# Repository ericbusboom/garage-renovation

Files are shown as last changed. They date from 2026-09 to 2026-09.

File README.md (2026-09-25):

# Garage Renovation

Working files for the garage renovation, including the controlled report, COMPAS structural data, analysis source, studies, drawings, visualizations, and renders.

| Directory | Purpose |
|---|---|
| `report/` | Controlled project report and document manifest |
| `studies/` | Dated one-off and versioned explorations |
| `data/` | COMPAS and project model data |
| `viz/` | Dated visualization releases; `viz/latest` selects the current one |
| `render/` | Dated Blender and other render packages |
| `plans/` | Approved drawings when available |
| `src/` | Active source code |
| `public/` | Static site for `garage.busboom.org` |
| `archive/` | Retained history and local tooling |

See [archive/reorganization-manifest.csv](archive/reorganization-manifest.csv) for the 2026-09-21 move record. Structural analyses in this repository are preliminary unless signed and sealed by the responsible engineer.

The current interactive frame is always available at
[`viz/latest/lean-to-frame-3d.html`](viz/latest/lean-to-frame-3d.html). Visualization
release directories use `YYYYMMDD.NN-<slug>`; see [`viz/README.md`](viz/README.md)
for revision and rollback rules.

The current large-format concept drawing set is
[`studies/20260924.02-concept-drawing-set/garage-concept-drawing-set.pdf`](studies/20260924.02-concept-drawing-set/garage-concept-drawing-set.pdf).
It combines the current frame and equipment layout with diagrammatic electrical,
Ethernet, dust-collection, and compressed-air routing. Approved drawing packages
will move to `plans/` only after review.

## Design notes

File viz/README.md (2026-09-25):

# Visualizations

Interactive and generated visualizations are published here as dated releases.
Release directories use the same naming scheme as studies:
`YYYYMMDD.NN-<slug>`.

The authoritative working release is always [`latest`](latest), a relative
symlink that can point to any retained release. Do not infer current status from
the largest version number or newest modification time. The current 3-D frame is:

- [Latest structural frame](latest/lean-to-frame-3d.html)
- [Release notes](latest/README.md)
- [Analysis results](latest/analysis.json)
- [Geometry](latest/geometry.json)

## Revision workflow

Small corrections to the active design regenerate files in the directory to
which `latest` points. A major geometry, analysis, or presentation direction
gets a new `YYYYMMDD.NN-<slug>` directory. Copy only the useful starting assets,
update that release's README and manifest, review it, and then repoint `latest`.

If a new direction is abandoned, leave its numbered directory for history and
repoint `latest` to the selected earlier release. This makes rollback explicit
and avoids treating the numerically newest release as automatically approved.

Keep `viz/` reviewable: one README and manifest per release, the visualization,
and the data needed to understand it. Solver experiments, intermediate options,
logs, screenshots, and development branches belong in `studies/` or `archive/`.
The superseded pre-versioning visualization tree is retained at
`archive/20260924.01-viz-cleanup/legacy-structural-analysis/`.

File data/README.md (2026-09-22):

# Data

- `frame-models/` contains COMPAS structural frame JSON files using the existing naming scheme.
- `model/` contains the project model, parameters, exchange files, and related model data.

Keep stable data filenames when source code or report provenance records refer to them. Put generated HTML and presentation outputs in `viz/` instead.

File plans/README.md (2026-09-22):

# Approved Plans

This directory is reserved for approved drawings, primarily orthographic, isometric, and two-dimensional plan material.

It is intentionally empty of drawings. The current controlled manifest contains no `reviewed`, `verified`, or `issued` drawing suitable for promotion here. Draft and exploratory drawings remain in `report/` or `studies/` with their existing status.

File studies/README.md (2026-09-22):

# Studies

One-off and versioned explorations live here. Directory names use `YYYYMMDD.NN-<slug>`, where the date identifies the study generation and `NN` distinguishes studies started on the same day.

Studies are working material. They do not become approved drawings or controlled design documents until promoted through `report/document-manifest.csv`.

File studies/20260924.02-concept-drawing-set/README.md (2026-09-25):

# Concept drawing set

This study assembles the current structural frame and equipment layout into one
large-format, multipage PDF for coordination and discussion. It is explicitly a
concept set, not a permit, fabrication, or construction package.

The sheets include:

- isometric, north, east, and south structural views;
- loft and ground-floor equipment plans;
- conceptual electrical distribution;
- conceptual Ethernet home runs; and
- conceptual dust collection and compressed-air distribution.

Regenerate from the repository root with:

```sh
archive/.venv/bin/python src/structural-analysis-v6/drawing_set.py \
  studies/20260924.02-concept-drawing-set/garage-concept-drawing-set.pdf
```

The MEP routes record proposed endpoints and zones. Final circuiting, conductor,
cable, pipe and duct sizing, clearances, supports, and code compliance remain to
be designed and verified.

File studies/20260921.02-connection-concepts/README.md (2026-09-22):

# Connection concept and model audit

**Status:** preliminary discussion basis; no connection is designed or approved for fabrication.

## What the current analysis actually assumes

The current lean-to/continuous-east-post model contains 127 physical members, 334 geometric nodes, 11 supports, and 38 short analytical links used to transfer load across offsets.

- 54 wood joists, 22 steel rafters, and 6 steel braces are pin-ended: 82 members and 164 released member ends.
- Two steel door-post heads and four support locations along `BE.upper` are explicitly released in addition to the group rules.
- All 11 modeled foundations are pinned bases: translation is restrained and rotation is free.
- Every other connected analytical member end transfers moment. This is a modeling assumption, not evidence that a weld, end plate, or moment connection has been designed.
- No bolt quantity, screw quantity, weld size, plate thickness, hole type, edge distance, block shear, local HSS wall, flange, anchor, or base-plate check exists.

The cost model counts 109 fitted steel ends and prices them as roughly 55 field-bolted connection locations. It also allows shop fitting and welding at steel ends and shop-welded end plates on 13 W-shape pieces. These are estimating allowances, not a connection schedule.

## A practical connection split

### Shop-welded lateral modules

The current explicit designation starts with two ground-to-floor longitudinal moment frames:

- west `BW` line: `BW`, `SW0`, `W1`, `W2`, `W3`, and `W4`;
- east `BE` line: `BE`, `E-S2`, `E-S3`, and `E-N2`.

These are the red members in the viewer. They are a design intent that still requires connection and foundation engineering; the red color does not mean their joints have already been checked. Use shop welding to make transportable frame modules where those lines need continuity, with deliberate field splices selected to suit erection and shipping.

The upper roof and clerestory members are not automatically included in those moment frames. Most are amber in the viewer because the solver presently transfers moment through them even though their lateral role has not been selected. Each amber end must be released, assigned to a braced bay, or deliberately designed as part of a moment-resisting frame.

Do not assume every intersection in these panels must be a full-strength moment weld. Diagonals can still terminate on shop-welded gusset plates with pinned analytical behavior. Chord-to-column or chord-splice locations that provide frame stiffness need explicit moment-connection design.

### Field-bolted simple connections

- Wood joists: proprietary hangers or designed ledgers/hangers; simple ends.
- Steel rafters: seated or shear-tab connections with positive uplift restraint and rotational freedom.
- Braces: bolted gusset plates, detailed so brace work lines meet at the joint.
- `BE.upper`: bolted simple shear/seat connections at its four supports, matching the existing releases.
- Door-post heads: bolted clip or knife plates that restrain translation while allowing the modeled rotation.
- Column bases: base plates and anchor rods designed as nominally pinned bases unless the lateral design deliberately changes them.

### Field splices between welded modules

Use bolted flange/web plates or end plates at deliberate shipping and erection breaks. These can be simple or moment-resisting, but the analysis must match the selected behavior. A connection should not be called “slip” if the structure relies on it to hold geometry: use a simple rotational connection, a bearing-type bolted joint, or a slip-critical joint as the actual load path requires. Slotted holes are useful for erection tolerance only where their allowed movement cannot create a mechanism or unload a brace.

## The main structural consequence

The current reduced-bracing model assumes moment continuity at all joints that are not explicitly released. Converting those remaining joints wholesale to simple bolted connections would remove stiffness that the H/414 drift result depends on. Before detailing, choose and model the lateral system explicitly:

1. identify the welded/moment-resisting frame planes;
2. keep gravity infill, rafters, joists, and brace gussets simple where possible;
3. place field splices to make the welded modules transportable and erectable;
4. rerun strength, drift, second-order, and pre-demolition stability with those releases;
5. design plates, bolts, welds, anchors, and HSS local reinforcement from the resulting connection forces.

The present force results support treating `BW` as an active lateral member: it is wind-governed under the `WX-.ni` combination, with about 137 kip-in of major-axis moment and a 0.515 checked ratio. The east `BE` beam is gravity-governed at 0.608, while its three designated posts are governed by earthquake or gravity combinations. That means the east red frame is an intentional stability/redundancy choice, not a classification inferred from `BE`'s governing load case.

There are 29 amber members. Until a released-joint rerun passes, the reported H/414 drift belongs to the current partly implicit rigid-joint model; it is not proof that the two red frames alone provide that stiffness.

## Pre-demolition correction

`B-S` and `E.top` clear the existing roof and remain in the early erection stage. `E.top` is shown with its real support chain: the continuous `E.clerestory` and `E.W3` east wall-line posts. Those posts require local work at the existing east eave, but they do not require removal of the roof field. The phase filter continues to prune an asserted member if its supporting members are absent, so `E.top` cannot appear as a floating beam.

The preferred fabrication direction is therefore **a small number of shop-welded lateral modules with many field-bolted simple attachments**, rather than welding the whole building together in the field or treating every joint as free to rotate.

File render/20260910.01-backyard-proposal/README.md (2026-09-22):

# Backyard with proposed hip-cap garage

This proposal starts from the exact `backyard-existing.blend` embedded in the supplied `backyard-blender/Backyard-Blender-Package.zip`, rather than the older approximate garden scene.

The source backyard remains intact except for removal of its existing garage roof. Proposed columns, beams, upper walls, loft floor, balcony and current roof are inserted from `garage-model.json`. Both models use metres, X east, Y north, Z up, with the same southwest garage origin, so no translation or rescaling is applied. The lower garage walls and original work shelter are retained without duplicate geometry.

The rear hip cap rises 18 inches above its eaves with an 8-inch overhang and white soffit/fascia. Proposed structural sizes and connections remain conceptual. The combined model exposes spatial relationships; it does not establish foundations, load capacity or clearance compliance.

## Contents

- `backyard-proposed-hip-cap.blend`: editable Blender scene, with packed baseline photographic textures and named PROPOSED collections.
- Three PNG renders: whole-yard overview, patio toward garage, elevated west.
- `build_proposal.py`: inserts the proposal into the baseline and reproduces all three renders with Blender 5.
- `backyard-existing.blend`: unchanged source scene extracted from the supplied ZIP.
- `garage-model.json`: current proposed garage mesh geometry, materials and dimensions.
- `validation.json`: source hash, removed roof object names, added object count and coordinate basis.

Run `blender -b -t 12 --python build_proposal.py` from this directory. Rendering uses Cycles CPU, 80 samples with denoising, 1800 × 1350 pixels. The original backyard package is preserved separately. The backyard itself remains a reviewed visual reconstruction, with the dimensions and limitations documented in the original package; it is not a survey.

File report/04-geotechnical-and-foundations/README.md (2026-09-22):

# 04 — Geotechnical and Foundations

This section establishes the ground conditions and parameters needed to design new columns, piers, footings, slabs, and any retained foundation reliance. It must address fill, expansive soil, groundwater, settlement, lateral resistance, uplift, corrosion, mapped hazards, excavation, and drainage as applicable.

Early assumptions such as 18-inch-diameter by 36-inch-deep piers are not design values.

## Required outputs

- geotechnical report or documented City-acceptable basis for not requiring one
- foundation design criteria
- excavation, observation, testing, and special-inspection requirements
- foundation schedule coordinated with structural reactions

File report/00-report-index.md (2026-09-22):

# Garage Rebuild — Master Report Index

**Project:** Garage rebuild and loft/solar superstructure  
**Site:** 1370 Wilbur Avenue, San Diego, CA 92109  
**Document status:** Draft report framework  
**Purpose:** Design development, professional coordination, permitting, bidding, construction, and closeout  
**Last updated:** 2026-09-21

## How the document set works

The report has three layers:

1. **Project record:** decisions, assumptions, existing conditions, analyses, and design narrative.
2. **Permit and construction set:** coordinated drawings, specifications, calculations, and agency responses prepared for a stated issue.
3. **Record documents:** approved permits, inspections, submittals, testing, warranties, and as-built information.

The Markdown index is the navigable table of contents. PDFs and images provide fixed review copies. Native CAD and exchange models provide editable geometry. The manifest records status and provenance for every controlled artifact.

The project workspace was reorganized on 2026-09-21 into `report/`, `studies/`, `data/`, `viz/`, `render/`, `plans/`, `src/`, and `archive/`. This changed file locations and provenance links only; it did not change the status or technical conclusions of any controlled document.

## Table of contents

| Section | Content | Principal outputs | Current state |
|---|---|---|---|
| [00 Project controls](00-project-controls/) | Document requirements, decisions, assumptions, open issues, revision and issue history | Registers, responsibility matrix, issue checklist | Draft framework |
| [01 Project definition](01-project-definition/) | Owner goals, scope, selected scheme, performance criteria, budget, exclusions, success measures | Project brief, basis of design, room/use schedule | Planned |
| [02 Existing conditions](02-existing-conditions/) | Boundary/topographic survey, measured garage, photos, utilities, power lines, drainage, vegetation, condition assessment, permit history | Survey, existing plans/sections, photo log, utility plan, hazardous-material screening | Source candidates identified; unverified |
| [03 Land use and permitting](03-land-use-and-permitting/) | Parcel data, title/easements, base zone, community plan, coastal and other overlays, setbacks, height, lot coverage/FAR, parking/use, permit path | Zoning and code summary, parcel/overlay exhibit, permit matrix, agency meeting record | LAND-005 draft findings completed; survey and agency interpretations pending |
| [04 Geotechnical and foundations](04-geotechnical-and-foundations/) | Geologic hazards, soil/fill conditions, investigation need, bearing/lateral criteria, excavations, new piers/footings, existing slab limitations | Geotechnical report or waiver basis, foundation criteria, footing/pier schedule | Planned |
| [05 Architectural design](05-architectural-design/) | Selected massing, floor plans, roof plan, elevations, sections, doors/windows, balcony/loading opening, access, finishes | Design narrative, dimensioned drawing set, door/window/finish schedules, renderings | ARCH-006 rev 4: floor-plan and east-wall study; draft |
| [06 Structural engineering](06-structural-engineering/) | Design criteria and loads, load paths, global analysis, truss/beam/column design, trolley/hoist effects, connections, foundations, temporary stability | Structural basis, calculations, framing plans, member and connection schedules | STR-007 rev 0: frame FEA, gravity, wind and seismic screening; STR-006 geometry retained |
| [07 Building envelope](07-building-envelope/) | Integrated solar roof, low hip cap, metal wall panels, waterproofing, flashing, drainage, insulation, condensation, ventilation, fire exposure | Envelope sections/details, product requirements, drainage plan | ENV-003 rev 0: wall panel options research; draft |
| [08 Solar, electrical, and energy](08-solar-electrical-and-energy/) | Solar resource, array geometry, PV/ESS sizing, production, tariff/economics, one-line, equipment and interconnection | Energy report, array layout, electrical one-line, equipment schedule, utility/permit documents | SOL-001 rev 1: consolidated solar/battery report and 30°/35°/40° analysis; draft |
| [09 MEP and life safety](09-mep-and-life-safety/) | Electrical distribution, lighting/receptacles, ventilation, any mechanical/plumbing, alarms, egress, guards, fire separation, exterior access | MEP/life-safety plans, schedules, code analysis | Planned |
| [10 Construction planning](10-construction-planning/) | Existing-roof retention sequence, demolition, temporary bracing/shoring, access, crane/hoist operations, neighbor/site protection, inspections | Phasing drawings, temporary works criteria, logistics plan, inspection/test plan | Preliminary feasibility studies exist |
| [11 Cost, schedule, and procurement](11-cost-schedule-and-procurement/) | Quantity takeoff, alternatives, fabrication/erection strategy, allowances, contingency, schedule, long-lead items | Estimate, bid scope, schedule, procurement register | Planned |
| [12 Permit and construction set](12-permit-and-construction-set/) | Coordinated issued drawings, specifications, calculations, forms, deferred submittals, plan-check responses | Permit issue and construction issue packages | Not started |
| [13 Record documents](13-record-documents/) | RFIs, submittals, substitutions, inspections, tests, change record, as-builts, commissioning, warranties | Closeout and owner record package | Future |
| [Appendices](appendices/) | Source register, calculations/data supporting the narrative, meeting notes, selected option comparisons | Reference material with provenance | Planned |
| [Deliverables](deliverables/) | Frozen, coordinated packages assembled for a named issue | ZIP/PDF/model packages and checksums | Empty by design |

## Chapter 3 research record

[LAND-005 — Setbacks, retained garage, and proposed storage roof](03-land-use-and-permitting/setbacks-and-roof-findings.md), revision 0, 2026-09-15, status `draft`. The 15-foot side-strip roof is a conditional option requiring City interpretation, not an approved limit for this project.

[LAND-006 — Extending the garage along the existing 1-ft side setback](03-land-use-and-permitting/setback-extension-research.md), revision 0, 2026-09-20, status `draft`. Two code routes allow the 1-ft line to continue, but nothing above one story may sit inside the setback under either.

## Required professional contributions

The exact contracting arrangement remains open, but a complete package is expected to need these roles:

| Role | Expected responsibility |
|---|---|
| Owner | Program, storage and equipment loads, budget, operational constraints, decisions |
| Architect or residential designer | Code/zoning coordination, architectural plans and details, consultant coordination |
| California-licensed land surveyor or civil engineer | Property boundary, topography, improvements, easements and survey control |
| California-licensed structural engineer | Structural design, existing-condition reliance, foundations, connections, temporary stability |
| Geotechnical engineer/geologist, if required | Soil/geologic investigation and design parameters |
| Electrical/solar designer and contractor | PV, ESS, service/load study, one-line, equipment, interconnection |
| Civil/drainage professional, if triggered | Grading, drainage, stormwater, utility work |
| Arborist, if tree work or protected/public trees are affected | Tree condition, root/canopy impacts and protection plan |
| General contractor and fabricator/erector | Constructability, sequencing, cost, shop drawings and field verification |

## Immediate collection priorities

1. Obtain a boundary/topographic survey showing the garage, house, outbuilding, property lines, easements, grades, trees, overhead/underground utilities, and adjacent improvements.
2. Obtain the City parcel/zoning/overlay report and permit history for the address; verify the owner-stated 5-foot setback before fixing the building envelope.
3. Obtain the building/fire classification for the owner-confirmed upstairs storage use; document loads and access requirements.
4. Complete a measured existing-condition set and structural condition assessment, including the slab, walls, foundations, roof framing, and prior lofts.
5. Confirm whether a geotechnical investigation is required and establish design parameters for every new column footing or pier.
6. Freeze one architectural scheme and one coordinated structural grid before promoting CAD files to the report.
7. Establish roof, loft, equipment, hoist, wind, seismic, and construction loads in a signed structural design basis.
8. Coordinate drainage, waterproofing, fire separation, ventilation, egress, balcony/loading opening, PV, ESS, and utility clearances.

## Current design direction — owner-provided, not yet issued

The working direction is a lightweight steel superstructure constructed around the existing garage, with an upper storage level, integrated south-facing solar roof, low hipped rear cap, exposed exterior steel frame, and metal wall panels placed inside the frame. The design includes concentrated equipment storage and a nominal 1,000-pound trolley/hoist requirement. The owner confirms all existing garage walls remain exterior and new posts stand over open ground-level walkways. Geometry, legal occupancy classification, loads, member sizes, foundations, and construction sequence remain subject to coordination and professional design.

## Regulatory note

Current City guidance indicates that structural work supporting PV and construction of a new or modified accessory structure requires building review in addition to electrical requirements. City guidance also makes the need for a geotechnical investigation dependent on code triggers, mapped hazards, fill/expansive soil, and field conditions. Exact zoning, coastal status, setbacks, height, and other parcel controls must be verified for this address before design criteria are treated as fixed.

## Chapter 8 research record

[SOL-001 — Solar, battery and roof design](08-solar-electrical-and-energy/solar-energy-report.pdf), revision 1, 2026-09-15, status `draft`. Includes all recovered solar figures, historical reports, monthly data, new pitch and loft-envelope comparisons, battery dispatch and financial sensitivity. The current 325 ft² face supersedes the older 401 ft² area assumption for this study. Recommendation for review: about 5.6–6.0 kW plus one 13.5 kWh battery; develop 35° while retaining 30° as the height-constrained alternative. [Chapter navigation and source archive](08-solar-electrical-and-energy/README.md).

## Chapter 5 floor-plan study

[ARCH-006 — Combined floor plan study](05-architectural-design/floor-plan-study/floor-plan-study.pdf), revision 4, 2026-09-15, status `draft`. One plan shows the structure, columns, possible ground-floor extension, north door bay and optional east-wall framing. [Editable drawing and source notes](05-architectural-design/floor-plan-study/README.md). Duplicate sheets and old report copies removed at owner request; current generator: `../studies/20260915.04-floor-plan-setbacks/draw_floor_plan_study.py`.

## Chapter 6 frame geometry study

[STR-006 — Coordinated frame geometry study](06-structural-engineering/frame-geometry-study/README.md), revision 0, 2026-09-15, status `draft`. [3D viewer](06-structural-engineering/frame-geometry-study/model-3d.html) · [Drawing and truss study PDF](06-structural-engineering/frame-geometry-study/frame-geometry-study.pdf). Includes the far-west truss correction, all 13 columns, east transverse links and E-OB; model data and schedules are saved for subsequent engineering. Section sizes, loads, foundations and joint design remain unresolved.

## Chapter 6 frame finite element analysis

[STR-007 — Frame finite element analysis and member optimisation study](06-structural-engineering/fea-study/structural-analysis.md),
revision 0, 2026-09-18, status `draft`.
[Interactive 3-D model](06-structural-engineering/fea-study/fea-model-3d.html) ·
[Design load basis](06-structural-engineering/fea-study/design-load-basis.md) ·
[Member schedule](06-structural-engineering/fea-study/member-schedule.csv).

First analysis of the frame against design loads: 27
ASCE 7-16 combinations covering gravity, 96 mph wind
from four directions, and a seismic screening check. Vertical equilibrium closes
exactly and member capacities reconcile with the AISC Manual.

Three blocking findings. The flat upper roof has no framing across it and the
clerestory head has no beam, so the frame as drawn cannot carry its roof. One
column is connected only by a bearing joint carried on no member. Six X-brace
crossings are not declared joints, and connecting them alone drops the worst
utilisation from 4.46 to 1.56 at no
material cost. The loft joists fail at the code storage live load of 125 psf
though they pass at the project's assumed 40 psf, which makes the occupancy
classification a structural question.

No connection, base plate, anchor or foundation is designed or checked.
Preliminary engineering only; not for construction.

## Chapter 6 cost reduction

[STR-008 — Frame cost reduction study](06-structural-engineering/cost-reduction/cost-reduction-study.md),
revision 1, 2026-09-18, status `draft`.
[Interactive 3-D model, true section sizes](06-structural-engineering/cost-reduction/cost-reduction-3d-solid.html).

Scores changes to the frame in dollars rather than pounds, on the project's own
procurement rates. Steel is $0.77–0.94/lb, so weight is the cheapest thing in the
frame; fitted joints are $16–39 each and each distinct section carries $150–400 of
procurement. The verified package removes 14 steel members and collapses eleven
distinct sections to five: 59 pieces instead of 73, 106 joints instead of 135,
**$5,630**, with the frame at 0.951 of capacity and wind drift improved to H/514.

**No floor joist can be deleted** — at 15.4 in. centres any deletion exceeds the
24 in. span of the OSB deck. Fewer joists is available only by re-spacing to
2×10 at 24 in., worth about $1,000 and requiring its own verification. Revision 0
proposed deleting 33 joists in error; see §11 of the study.

## Chapter 7 wall panel research

[ENV-003 — Infill wall panel options](07-building-envelope/wall-panel-options/wall-panel-options.md), revision 1, 2026-09-17, status `draft`. Owner-directed survey of metal, translucent, glazed and non-metal infill materials, with installed-cost ranges, the continuous-face versus bay-infill attachment decision, and whether the panels should be recruited for lateral stiffness. [Study notes and findings](07-building-envelope/wall-panel-options/README.md).

Four findings bear on decisions already recorded. Insulated metal panels cannot act as shear walls, so retaining the current 2-inch IMP basis closes the rigidity question in favour of the frame. No bay clear width is a whole multiple of any standard panel width, so tongue-and-groove products suit continuous inside-face installation rather than bay-by-bay infill. Published Galvalume warranties exclude sites within 1,500 feet of salt water, which may disqualify the default substrate at this address and makes painted aluminum the warrantable choice. The 5/8-inch Type X drywall in the working estimate may also be serving as the Chapter 26 thermal barrier and should not be deleted as redundant insulation. Raises ENV-OI-01 through ENV-OI-08. No product is selected and no price is a quotation.

Revision 1 carries the coastal-corrosion finding through to the roof (study section 8A). The standing seam in [COST-ESTIMATE.md](../COST-ESTIMATE.md) item G names no substrate, and Galvalume is what its $6.00-9.00/sq ft price point implies. The roof is the harder case: it is the outermost surface, roughly 84% of the south face sits under PV modules where rain never rinses the salt away, and panels under a fixed array cannot be replaced without removing the array. Position for review is painted aluminum with a coastal-rated paint warranty, 316 stainless clips and fasteners, aluminum or stainless gutters, non-penetrating seam clamps, and isolation pads at dissimilar-metal contacts, at a roof-subtotal delta of roughly $1,065-2,397. Adds ENV-OI-09 through ENV-OI-12.

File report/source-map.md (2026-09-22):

# Working Source Map

This map points to useful material in the workspace. It does **not** declare these files current, verified, or approved. Promote only after coordination under the report README.

| Subject | Working location | Candidate material | Caution |
|---|---|---|---|
| Existing garage CAD | `../data/model/` | `garage.FCStd`, `garage-existing.step`, parameters and validation | Field dimensions and current completeness require review. |
| Existing backyard/site | `../render/20260908.01-existing-site/` | `existing-backyard.FCStd`, `site-plan.png`, `site-review.pdf`, tree/site images | Model is photo-derived/working geometry, not a boundary survey. |
| Current exposed-frame concept | `../studies/20260911.01-structural-optimization/exposed-frame/` | `Garage-Exposed-Steel.FCStd`, STEP, Blender model, two renders | Preliminary member selections and geometry; coordinate with current roof concept. |
| Roof options | `../studies/20260915.01-roof-options/` | `south-post-solar-clerestory.*`, west elevation options | Alternatives and recent concept work; no permit status. |
| Structural optimization | `../studies/20260911.01-structural-optimization/` | candidate reports, network analysis, truss submodels | Multiple iterations exist. Do not promote by filename or date alone. |
| Truss analyses | `../studies/20260908.03-structural-analysis-v3/`, `../studies/20260909.02-structural-analysis-v5/` | design images, load plans, calculations, CSV/JSON results | Preliminary; geometry and connections have changed; professional validation required. |
| Construction sequence | `../studies/20260909.03-construction-sequence/`, `../studies/20260909.04-roof-first-feasibility/` | roof-clearance and staged T1 studies | Feasibility studies only; temporary works require engineered design. |
| Solar/energy | `../studies/20260915.03-solar/optimization/results/` | optimization PDF, charts, CSVs, summary JSON | Update tariff, costs, final roof geometry, shading, equipment, and consumption data before issue. |
| Site-context renders | `../render/20260908.02-backyard-existing/`, `../render/20260910.01-backyard-proposal/`, `../render/20260908.03-garage-site/`, `../render/20260907.01-site-concepts/` | Blender packages and renderings | Illustrative; several generations of building design exist. |
| Wall panel and glazing research | (desk research, no working directory) | `../report/07-building-envelope/wall-panel-options/` | Published manufacturer and trade sources accessed 2026-09-17. Prices are market ranges, not quotations. No samples, mockups or quotes obtained. |
| Published wiki | `../archive/wiki-publish/` | HTML content and copied deliverables | Publication mirror/archive; not the design source of truth. |

## Candidate files for first coordinated package

The following are useful starting points, but none are automatically accepted as the current deliverable:

- Existing reference model: `../data/model/garage.FCStd` and `../data/model/garage-existing.step`
- Proposed-frame editable model: `../studies/20260911.01-structural-optimization/exposed-frame/Garage-Exposed-Steel.FCStd`
- Proposed-frame exchange model: `../studies/20260911.01-structural-optimization/exposed-frame/Garage-Exposed-Steel.step`
- Recent roof concept drawing: `../studies/20260915.01-roof-options/south-post-solar-clerestory.pdf`
- Preliminary solar report: `../studies/20260915.03-solar/optimization/results/Garage-Solar-Optimization.pdf`
- Preliminary truss calculation package: `../studies/20260908.03-structural-analysis-v3/truss-design-and-calculations.pdf`

Before promotion, reconcile the proposed-frame CAD with the selected roof, current truss geometry, loft dimensions, openings, balcony/loading concept, and latest structural load model.

## Chapter 3 research provenance

LAND-005 is the draft synthesis at `03-land-use-and-permitting/setbacks-and-roof-findings.md`. Its source table records official references and access dates; its local-source list identifies the inspected studies. These links do not promote the working drawings or certify their dimensions.

## Consolidated solar record

SOL-001 revision 1 is now assembled in [Chapter 8](08-solar-electrical-and-energy/README.md). Its source archive preserves the solar studies and related roof-option sources, with a checksummed inventory. Reproduction code is in `../studies/20260915.03-solar/chapter8/`. Historical capacity estimates based on about 401 ft² do not establish fit on the newer 325 ft² solar face.

## Floor-plan study provenance

[ARCH-006 — Combined floor plan study](05-architectural-design/floor-plan-study/floor-plan-study.pdf), revision 4, 2026-09-15, status `draft`. One plan shows the structure, columns, possible ground-floor extension, north door bay and optional east-wall framing. [Editable drawing and source notes](05-architectural-design/floor-plan-study/README.md). Duplicate sheets and old report copies removed at owner request; current generator: `../studies/20260915.04-floor-plan-setbacks/draw_floor_plan_study.py`.

## Coordinated frame geometry provenance

STR-006 revision 0 is saved in [Chapter 6](06-structural-engineering/frame-geometry-study/README.md). Working generators and pinned dependencies remain in `../studies/20260917.01-compas-frame/`; the report source inventory records their hashes and those of the floor-plan basis, framing register, original model and dimension sources. Owner-directed corrections in STR-006 develop ARCH-006 but do not revise that earlier architectural sheet.

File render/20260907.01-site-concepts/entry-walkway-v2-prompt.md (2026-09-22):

# Entry and covered walkway revision

Built-in image_gen edit. Output: flat-cap-balcony-entry-v2.png. White covered walkway geometry is approximate because vegetation conceals it in reference photos. Ground-floor entry replaces the extra south window in v1. CAD remains unchanged.

Use case: precise-object-edit. Revise input1 architectural garden rendering with ONLY the missing ground-floor pedestrian door and existing white covered walkway. Input2 and3 are original site photographs for supporting context, NOT roof-design references. Preserve input1 exactly in all other respects: flat rear roof cap, solar slope, balcony and upper French doors, single offset natural wood west beam row, sloping lattice, blue-gray paint, garden, lighting, neighboring buildings, wires, perspective and composition.
On the SOUTH wall, the right-facing visible ground-floor facade directly below the solar roof, there are erroneously TWO windows in input1. Retain the LEFT window of these two near the corner; replace the RIGHT window with a normal single ground-floor pedestrian entry door, white-painted with simple white trim, about32inwide80inhigh, its lower portion naturally concealed by foreground plants. This is separate from the upper balcony French doors which stay unchanged.
Restore a modest WHITE COVERED WALKWAY by this ground-floor door extending to the RIGHT behind the dense bushes, consistent with partly visible existing pale support structure among the bushes in the site photos. Simple narrow white-painted canopy with white posts and beams and a lightly pitched solid pale cover at ground-floor eave level, lower than the main solar roof. Its near end shelters the entry and its continuation disappears behind existing greenery to image right. It is NOT the natural timber lattice on the left west side; keep those distinct. Do not clear shrubs for visibility, do not invent a large veranda or wide porch, no new paving, no new wing or room. Show just enough white canopy fascia and supporting post glimpses to convey a sheltered path behind bushes. Treat concealed dimensions as conceptual approximation. No added text, labels, dimensions or watermark. One photorealistic landscape image matching input1.

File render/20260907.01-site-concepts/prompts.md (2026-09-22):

# Garage site appearance studies

Built-in image_gen tool; compositing mode. Selected direction: flat rear cap; continuous-slope option dropped. Current image: flat-cap-balcony-v1.png.

Current concept uses one west post/beam row 32 inches from the existing wall, replacing both prior rows. Interpretation for this preview: lattice projection reduces to 32 inches as well. Balcony is a tentative shallow ornamental plant balcony, about 18 inches deep and 5 feet wide, with French doors at the northern end of the west loft wall. These balcony dimensions are visualization assumptions, not user-approved dimensions.

Photographic concepts are approximate. The generated image retains an extra south window and stylizes roof fascia; neither is an approved change to the measured model. Existing CAD and prior dimensioned roof studies have not been revised for this new concept.

## Current rendering prompt

Use case: compositing. Produce one revised photorealistic garden-view concept rendering of a garage remodel.
Input 1 is an earlier on-site rendering, EDIT TARGET. Preserve its camera, garden, bench, paths, trees, camper, neighboring buildings, sky, power lines, and garage footprint. Input 2 is the authoritative roof GEOMETRY reference, not a site background. Input 3 is the original site photo, authoritative for existing lower window positions. Input 4 is house style reference, blue-gray exterior and white French doors/trim.
The client SELECTS ONLY the flat rear cap roof concept. Correct the earlier rendered silhouette: the broad south-facing solar roof rises at30degrees from the low front/south eave, then visibly breaks into a nearly flat roof across the BACK northernmost6ft6in. NOT a continuous shed wedge, NOT a gable, NOT a tiny ridge cap. Reference2 shows this exactly. The left silhouette must have two distinct segments: shallow rear cap over about one third the north-south depth, then30degree south slope. Roof maxheight about19ft4in; existing walls8ft2.5in. Keep low south roof starting on beam23.25in beyond south wall and north upper wall/roof6in beyond existing northwall.
Requested changes to WEST side (left visible wall):
Replace BOTH old parallel north-south post/beam rows with ONE longitudinal timber post/beam row, centered32in outward from existing WEST garage wall. Delete the old row directly against west wall and old row5ft out. Show only ONE offset row, reducing the projection to32in in this concept. Beam at existing wall-top region; open2x2 sloping trellis members6–8in apart rise inward from this single beam to roof. NO solid canopy roof.
Break up the tall blank loft cheek wall with a shallow ornamental plant balcony and a pair of white painted French doors opening from loft. Place doors in the taller NORTHERN / BACK portion of the west wall beneath the flat cap, where door height fits, NOT low southern roof. A modest about5ftwide and18in deep Juliet-style plant balcony with slender dark metal vertical railing and planters of trailing greenery. Balcony floor at loft floor level about9ft above grade. Keep balcony and doors visually accessible, interrupt local trellis in front of balcony so slats do not block doors, while retaining trellis on the remaining west elevation. No people, no huge terrace, no ground-floor French doors. Blue-gray horizontal siding on the upper cheek wall, blue-gray stucco below, white door/window trim and fascia; warm wood frame and lattice. Lower windows follow original site photo: two on LEFT westwall, ONE on right southwall, do not duplicate windows. Preserve existing garden plants and other site details.
Photorealistic architectural appearance study with realistic shadows, matching original natural light. One landscape image, no labels/text/dimensions.

## Earlier option A prompt

Use case: compositing. Create a photorealistic on-site architectural concept rendering.
Input 1 IMG_4201.jpg is the EDIT TARGET: preserve its exact garden camera position, framing, paving, bench, foreground leaves, plants, camper at left, wood outbuilding at left, tan neighboring house and overhead utility wires. Replace only the white garage with gray hip roof at center-right with the proposed remodeled garage, retaining its existing ground floor footprint and window positions.
Input 2 IMG_4198.jpg and input 3 IMG_4200.jpg are HOUSE STYLE references ONLY: blue-gray painted stucco, blue-gray horizontal lap siding, crisp simple white fascia/window trim, charcoal roofing. Do not insert these houses into the scene.
Input 4 is GEOMETRY reference of the proposed garage seen from southwest, same approximate direction as site camera but elevated. Translate this precise roof and sloping open lattice form into the site photo's lower camera perspective.
Orientation: the garage's left visible face with TWO small windows is WEST; right visible face with ONE small window is SOUTH (entry door may be obscured by vegetation). North is back away from camera. Solid solar roof is low at south/front and rises toward north/back. No conventional gable or pyramid.
Existing walls are 8ft 2.5in tall and approximately 20ft9in square. New frame wraps outside them. South roof starts on outer beam 23.25in beyond existing south wall; north roof and upper loft wall extend 6in beyond existing north wall. West OPEN sloping lattice covers a 5ft walkway outside existing west wall, anchored on posts and a low outer beam around 8ft10in above ground and rising inward to west edge of solid roof. Thin 2x2 wood lattice members 6-8 inches apart; daylight clearly visible through lattice, never a solid roof. Closed blue-gray upper loft wall behind lattice at existing west wall plane. Preserve original small ground floor windows. Main broad central roof faces SOUTH with flush dark solar panels, narrow steep eastern roof plane taking max 3ft at north side, largely hidden from this camera. Keep roof proportions from geometry reference. Finish lower garage stucco blue-gray matching house, upper loft cheek wall blue-gray horizontal siding, clean white fascia and white window trim; exposed frame and lattice warm natural wood. Roofing charcoal gray, no new dormers, balconies, large glazing, or extra floors. Preserve lush site plants and natural afternoon illumination, realistic material detail, shadows and perspective. No text, labels, dimensions, collage, or watermark. Output one landscape image.
VARIANT A: exactly the roof in input 4: south-facing 30 degree roof over front portion, transitioning to a nearly flat cap over the northernmost 6ft6in. Maximum roof height about19ft4in above ground. The rear cap is a broad shallow roof segment, not a second pitched face or ridge. Preserve the geometry reference's distinctive broken west roof edge and lattice, which follows the main slope then rear shallow cap.

## Dropped option B prompt

Use case: compositing. Create a photorealistic on-site architectural concept rendering.
Input 1 IMG_4201.jpg is the EDIT TARGET: preserve its exact garden camera position, framing, paving, bench, foreground leaves, plants, camper at left, wood outbuilding at left, tan neighboring house and overhead utility wires. Replace only the white garage with gray hip roof at center-right with the proposed remodeled garage, retaining its existing ground floor footprint and window positions.
Input 2 IMG_4198.jpg and input 3 IMG_4200.jpg are HOUSE STYLE references ONLY: blue-gray painted stucco, blue-gray horizontal lap siding, crisp simple white fascia/window trim, charcoal roofing. Do not insert these houses into the scene.
Input 4 is GEOMETRY reference of the proposed garage seen from southwest, same approximate direction as site camera but elevated. Translate this precise roof and sloping open lattice form into the site photo's lower camera perspective.
Orientation: the garage's left visible face with TWO small windows is WEST; right visible face with ONE small window is SOUTH (entry door may be obscured by vegetation). North is back away from camera. Solid solar roof is low at south/front and rises toward north/back. No conventional gable or pyramid.
Existing walls are 8ft 2.5in tall and approximately 20ft9in square. New frame wraps outside them. South roof starts on outer beam 23.25in beyond existing south wall; north roof and upper loft wall extend 6in beyond existing north wall. West OPEN sloping lattice covers a 5ft walkway outside existing west wall, anchored on posts and a low outer beam around 8ft10in above ground and rising inward to west edge of solid roof. Thin 2x2 wood lattice members 6-8 inches apart; daylight clearly visible through lattice, never a solid roof. Closed blue-gray upper loft wall behind lattice at existing west wall plane. Preserve original small ground floor windows. Main broad central roof faces SOUTH with flush dark solar panels, narrow steep eastern roof plane taking max 3ft at north side, largely hidden from this camera. Keep roof proportions from geometry reference. Finish lower garage stucco blue-gray matching house, upper loft cheek wall blue-gray horizontal siding, clean white fascia and white window trim; exposed frame and lattice warm natural wood. Roofing charcoal gray, no new dormers, balconies, large glazing, or extra floors. Preserve lush site plants and natural afternoon illumination, realistic material detail, shadows and perspective. No text, labels, dimensions, collage, or watermark. Output one landscape image.
VARIANT B: exactly the roof in input 4: one continuous 30 degree south-facing roof from low south edge all the way up to the north/back edge, NO flat cap and NO ridge turning down. Maximum north roof height about22ft11in above ground, roughly 2.8 times existing ground floor wall height. Preserve the geometry reference's straight rising west roof edge and tall sloping open lattice, panels flush on the solid central south-facing roof. The high end is behind the building from this garden viewpoint, so silhouette must rise away from camera.

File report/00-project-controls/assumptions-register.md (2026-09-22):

# Assumptions Register

These inputs allow work to proceed but are not verified project facts.

| ID | Assumption | Used for | Risk if wrong | Closure method | Status |
|---|---|---|---|---|---|
| ASM-001 | The garage-door side is north and the opposite wall is south. | All current plans and narratives | Mirrored or misoriented design and solar geometry | Boundary/topographic survey and field compass/GIS check | Open |
| ASM-002 | Existing wall height is 8 ft 2.5 in. | Existing/proposed vertical geometry | Conflicting elevations and construction clearance | Field survey from common datum | Open |
| ASM-003 | Existing wall assembly is approximately 6 in. thick plus about 1/2 in. exterior stucco. | Existing model and interfaces | Misfit at supports, flashing, doors/windows | Selective field measurement | Open |
| ASM-004 | Standard alley calculation suggests 5 ft on-site; owner estimates existing alley clearance at 6 ft 10 in. Applicability is conditional (LAND-005). | North expansion/loading-door studies | Zoning or coastal noncompliance | Licensed survey plus City parcel/zoning/overlay determination | Open |
| ASM-005 | New exterior columns may use roughly 18-in-diameter, 36-in-deep concrete piers. | Early structural models | Inadequate bearing, uplift, lateral or seismic resistance | Geotechnical criteria and engineered footing design | Open; do not size from this assumption |
| ASM-006 | Loft design includes 40 psf general live load, localized equipment loads, and a 1,000-lb hoist/trolley demand. | Preliminary structural studies | Member/connection/foundation undersizing or excess cost | Final equipment/usage plan and engineer's load criteria | Superseded in part by DEC-014: the uniform live load is now 100 psf. The 1,000-lb hoist demand stands; concentrated equipment loads move to ASM-011 |
| ASM-007 | Roof and walls will use lightweight steel framing/cladding with integrated-looking PV. | Mass and cost studies | Changed gravity/seismic loads and envelope details | Product selection and coordinated assembly schedule | Open |
| ASM-008 | Roof is unshaded for solar purposes. | Energy model | Production overestimate | Surveyed shade/obstruction study and solar model | Open |

| ASM-009 | Existing interior-side wall clearance is approximately 12 inches; preliminary upper-wall setback is 48 inches. | LAND-005 three-foot roof-strip example | Roof and wall geometry may intrude into required yard | Survey and written zoning determination | draft |
| ASM-010 | A 15-foot roof height within the setback is used only as a conditional study option. | LAND-005 pitch table | Exception may not apply to combined garage/storage configuration | Written City response with dimensioned section and gross-floor-area schedule | draft |

| ASM-SOL-01 | SOL-001 uses 325 ft² gross solar face, 281.5-in width, 249-in wall length, 63-in south offset, 9-ft low edge, 9-ft-8-in floor and 17-ft-8-in cap eave. | Angle/loft comparison | CAD generations or surveyed envelope may differ | Coordinate survey and selected roof/CAD; reconcile OI-016 | draft |
| ASM-SOL-02 | One 13.5 kWh battery, 10% reserve, 90% round-trip efficiency, 5 kW charge/discharge limit, perfect-foresight solar-only dispatch; retained tariff and cost allowances. | SOL-001 comparative economics | Actual equipment controls rates and cost differ | Vendor design plus interval-data and actual-tariff rerun | draft |

| ASM-FP-01 | ARCH-006 uses the earlier 249.5 × 249 in existing footprint, 4-in post symbols, provisional 8-in beam width, owner-stated 12/82 in clearances and requested 48/60 in east/north limits plus 27 in north overhang. | Floor-plan and wall-support discussion | Survey, member sizing or regulatory review may change the geometry | Resolve OI-016 and coordinate surveyed faces, member widths and permits | draft |

| ASM-STR-01 | STR-006 uses common column-top/truss-bottom Z98.5, 4-in column symbols, 3-in beam/chord display envelopes, loft Z107.25 and the older 30-degree roof profile. | Coordinated geometry and 3D visualization | Actual member depths, elevations, roof choice and load paths may differ | Field verification and engineer-selected sections/datum; reconcile architectural and solar studies before analysis | draft |
| ASM-011 | Concentrated equipment loads on the loft are enveloped by the 100 psf uniform live load. | STR-007 loft framing check | A dense item on a small footprint exceeds any uniform value locally -- an 800-lb machine on 3 sq ft is about 270 psf on that patch -- and can overload a joist the room average suggests is fine | Owner schedule of heavy items with weights and footprints, then a concentrated-load check per ASCE 7-16 Sec. 4.4 | Open; do not finalise loft framing from the uniform load alone |

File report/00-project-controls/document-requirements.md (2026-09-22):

# Document Requirements and Acceptance Criteria

This is the content specification for the project report. It distinguishes a useful design-development archive from a package that can support professional review, permitting, bidding, construction, and closeout.

## 1. Project definition and design basis

Required content:

- owner program and intended legal use of every level and outdoor area;
- project scope, demolition scope, retained construction, and work by others;
- adopted dimensions, elevations, orientation, property datum, and coordinate system;
- occupancy, construction type, fire-sprinkler status, accessibility applicability, and code editions, as determined by the design professional;
- performance criteria for storage, equipment, hoist/trolley, solar generation, weather protection, ventilation, durability, appearance, cost, and construction sequence;
- explicit exclusions and future work;
- decision log, assumptions register, open-items register, and design responsibility matrix.

Acceptance: the selected scheme and every controlling criterion are identifiable without reading chat history.

## 2. Site survey and existing conditions

Required content:

- signed boundary/topographic survey with benchmarks and property corners;
- lot dimensions, easements, rights-of-way, setbacks or building restriction lines, and encroachments;
- footprints, roof outlines, heights, finished floors, grades, drainage, retaining walls, fences, paved areas, and adjacent structures;
- overhead and underground utilities, service equipment, meters, poles, wires, clearances, sewer/water routes, and utility easements;
- trees and large vegetation with trunk, canopy, approximate root-protection area, health concerns, and public/private status;
- measured plans, elevations, sections, and roof framing of the existing garage and related outbuilding/walkway;
- photo log keyed to a site plan;
- condition assessment of slab, walls, foundations, framing, corrosion, moisture, cracking, and previous alterations;
- existing permit and inspection record; hazardous-material screening before demolition where applicable.

Acceptance: proposed work can be located and demolition/connections can be designed without relying on an unverified sketch.

## 3. Land use, zoning, and permit report

Required content:

- assessor parcel number, ownership/title reference, legal description, and recorded easements;
- base zone, community plan designation, and all overlays;
- Coastal Overlay Zone and coastal-development-permit determination;
- height limit, setbacks, structure separation, lot coverage, floor-area ratio, parking, access, and use limitations;
- status of the existing garage and prior additions;
- fire-separation-distance/opening limitations near lot lines;
- environmental, flood, steep-slope, geologic-hazard, historic, airport, parking, transit, and brush/fire screenings as applicable;
- required permits, discretionary actions, utility approvals, deferred submittals, and responsible agencies;
- code summary and documented interpretations or pre-application meetings.

Acceptance: each conclusion cites the controlling map, code section, agency record, or written interpretation and states its verification date.

## 4. Geotechnical and foundation basis

Required content:

- mapped geologic hazards and site reconnaissance;
- subsurface investigation or documented basis for using permitted presumptive values;
- fill, expansive soil, groundwater, corrosion, liquefaction, settlement, and slope considerations;
- allowable bearing, lateral pressure, friction, uplift, settlement, excavation, drainage, and slab recommendations;
- foundation reuse criteria and new footing/pier design parameters;
- construction observation and special inspection requirements.

Acceptance: the structural engineer can design each support and the contractor can price excavation without inventing soil parameters.

## 5. Architectural design package

Required content:

- site plan, demolition plan, dimensioned floor plans, roof plan, reflected ceiling/framing coordination where useful;
- exterior elevations and building sections with grades and controlling heights;
- enlarged plans and details for balcony/loading opening, sliding door, jib/hoist interface, stairs or ladder, guards, and roof transitions;
- door, window, room/use, finish, and equipment schedules;
- exterior materials/colors and relationship to the house/outbuilding;
- renderings clearly labeled as illustrative;
- accessibility, egress, natural light/ventilation, guards, and life-safety coordination appropriate to the legal use.

Acceptance: geometry agrees across plans, elevations, sections, schedules, CAD models, and structural grids.

## 6. Structural engineering package

Required content:

- existing-structure assessment and limits on reliance upon existing walls/slab/foundations;
- design codes, risk category, material specifications, deflection/vibration criteria, durability and corrosion protection;
- dead, live, storage, concentrated equipment, hoist/trolley, roof, rain, construction, wind, seismic, and any applicable snow loads;
- load combinations, tributary areas, load take-down, reactions, and foundation demands;
- global stability model and independent truss/beam/column checks with compatible connection forces;
- member schedule, truss geometry, bracing, diaphragms, collectors, chords, connections, base plates, anchors, welds/bolts, and foundations;
- temporary stability, erection sequence, shoring, and existing-roof-removal requirements;
- special inspections, testing, delegated design, and deferred-submittal criteria;
- signed and sealed calculations and drawings for permit/construction issue.

Acceptance: loads trace continuously from roof, walls, floor, equipment, and hoist to verified supports and soil; calculations and drawings use the same geometry and member names.

## 7. Envelope and building science package

Required content:

- roof assembly beneath/around building-integrated or rackless-looking PV components;
- low hip-cap framing interface, underlayment, metal roofing, flashings, edges, hips, penetrations, and maintenance access;
- drainage slopes, gutters/scuppers/downspouts, discharge locations, and overflow provisions;
- metal-panel wall assembly, attachment, water/air control layers, insulation, thermal bridging, vapor/condensation analysis, and interior finish;
- soffit/fascia, balcony/walkway waterproofing, doors/windows, transitions to existing work, and sealant schedule;
- ventilation strategy for roof cavities and loft; fire-resistance and ignition-resistant requirements where applicable;
- manufacturer data, warranties, compatibility, and mockup/testing requirements.

Acceptance: every exterior transition has a drainable, flashable, buildable detail with compatible products.

## 8. Solar, electrical, and energy package

Required content:

- surveyed roof azimuth, tilt, usable area, obstructions, and shade study;
- module layout with active and visually matching inactive infill panels identified;
- annual/hourly production model, assumptions, degradation, losses, and sensitivity;
- consumption/tariff data, PV/ESS sizing, export assumptions, economics, and current utility rules;
- electrical service/load study, one-line, conductor/conduit schedule, grounding/bonding, rapid shutdown, disconnects, labels, fire pathways, equipment locations, and vehicle-impact protection;
- structural attachment or integrated-roof interface and waterproofing coordination;
- utility interconnection, City permit documents, commissioning, monitoring, and operations plan.

Acceptance: array geometry matches the roof model; electrical, structural, fire-access, and waterproofing requirements are coordinated.

## 9. MEP and life safety

Required content:

- lighting, receptacles, dedicated equipment circuits, service changes, controls, and exterior-rated equipment;
- ventilation and any heating/cooling requirements based on legal use and enclosure;
- plumbing or roof-drainage connections, if any;
- egress route, doors, stairs/ladder, guards/handrails, fall protection, smoke/CO detection, and fire separation;
- fire extinguisher and emergency shutoff/labeling provisions where applicable.

Acceptance: systems are coordinated with structure and enclosure and can be permitted, installed, accessed, and maintained.

## 10. Construction planning, cost, and procurement

Required content:

- demolition and build-around-existing sequence;
- erection plan, temporary bracing/shoring, lifting access, working clearances, and weather protection;
- protection of occupants, neighbors, landscaping, utilities, retained garage contents, and public way;
- inspection/test plan and hold points;
- quantity takeoff, estimate by trade, design allowances, contingency, bid alternates, exclusions, and escalation date;
- baseline schedule, permitting duration, long-lead equipment, fabrication/shop-drawing sequence, and procurement register;
- contractor/fabricator constructability review and value-engineering record.

Acceptance: bidders price the same scope and the proposed sequence does not depend on unsupported existing construction.

## 11. Issued and record documents

Required content:

- frozen permit and construction issue sets with revision and purpose;
- calculations, specifications, forms, agency approvals, plan-check comments/responses, and deferred submittals;
- shop drawings, product data, samples, RFIs, substitutions, field reports, special inspections, and test results;
- change orders and record of design changes;
- as-built drawings/models, photographs, commissioning reports, warranties, maintenance instructions, and final approvals.

Acceptance: a third party can reconstruct what was approved, what was built, and how to operate and maintain it.

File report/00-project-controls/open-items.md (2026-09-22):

# Open Items Register

| ID | Question / required action | Why it controls design | Responsible party | Needed before | Status |
|---|---|---|---|---|---|
| OI-001 | Commission boundary/topographic survey and establish common datum. | Controls setbacks, grades, drainage, utilities, and all coordinated geometry. | Owner / surveyor | Design freeze | Open |
| OI-002 | Obtain parcel, zoning, community-plan, overlay, coastal, height-limit, and permit-history records for the address. | Controls legal envelope and permit path. | Architect / permit consultant | Design freeze | Open |
| OI-003 | Owner confirms storage (DEC-006); determine applicable building/fire occupancy and code scope. | Establishes storage loads, egress, fire and permit requirements; ADU assumptions do not apply. | Owner / architect | Code analysis | Open |
| OI-004 | Verify existing garage dimensions, framing, slab/foundations, deterioration, and prior permits. | Controls retained work, connections, demolition, and construction sequence. | Surveyor / architect / structural engineer | Structural issue | Open |
| OI-005 | Determine whether geotechnical investigation is required and obtain foundation criteria. | Controls columns, piers, settlement, uplift, and lateral resistance. | Structural / geotechnical engineer | Foundation design | Open |
| OI-006 | Locate and document overhead power lines and utility-required clearances. | Controls roof height, erection, crane/hoist operation, and safety. | Surveyor / utility / architect | Massing freeze | Open |
| OI-007 | Document trees, canopy/root zones, ownership, and proposed removals/pruning. | Controls access, construction, roof clearance, and possible permits. | Surveyor / arborist | Site/logistics plan | Open |
| OI-008 | Freeze coordinated roof geometry, loft limits, columns, trusses/beams, openings, balcony/loading ledge, and stairs/ladder. | Current studies use several generations of geometry. | Owner / architect / structural engineer | Report promotion | Open |
| OI-009 | Reconcile all structural names and geometry across CAD and analysis models. | Reactions and member checks are invalid if models do not match construction. | Structural engineer | Calculation issue | Open |
| OI-010 | Select PV/ESS concept and verify current utility tariff/interconnection assumptions. | Controls roof area, electrical service, equipment, cost, and economics. | Owner / solar designer | Permit design | Open |
| OI-011 | Develop drainage, waterproofing, condensation, insulation, ventilation, and corrosion-control details. | Exposed frame and inside metal panels create unusual envelope interfaces. | Architect / envelope consultant | Construction documents | Open |
| OI-012 | Establish project budget, estimate basis, desired construction date, and procurement strategy. | Needed to compare structural and architectural alternatives. | Owner / contractor | Design development decision | Open |

| OI-013 | Obtain written interpretation of roof over retained one-to-four-foot side strip, including 15-foot option, pitch and height measurement. | Controls east roof profile and whether first-story roofing exception applies. | Architect / City DSD | Roof freeze | draft |
| OI-014 | Determine how 525-square-foot condition applies to garage plus upper storage floor and identify alternate existing-structure approval route if needed. | Controls eligibility for encroachment. | Architect / City DSD | Design freeze | draft |
| OI-015 | Document exterior-wall retention, repairs, slab replacement and new piers; determine coastal/demolition treatment and legal-status evidence. | Controls preservation of footprint rights and permit process. | Architect / structural engineer / City DSD | Demolition design | draft |
| OI-016 | Reconcile 249 versus 286.25 inch north–south dimensions and locate finished upper wall, posts and roof against surveyed boundary. | Conflicting models and 37.25-inch example cannot establish compliance. | Surveyor / architect | Design freeze | draft |
| OI-017 | Establish fire requirements for storage use, retained one-foot wall, sloped roof and supporting steel. | Steel cladding alone does not establish a rating. | Architect / fire and structural reviewers | Permit drawings | draft |

| OI-SOL-01 | Review SOL-001 recommendation: 5.6–6.0 kW plus one 13.5 kWh battery; 35° with clerestory/cap coordination. | Owner must select system and roof; no decision adopted by report. | Owner / architect / solar designer | Roof freeze | draft |
| OI-SOL-02 | Produce physical module/access layout for 325 ft² gross face and check cap/clerestory shading. | Area-based capacity does not prove panel fit. | Solar designer / architect | Equipment selection | draft |
| OI-SOL-03 | Confirm generation provider, rate plan, export vintage, interval demand, current quotes and rebate eligibility. | Financial margin is narrower than input uncertainty. | Owner / solar designer | Procurement | draft |

| OI-FP-01 | Coordinate ARCH-006 with elevations, CAD and structural models: E-M now at W3 Y=185, S3 at E-S Y=-2; south column centers Y=-66 versus provisional beam center Y=-64; west columns X=-34 versus beam X=-32. | Existing elevation midpoint and earlier support/beam alignments no longer match the current plan; bearing offsets and 36-in transfer to wall-side frame need design. | Architect / structural engineer | Coordinated design freeze | draft |
| OI-FP-02 | Evaluate east-wall support options A/B, connections, lateral resistance, foundations and setback/fire treatment without crediting the cracked slab as a footing. | ARCH-006 is geometry only; neither wall-support alternative is selected or validated by report storage. | Owner / architect / structural engineer | Selection and structural issue | draft |

| OI-FP-03 | Design attachment and foundations for west-wall post WB3; confirm finish/connection clearances. WBN was removed by DEC-010. | WB3 is drawn against the existing wall; wall capacity and support details are unverified. | Structural engineer / architect | Structural coordination | draft |

| OI-FP-04 | Evaluate the optional ground-floor extension WB3–W3–W4–N1–N2 returning to the existing north wall; resolve garage-door access, wall openings, enclosure/retention implications, foundations and finished wall faces. | Orange route in ARCH-006 rev 3 is a concept option, not an adopted expansion; prior open-walkway design remains the baseline. | Owner / architect / structural engineer | Option selection | draft |

| OI-FP-05 | Size and detail the new north door bay between N1 and N2, now 16 ft center-to-center; reconcile door clear width, jambs, header and existing door/wall changes. | The 4-in post envelopes provide 188 in between faces, not a 16-ft clear opening. | Owner / architect / structural engineer | Door selection | draft |

| OI-STR-01 | Use STR-006 to reconcile ARCH-006 and roof/solar geometry; resolve adjacent west uprights, door clearances, bearing offsets and E-M option, then establish loads, materials, sections, boundary conditions, connections, bracing and foundations. | Saved geometry is not an analysis model; no equilibrium, capacity or deflection checks have been performed. West truss is now X=-34 and E-OB underside Z98.5, differing from earlier unresolved references. | Owner / architect / structural engineer | Engineering geometry freeze and structural analysis | draft |

| ENV-OI-01 | Establish distance to mean high tide for both the Pacific shoreline and Mission Bay; obtain each candidate manufacturer's written coastal warranty exclusion and check it against that distance before specifying a panel substrate. | Published Galvalume warranties exclude structures within 1,500 ft of salt water, with at least one manufacturer at two miles; inside that zone a steel-substrate panel may carry no meaningful warranty. Painted aluminum is the warrantable substrate. Extends OI-011. | Owner / architect / envelope consultant | Panel substrate specification | draft |

| ENV-OI-02 | Decide whether panels run continuous across the inside face of the frame, sit inside each bay, or use a hybrid, before selecting a panel family. | No bay clear width (49.5, 59.0, 80.0, 111.25, 131.75, 178.5, 188.0, 267.0 in) is a whole multiple of any standard panel width (30, 36, 42, 44 in). Tongue-and-groove and concealed-clip products lose their factory side joint when cut to bay width. | Owner / architect | Panel family selection | draft |

| ENV-OI-03 | Owner decision: are the wall panels non-structural cladding, or is a diaphragm contribution to lateral resistance to be pursued? | Insulated metal panels cannot serve as shear walls. Profiled single-skin sheet can be designed as a wall diaphragm under ANSI/AISI S310 and SDI DDM04, but a structural bay can never be glazed or reconfigured, and the decision must precede the engineer's lateral design. | Owner / structural engineer | Structural lateral design | draft |

| ENV-OI-04 | Design and price the secondary framing — girts and sub-girts — required to support the wall panels against wind and to set their plane relative to the frame. | Absent from STR-006, which excludes secondary framing, and not separately priced in the working cost estimate. Required for either attachment arrangement. | Architect / structural engineer | Cost estimate revision and construction documents | draft |

| ENV-OI-05 | Select which bays are glazed and which glazing system is used, then reconcile against the 665 sq ft panel / 778 sq ft cavity area basis. | Glazing runs $50-150/sq ft installed against panel at $3-24/sq ft installed, and area moves one for one. Candidate bays include west W3-W4 at 80 in clear, south S1-S2 at 59 in clear, and north W4-N1 at 49.5 in clear. | Owner / architect | Cost estimate revision and envelope details | draft |

| ENV-OI-06 | If an insulated metal panel is selected, obtain that specific product's large-scale fire test approval (NFPA 286, FM 4880, UL 1040 or UL 1715), or retain a compliant thermal barrier. | IBC/CBC Chapter 26 requires foam plastic to be separated from the interior by an approved thermal barrier unless the product carries special approval from large-scale testing. Where a thermal barrier was present in the tested assembly it cannot be omitted in installation. | Architect / envelope consultant / City DSD | Permit submittal | draft |

| ENV-OI-07 | Confirm whether the R-19 batt, vapour barrier and 5/8 in Type X drywall assembly behind the panels is retained if an insulated panel is selected. | A 2-in IMP at R-17.5 duplicates the batt thermally, but the Type X layer may also be serving as the Chapter 26 thermal barrier and as fire separation. Deleting it on thermal grounds alone would remove those functions. | Architect / envelope consultant | Assembly schedule and cost estimate revision | draft |

| ENV-OI-08 | Reconcile the 24-in expressed panel joint spacing used in the visualisation studies with actual column centre spacings of 135.75, 115.25 and 84 in. | 24 in divides none of those spacings, so joint-to-column alignment must be drawn rather than assumed if the wall is meant to read as bays. | Architect | Architectural elevations | draft |

| ENV-OI-09 | Specify the roof panel substrate. Confirm whether COST-ESTIMATE item G's standing seam is Galvalume by default, and price painted aluminum with a coastal-rated paint warranty as the alternative. | The 1,500-ft Galvalume exclusion applies to the roof more strongly than to the walls, and the roof is the outermost surface of the building. Trade guidance states Galvalume will not stand up to coastal conditions. Delta about $1,065-2,397 on the premium method. | Owner / architect / roofing contractor | Roof material procurement | draft |

| ENV-OI-10 | Specify roof clips, fasteners, gutters and PV attachment hardware for marine exposure: 316 stainless rather than 304 or 18-8, aluminum or stainless gutters, non-penetrating seam clamps with round-point setscrews, Class III anodising, and isolation pads at every dissimilar-metal contact. | 304 stainless suffers chloride attack and tea-staining in coastal service. Aluminum module frames and rails on a steel roof in a salt electrolyte is the classic accelerated-corrosion pairing; galvanized racking in ISO C4/C5 exposure can last only 5-20 years against a 25-year PV design life. None of this is separately priced in item G. | Architect / roofing contractor / solar designer | Construction documents | draft |

| ENV-OI-11 | Address salt accumulation beneath the PV array, where roughly 84% of the south face is sheltered from rain washing, and establish whether any rinsing or inspection access is realistic under a fixed array. | Sheltered roof areas corrode faster than exposed ones because rain never rinses them, and light rain can deposit fresh salt as it evaporates. The trade remedy is periodic washing, which a fixed array on a 30-35 degree slope two storeys up largely prevents. Roof panels under the array cannot be replaced without removing the array. | Architect / envelope consultant / solar designer | Roof and array layout freeze | draft |

| ENV-OI-12 | Reconcile the roof area bases before recomputing any per-square-foot roof figure: COST-ESTIMATE item G's 713 sq ft at 30 degrees (282x214 in south, 282x150 in north) against ASM-SOL-01's 325 sq ft south face at 35 degrees. | The two bases disagree, and the south slope run differs between them (17.83 ft versus 13.86 ft). That difference decides whether aluminum panels need expansion clips, since the 15-20 ft threshold falls between the two. | Architect / solar designer | Roof geometry freeze | draft |

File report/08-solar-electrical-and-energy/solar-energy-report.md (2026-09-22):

# Chapter 8 — Solar, battery and roof design

SOL-001 / Revision 1 / 2026-09-15 / draft

## 08 / Solar, battery and roof design

1370 Wilbur Avenue • Pacific Beach, San Diego, CA 92109

SOL-001 • Revision 1 • 15 September 2026 • Draft design-development report

Plan around approximately **5.6–6.0 kW of solar and one 13.5 kWh battery**. Develop the **35° roof option**: it shifts energy toward winter and gains loft envelope with almost no annual generation penalty. Confirm panel fit and clerestory height before selecting the roof.

Typical-year production from cached PVGIS data; household load inferred from six bills.

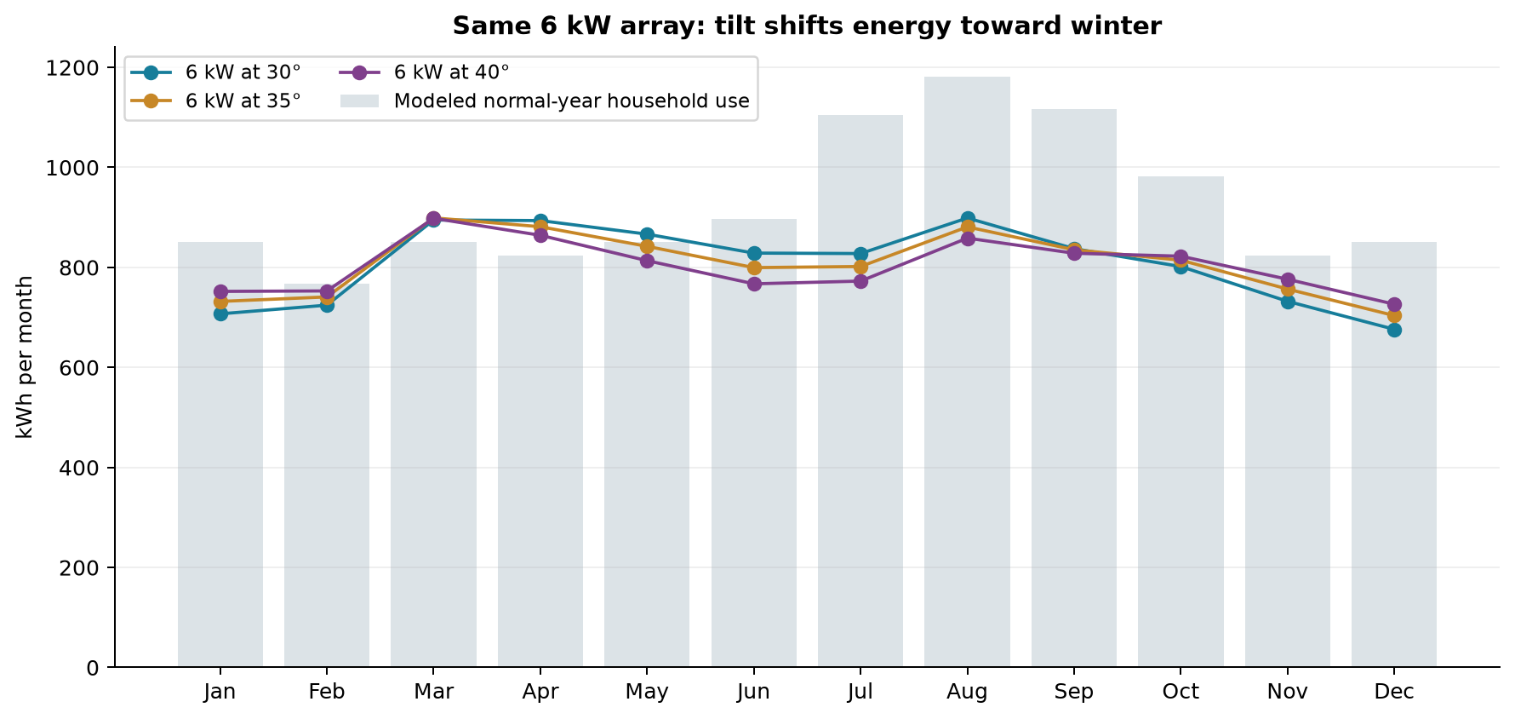
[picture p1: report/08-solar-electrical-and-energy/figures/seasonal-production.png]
Typical-year production from cached PVGIS data; household load inferred from six bills.


The current 325 ft² solar face is smaller than the 401 ft² face used in earlier energy studies. This chapter corrects that mismatch, retains the historical work with labels, and adds 30°/35°/40° generation, battery-dispatch and geometric comparisons.

This is a planning recommendation for owner review. The array layout, approved roofing system, electrical design, utility provider, site shade, permitting envelope and contractor prices remain to be resolved.

## Reading guide and evidence status

| Part | What it establishes |
| --- | --- |
| 1. Demand and solar resource | Six bills; weather model; sunlight and seasonal production. |
| 2. Roof area and tilt | 325 ft² current concept; physical panel fit; 30°/35°/40° tradeoffs. |
| 3. Storage and economics | Battery operation; system-size comparison; cost and tariff sensitivity. |
| 4. Design coordination | Integrated roof details; next design decisions; source register. |
| Appendix / historical figures | All recovered solar charts plus related roof studies, labeled with their limitations. |

The report contains new calculations and curated historical material. New calculations use the same cached solar/weather inputs and financial framework as the earlier study, allowing changes caused by pitch to be isolated. Historical charts and PDFs are evidence of prior analysis; their older roof-area assumptions do not govern the current concept.

kW is power: the rate of production or use. kWh is energy accumulated over time. A 6 kW solar array is its DC nameplate rating under test conditions. It does not supply 6 kW continuously. One average kW across a year means 8,760 kWh/year.

The data folder supplies bill inputs, monthly production, geometry, system comparisons, sun geometry and validation tables. The accompanying analysis archive preserves the original reports, source data, scripts and hourly runs. Editable report text is supplied as Markdown.

## 1 / Household demand

| 2026 bill | Reported kWh | Reported cost |
| --- | --- | --- |
| 2026-02 | 768 | $303 |
| 2026-03 | 874 | $350 |
| 2026-04 | 712 | $280 |
| 2026-06 | 997 | $390 |
| 2026-07 | 1179 | $460 |
| 2026-08 | 1409 | $544 |

February is treated as a month without air conditioning: 768 / 28 = **27.43 kWh/day**, or **1.14 kW continuously**. The earlier recollection of 24 kWh/day was approximate. Calendar month lengths substitute for actual billing dates.

The retained change-point model is daily kWh = 27.43 + 1.53 × max(monthly mean temperature − 63.57°F, 0). Normal weather gives about **11,096 kWh/year**, including roughly 10,011 kWh of base consumption and 1,085 kWh of cooling. The warmer 2016–2025 weather average gives about 11,335 kWh/year.

The six-point fit has about 56 kWh/month root-mean-square error. April is below the assumed fixed base; this exposes billing-period and usage variability. The inferred base/cooling split is provisional, not a measured end-use breakdown. Obtain 12 months of bills and interval data before ordering equipment.

The historical bill relationship is about $15.15/month + $0.3765/kWh, giving $4,360/year at modeled normal use. The tariff simulation uses a separate bundled SDG&E EV-TOU-5 baseline of $4,303/year. These are different estimation methods, not two simultaneous charges.

## 2 / Sun, weather and energy basis

PVGIS 5.2 calculations use approximate location 32.80°N, 117.24°W, south-facing crystalline-silicon modules, building-integrated mounting, 14% user system losses, and NSRDB radiation data for 2005–2015. Cloud variability is already reflected in irradiance. Do not subtract an additional cloud percentage. Building mounting includes temperature effects; the 14% input is not the model’s entire loss budget. [1]

No horizon or local shading is included, following the owner’s sunny-site description. A measured horizon, nearby trees, the clerestory, fascia/cap projection, and future vegetation still need checking. The cap overlap in the older area calculation was removed geometrically; its shadow was not simulated.

| Mid-month | Sunrise | Sunset | Daylight | Noon elevation |
| --- | --- | --- | --- | --- |
| Jan | 06:51 PST | 17:04 PST | 10.2 h | 36.2° |
| Mar | 06:58 PDT | 18:56 PDT | 12.0 h | 55.3° |
| Jun | 05:40 PDT | 19:58 PDT | 14.3 h | 80.5° |
| Jul | 05:51 PDT | 19:58 PDT | 14.1 h | 78.6° |
| Aug | 06:12 PDT | 19:34 PDT | 13.4 h | 71.1° |
| Sep | 06:32 PDT | 18:56 PDT | 12.4 h | 60.0° |
| Dec | 06:44 PST | 16:44 PST | 10.0 h | 33.9° |

Azimuth is compass bearing: south is 180°. The retained azimuth study found small August gains for southwest orientation at 15°, but that changes the roof direction and does not justify reorienting this design. Its numerical table remains in the supporting data.

Weather inputs use ERA5 via Open-Meteo, with 1991–2020 normals and a 2016–2025 comparison. They describe regional coastal climate rather than a sensor on this roof. [2]

## 3 / How much roof do we have?

| Geometry generation | Solar face | Use in this chapter |
| --- | --- | --- |
| Earlier exposed-frame design | 419.3 ft² gross; 401.3 ft² after cap overlap | Historical 7–8 kW studies only. |
| Current south-post / clerestory concept | 325 ft² gross sloped face | Primary design comparison; full width 23 ft 5½ in. |
| Current 30° plan projection | 281.5 ft² | About 12 ft run; starts 5 ft 3 in south of existing wall. |

The old drawing calls 325 ft² an “active solar plane.” That label overstates what is available to generating modules. Here, 325 ft² is **gross roof face**, including panel gaps, edge treatments, non-generating glass, and any required access clearances.

| System | Module area at 22% | Gross face at 90% coverage |
| --- | --- | --- |
| 5.64 kW | 276 ft² | 307 ft² |
| 6.00 kW | 294 ft² | 326 ft² |
| 7.00 kW | 342 ft² | 381 ft² |

At 22% module efficiency, 325 ft² accommodates 5.31 kW at 80% coverage, 5.65 kW at 85%, or 5.98 kW at 90%. At 23% and 90%, it reaches 6.25 kW. These are area budgets, not proven module layouts. Equation: kW = roof ft² × 0.09290304 × module efficiency × coverage.

Roof dormers, balconies and non-generating infill reduce this budget; surrounding shadows can cost additional energy. A 6 kW array leaves little discretionary roof area in the 325 ft² version.

## 4 / A physical module fit check

Slope-face view, inches, schematic. North is upslope; east/west orientation is not material to this fit test.

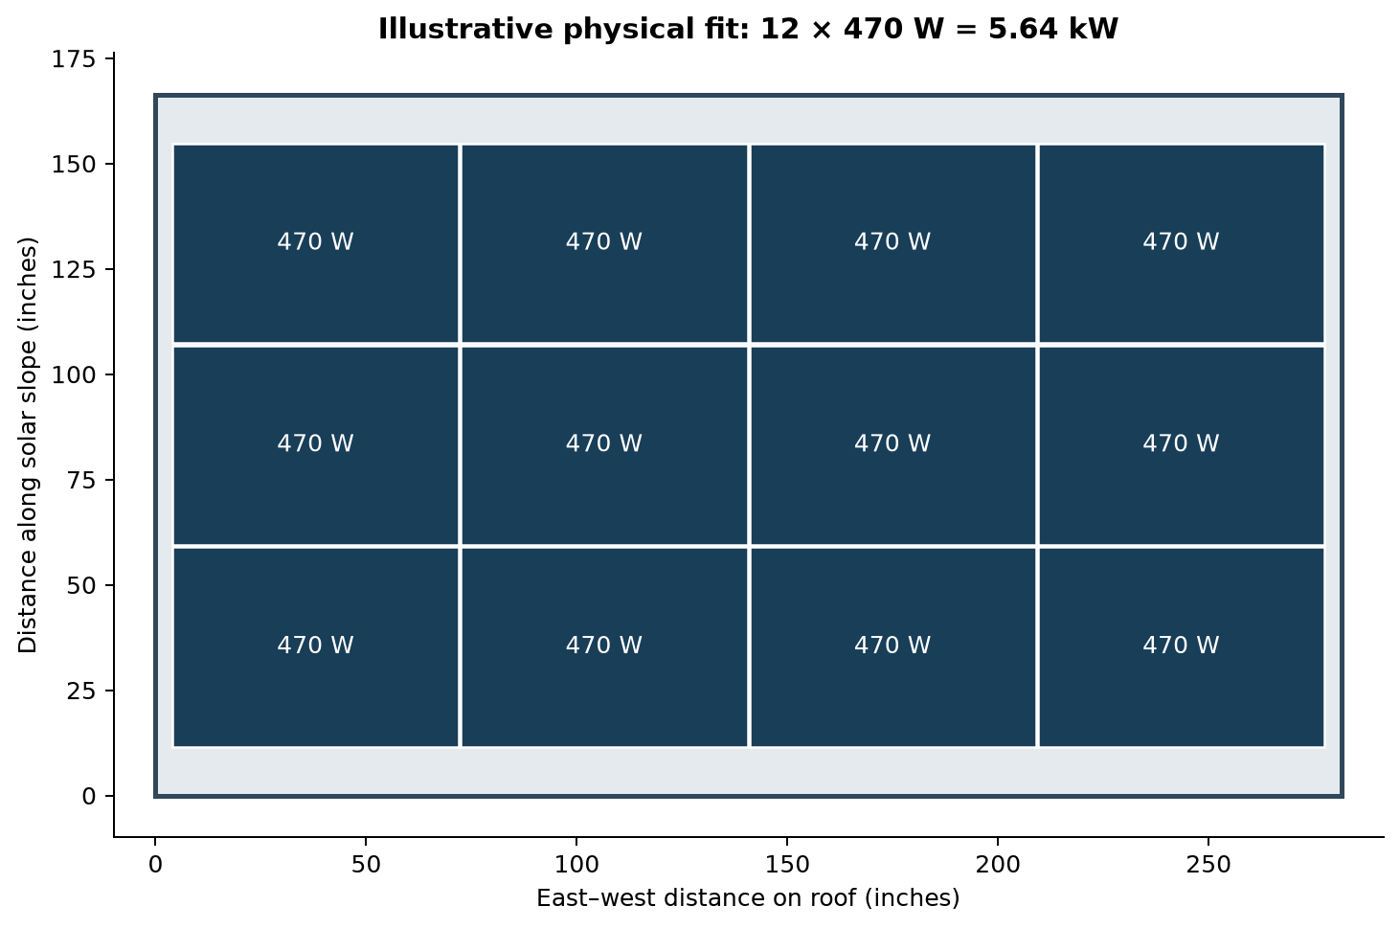
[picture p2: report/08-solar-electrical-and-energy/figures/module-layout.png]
Slope-face view, inches, schematic. North is upslope; east/west orientation is not material to this fit test.


A current REC Alpha Pure-RX example is 470 W and about 68.0 × 47.4 in. (22.4 ft²), with maximum module efficiency about 22.6%. Twelve modules in a four-by-three landscape grid give **5.64 kW** and about **269 ft²** of modules. This is an example for checking scale, not a product selection. [3]

With illustrative half-inch gaps, the grid occupies 273.5 × 143.2 in. The roof is 281.5 × 166.3 in. That leaves only about 4 in. on each east/west edge and 11.5 in. at each upslope/down-slope edge if centered. Required fire access, roof edges, clamps and waterproofing may invalidate this layout.

Adding a thirteenth module cannot be justified merely from remaining square feet; it needs a real packing layout. Sixteen of these modules do not fit the 325 ft² face. At a fixed 12-ft run, even 40° gives only about 188 in. slope length, short of four 47.4-in. rows plus gaps.

Recommendation: request layouts in the 5.6–6.0 kW range using approved roof/module assemblies; price alternatives before changing the building around a nominal panel-area target.

## 5 / Pitch: annual and seasonal generation

Fixed 6 kW nameplate; winter = December–February; summer = June–August.

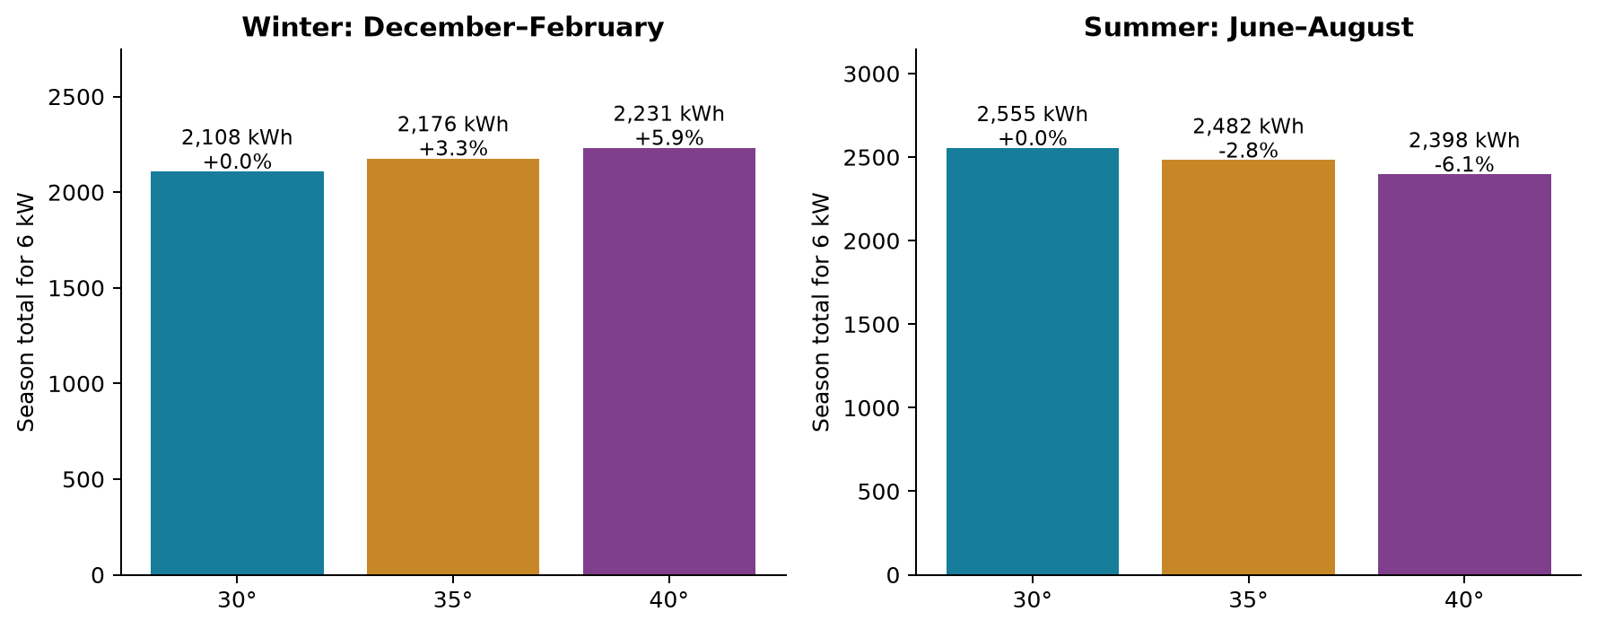
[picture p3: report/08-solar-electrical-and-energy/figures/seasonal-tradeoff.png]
Fixed 6 kW nameplate; winter = December–February; summer = June–August.


| Pitch | Annual 6 kW | Winter 6 kW | Summer 6 kW | August 6 kW |
| --- | --- | --- | --- | --- |
| 30° | 9,689 | 2,108 | 2,555 | 899 |
| 35° | 9,688 | 2,176 | 2,482 | 881 |
| 40° | 9,632 | 2,231 | 2,398 | 859 |

Relative to 30°, 35° changes annual energy by −0.01%, increases winter energy 3.26%, and decreases summer energy 2.85%. At 40°, annual energy changes −0.58%, winter rises 5.86%, and summer falls 6.14%. The near-identical annual output of 30° and 35° is far below weather and model uncertainty.

For 6 kW, the winter gains are about 69 kWh at 35° and 124 kWh at 40°. They are useful but modest. Steeper pitch does not create seasonal energy storage; the battery still shifts hours, not summer into winter.

The earlier 20° comparison gave about 1,587 kWh per installed kW annually, versus 1,615 at 30°: about 1.7% less. It required about 5.52 kW to average 1 kW over the year, versus 5.42 kW at 30°. Its smaller sloped area over a fixed footprint further reduced available capacity.

The hourly bill model shows only about $9/year more utility cost at 35° and $27/year at 40° for the same 6 kW and one battery. Treat differences this small as economically indistinguishable; choose among these pitches mainly for architecture, height and buildability.

## 6 / Monthly output and sizing targets

| Month | Modeled use | 6 kW / 30° | 6 kW / 35° | 6 kW / 40° |
| --- | --- | --- | --- | --- |
| Jan | 850 | 707 | 732 | 752 |
| Feb | 768 | 724 | 741 | 753 |
| Mar | 850 | 895 | 899 | 898 |
| Apr | 823 | 894 | 881 | 864 |
| May | 850 | 866 | 842 | 813 |
| Jun | 896 | 829 | 800 | 767 |
| Jul | 1,105 | 828 | 802 | 773 |
| Aug | 1,182 | 899 | 881 | 859 |
| Sep | 1,117 | 837 | 835 | 828 |
| Oct | 982 | 802 | 814 | 822 |
| Nov | 823 | 732 | 757 | 776 |
| Dec | 850 | 676 | 704 | 726 |

| Pitch | kW for 1,200 kWh in August | kW for average 1 kW annually |
| --- | --- | --- |
| 30° | 8.01 | 5.42 |
| 35° | 8.17 | 5.43 |
| 40° | 8.39 | 5.46 |

All production and use above are kWh/month. The owner’s final summer target was 1,200 kWh in August. At 30° it requires about 8.01 kW; at 40° about 8.39 kW. At 22% efficiency and 90% coverage these need roughly 435–456 ft², exceeding the 325 ft² concept. Size for useful annual savings unless the summer target becomes a firm requirement.

A 5.64 kW array produces about 9,108 kWh/year at 30° or 9,106 at 35°; 6 kW produces about 9,689. This is 82–87% of modeled annual household consumption before storage losses, not equivalent grid independence.

## 7 / West elevations: loft and clerestory

Schematic envelope sections, not construction drawings. Full east–west width is used for gross area; roof/truss thickness and side slopes are not deducted.

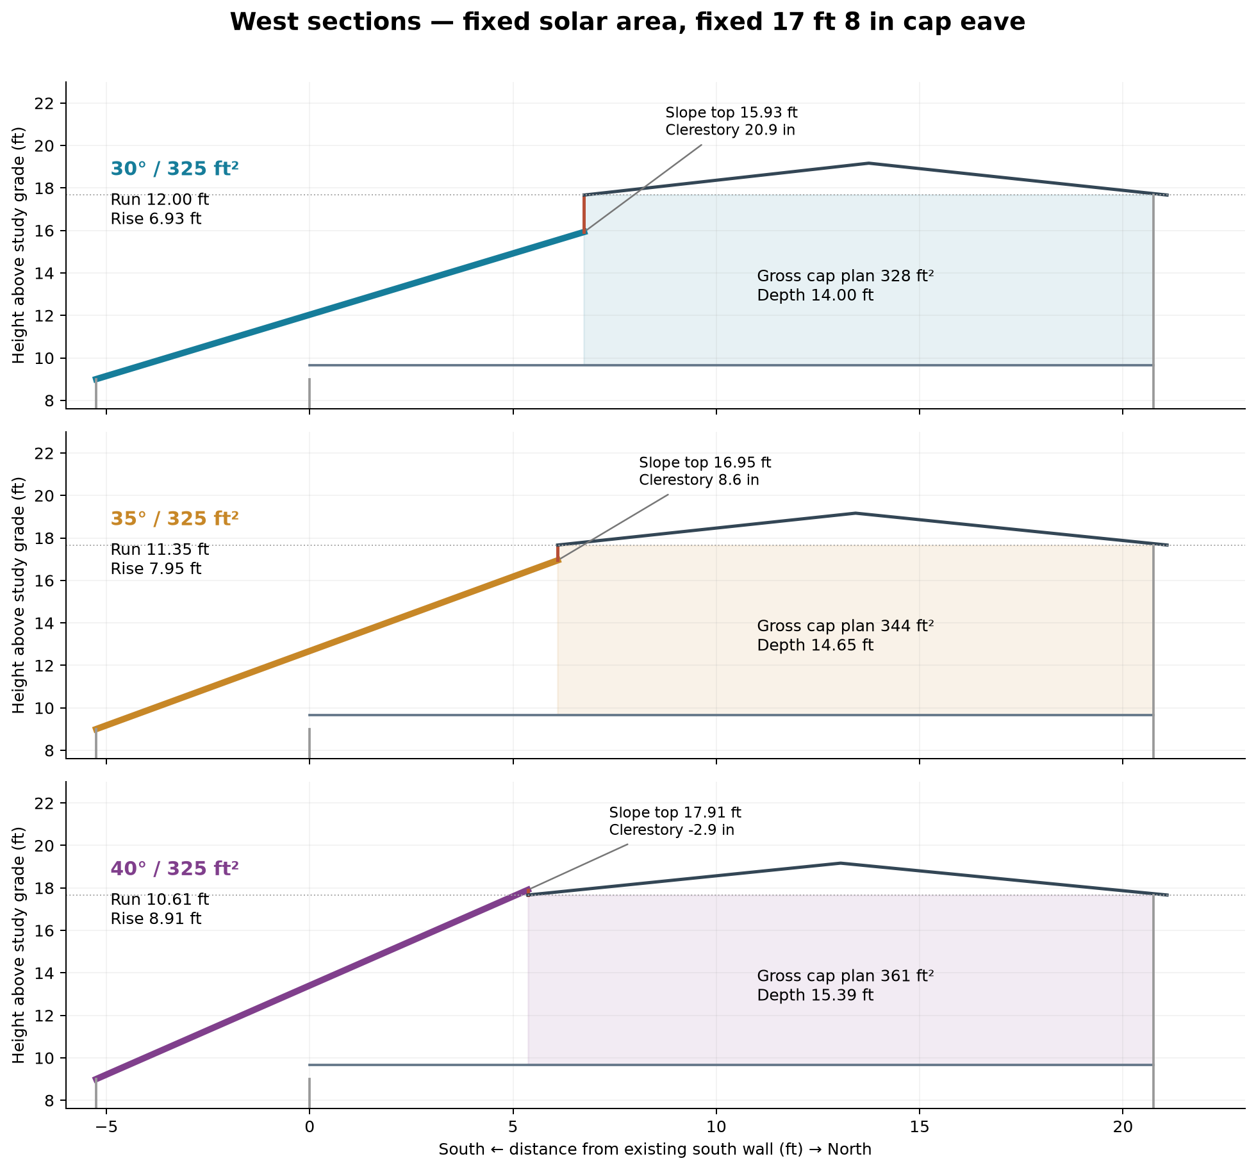
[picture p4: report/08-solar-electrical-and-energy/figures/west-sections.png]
Schematic envelope sections, not construction drawings. Full east–west width is used for gross area; roof/truss thickness and side slopes are not deducted.


These sections retain the newer study’s 9-ft low eave, 9-ft-8-in loft floor top, 17-ft-8-in cap eave, and 18-in cap rise. They do not alter the CAD model or establish zoning compliance. At 40°, the solar top passes above the retained cap eave; a positive clerestory needs a raised cap.

## 8 / Two different ways to steepen the roof

| Keep 325 ft² | 30° | 35° | 40° |
| --- | --- | --- | --- |
| Horizontal run (ft) | 12.00 | 11.35 | 10.61 |
| Solar rise (ft) | 6.93 | 7.95 | 8.91 |
| Gross cap plan (ft²) | 328 | 344 | 361 |
| Clerestory at fixed cap (in) | 20.9 | 8.6 | -2.9 |

With the same sloped face, 35° moves the cap about 7.8 in. south, increasing gross cap plan area by 15.2 ft². At 40° it moves 16.6 in. south, gaining 32.5 ft². The cap areas are 328.5, 343.7 and 361.0 ft². These use the full 23-ft-5½-in roof width and the existing north-wall station; they are **not net usable interior loft area**. Side slopes, walls, stairs, voids and structure must be deducted.

The 20.9-in clerestory at 30° shrinks to 8.6 in. at 35° and becomes a 2.9-in downward step at 40°. To preserve the original window band, raise the cap 12.2 in. at 35° or 23.7 in. at 40°. The cap ridge then becomes approximately 20.19 ft or 21.14 ft above the study grade, before any new assembly allowance.

| Keep 12-ft run | 30° | 35° | 40° |
| --- | --- | --- | --- |
| Gross solar face (ft²) | 325.0 | 343.6 | 367.4 |
| Area-based kW at 22%, 90% | 5.98 | 6.32 | 6.76 |
| Solar top above grade (ft) | 15.93 | 17.40 | 19.07 |

At fixed footprint, steeper pitch provides more solar area and headroom under the slope, but no extra cap footprint. Preserving the clerestory requires cap raises of 17.7 in. at 35° or 37.7 in. at 40°. Greater PV capacity is only possible if additional modules physically fit. The 20.75-ft north–south wall length is the roof-study input; Chapter 3 records a conflicting model dimension that must be reconciled.

## 9 / Geometry tradeoff and recommended pitch

The dotted alternative keeps the roof transition at the same plan position; the solid alternative keeps generating-face area constant.

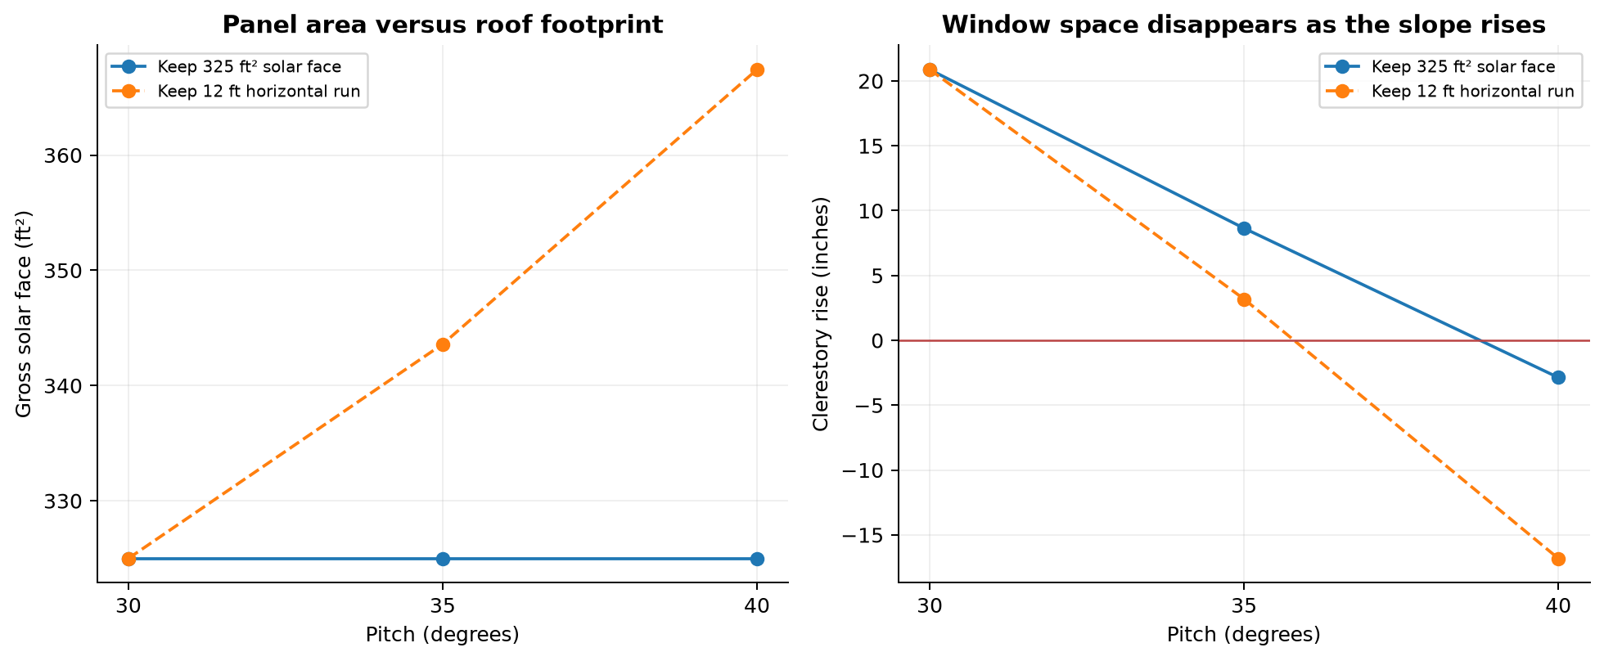
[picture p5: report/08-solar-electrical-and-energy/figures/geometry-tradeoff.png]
The dotted alternative keeps the roof transition at the same plan position; the solid alternative keeps generating-face area constant.


**Develop 35° with approximately 325 ft² of solar face.** It preserves annual production, improves winter production, and gains a modest amount of tall loft envelope. Keep 30° as the height-constrained fallback. Use 40° if the extra loft space is worth the cap/clerestory redesign, rather than for the small energy gain alone.

If preserving the current 20.9-in window band is important, study an approximately 12.2-in cap raise at 35°. If height cannot increase, redesign the clerestory with its roughly 8.6-in remaining gross band; actual glazing will be smaller after framing and flashings.

No numerical net-floor-area gain is claimed here. The full roof width includes areas outside the garage footprint, and the loft’s side slopes and structural depths remain unsettled. The new geometry CSV retains gross headroom-envelope calculations solely as coordination data.

## 10 / Why one battery is the useful starting point

Synthetic average days for 6 kW / 35° / one 13.5 kWh battery. Dispatch assumes perfect knowledge of the modeled year; actual control will differ.

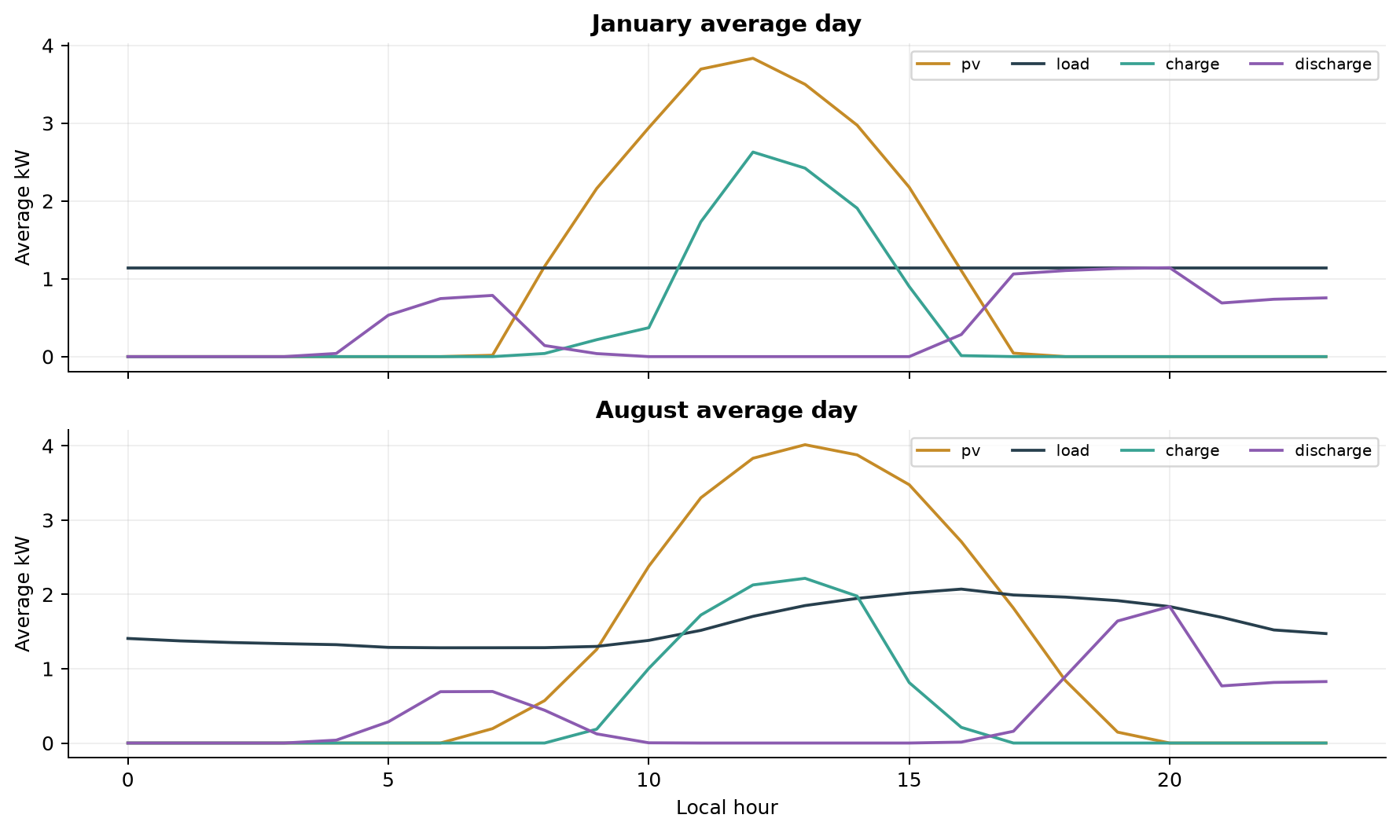
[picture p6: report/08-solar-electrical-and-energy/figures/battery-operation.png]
Synthetic average days for 6 kW / 35° / one 13.5 kWh battery. Dispatch assumes perfect knowledge of the modeled year; actual control will differ.


The model uses 13.5 kWh nominal energy, a 10% reserve, 90% round-trip efficiency, and a conservative 5 kW charge/discharge limit. It permits solar-only charging and discharge to serve the building; no grid arbitrage or battery export. Tesla’s current 13.5 kWh Powerwall is one example of this capacity class, not the specified product. [4]

At 6 kW / 35°, battery discharge is about 3,531 kWh/year. The modeled building still imports about 3,020 kWh/year and exports about 1,219 kWh/year. Annual energy balancing is not enough to eliminate imports because production and consumption occur at different hours.

A 12.15 kWh operating window divided by the 1.14 kW base load is about 10.6 hours before further operating losses or restrictions. Air conditioning and machinery shorten backup time. A battery does not provide backup by itself: transfer/islanding hardware, circuit selection and inverter starting capacity must be designed.

## 11 / Capacity and battery comparison

Planning tariff model at 30°. Gray region exceeds the current approximate area budget; it is retained to show the economic trend.

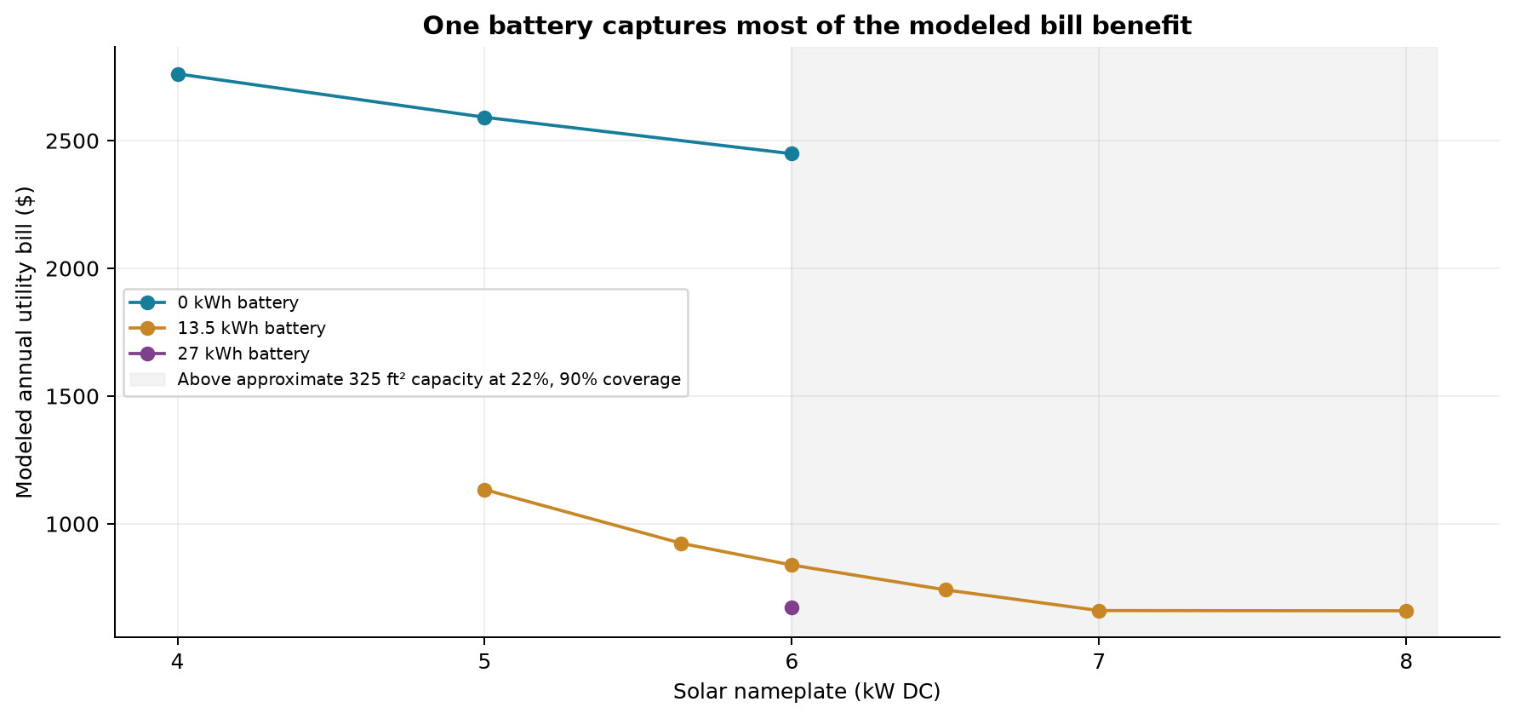
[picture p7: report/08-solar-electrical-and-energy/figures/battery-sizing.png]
Planning tariff model at 30°. Gray region exceeds the current approximate area budget; it is retained to show the economic trend.


| System at 30° | Installed allowance | Utility / year | Saving / year |
| --- | --- | --- | --- |
| 4 kW + 0 kWh | $20,240 | $2,761 | $1,542 |
| 6 kW + 0 kWh | $25,360 | $2,449 | $1,855 |
| 5.64 kW + 13.5 kWh | $38,688 | $924 | $3,380 |
| 6 kW + 13.5 kWh | $39,610 | $839 | $3,465 |
| 7 kW + 13.5 kWh | $42,170 | $660 | $3,643 |
| 6 kW + 27 kWh | $51,360 | $674 | $3,629 |

Moving from 6 kW alone to 6 kW plus one battery adds a $14,250 installed allowance and saves about $1,610/year in this model. Moving to a second battery adds about $11,750 but saves only another $165/year. A second battery is therefore a backup-duration choice, not the preferred bill-saving choice under these assumptions.

The numerical optimum is shallow: 5.64, 6 and 6.5 kW plus one battery are close financially. Panel layout, real quotes and actual interval demand should choose the final number, not a tiny modeled difference.

## 12 / Installed cost and lifecycle value

| 6 kW + one battery cost basis | Allowance |
| --- | --- |
| Conventional PV hardware/install at $2.56/W | $15,360 |
| 13.5 kWh battery and controls | $14,250 |
| Electrical allowance | $2,500 |
| Custom integrated-looking roof increment | $7,500 |
| Total central allowance | $39,610 |

These are retained planning allowances, not current contractor quotes. They exclude the garage structure and main roof construction, major service upgrades beyond the allowance, and any unpriced integrated-roof certification or fabrication. Obtain separate bids for the waterproof roof, active PV, matching infill, electrical work and battery to avoid double counting.

The prior $2.56/W regional benchmark is preserved as an assumption rather than a verified market offer. A ±20% total-installed-cost range gives roughly $31,700–$47,500 for the central system. The cost of a bespoke solar skin could vary more than this range.

At 30°, the central model gives about $3,465 first-year bill savings and roughly 11.4 years simple payback. With a 25-year horizon, 5% real discount rate, 0.5% annual savings degradation, maintenance of 0.5% of PV cost, and year-15 inverter/battery replacement, levelized net savings are only about $58/year; 25-year NPV is about $815. At 35°, they are about $49/year and $692. This is approximately break-even within uncertainty.

If the $7,500 custom finish would be built regardless of solar, allocating it to the building budget improves the 30° solar investment’s levelized net benefit to about $590/year. This changes cost allocation, not the total cash required. A higher custom premium, more expensive replacement battery, cheaper future electricity or less consumption can reverse the result.

No federal homeowner tax credit is deducted: current IRS guidance excludes residential clean-energy property placed in service after December 31, 2025. Business ownership and other tax provisions are outside this homeowner model. [5]

## 13 / Export credits, tariffs and incentives

SDG&E’s Solar Billing Plan values imported and exported energy by time. Residential customers use EV-TOU-5; evening imports from 4–9 p.m. make stored solar valuable. Export credits appear on the bill. A CCA customer must use its generation provider’s rules as well as SDG&E delivery charges. [6]

The analysis retains bundled rates effective August 1, 2026: about 80.2 cents/kWh summer peak, 49.6 cents off-peak and 13.1 cents super off-peak; winter values are about 52.4, 46.6 and 12.3 cents. It includes $0.79343/day base service charge. Current weekday 10 a.m.–2 p.m. super-off-peak treatment is held across the planning year. [7, 8]

The cached “Current 2026” export file contains NBT00 records although its README describes NBT26. That unresolved vintage mismatch is retained explicitly. The model approximates separate generation/delivery credit buckets, non-bypassable charges and annual surplus adjustment; it is not a full utility billing engine. [9]

Annual net-surplus energy is repriced at net-surplus compensation rather than keeping the ordinary hourly export value. The prior model used 1.702 cents/kWh for that settlement. This is a historical assumption, not a guaranteed future rate. Whether a remaining balance is paid or carried forward depends on the applicable utility/CCA settlement rules; it must be confirmed before treating exports as cash income. [10]

San Diego Community Power currently advertises $350/kWh for market-rate customers installing new solar plus battery: $4,725 for 13.5 kWh if eligible. Enrollment, approved equipment/installer, dispatch participation, available funds and service-provider eligibility must be checked. Keeping the upfront rebate requires at least five years in the program. No rebate or performance incentive is included in the central model. [11]

Because provider, tariff and export vintage remain unconfirmed, dollar figures should be used to compare concepts. The narrow lifecycle margin is not sufficient evidence for a purchase decision.

## 14 / Integrated roof and electrical scope

The desired appearance is a continuous glossy solar face. Standard PV modules must remain intact; odd triangular areas can use compatible non-generating panels. Those pieces add no electrical capacity and need their own wind, impact, fire, drainage and attachment design.

A concealed waterproof layer can be visually simple, but it must be durable, code-compliant and repairable. Ordinary rack-mounted modules do not automatically form an approved waterproof roof. Select either a tested integrated system or a coordinated weatherproof roof with compatible PV attachment, drainage and ventilation. Keep roof and solar costs separate in bids.

The clerestory/cap projection requires a shadow check on the upper module row. Roof pathways, setbacks, access to junctions, module replacement and firefighter requirements may reduce the 325 ft² allocation. City IB-301 describes PV/ESS electrical submittals and the building-review requirements for structural modifications. [12]

| Next design deliverable | Required content |
| --- | --- |
| Final array plan | Exact modules, dimensions, strings, setbacks/pathways, active/inactive infill, shading. |
| Electrical one-line | Service rating, inverter/ESS, circuit protection, conductors, grounding, disconnects and rapid shutdown. |
| Battery location and backup | Impact protection, clearances, transfer equipment, critical circuits and loads. |
| Roof details | Waterproof layer, flashings, drainage, ventilation, attachment and replacement access. |
| Commercial scope | Separate waterproof roof, PV, infill, battery, electrical and utility work prices. |

## Sensitivity / How strong is the cost conclusion?

| Retained scenario | Selected kW / battery kWh | Net benefit per year |
| --- | --- | --- |
| Custom roof, central | 6 / 13.5 | $58 |
| Conventional installation | 6 / 13.5 | $590 |
| Custom premium $15,000 | 6 / 13.5 | $-474 |
| Installed cost -20% | 6.5 / 13.5 | $722 |
| Installed cost +20% | 3.5 / 0 | $-377 |
| Discount rate 3% | 6.5 / 13.5 | $561 |
| Discount rate 8% | 3 / 0 | $-491 |
| Conditional SDCP rebate | 6 / 13.5 | $393 |
| Battery replacement full price | 4 / 0 | $-84 |
| Recent 2016-25 climate | 6 / 13.5 | $98 |
| Cooling +50% | 7 / 13.5 | $135 |
| Base computers -20% | 4 / 0 | $-224 |
| Base computers +20% | 7 / 13.5 | $339 |
| PV weather -10% | 7 / 13.5 | $-79 |
| PV weather +10% | 6 / 13.5 | $167 |
| Battery usable capacity -20% | 6 / 13.5 | $-64 |
| Import rates -20% | 4 / 0 | $-364 |
| Import rates +20% | 6 / 13.5 | $710 |
| Export credits halved | 6 / 13.5 | $35 |
| AC delayed four hours | 6 / 13.5 | $77 |

Historical sweep: 30° and the prior summer-optimal pitch; older 401 ft² area constraint. Dollar values retain prior inputs. Some selected sizes exceed the current 325 ft² layout budget. These rows show how uncertainty changes the decision; they are not current installation quotes. New 30°/35°/40° cases are in the current system-comparison data.

## 15 / Recommendation and remaining decisions

**Carry 5.6–6.0 kW DC and one 13.5 kWh battery into design development.** Compare 35° with the 30° fallback. The illustrated twelve-module 5.64 kW layout is a realistic scale check; its clearances still need professional layout review.

Keep the 325 ft² face as the current area budget. If more capacity is wanted, enlarge the roof or identify a different approved module arrangement. The 8 kW summer-target system belongs to a larger roof concept; neither 35° nor 40° makes it fit within an unchanged 325 ft² face.

Before selecting 35°, decide whether to raise the cap approximately one foot to preserve the window band. Coordinate that height with Chapter 3 setbacks, the survey, side-roof geometry, overhead utilities and structural depth. Keep all existing and proposed datums explicit.

Before selecting equipment, obtain interval demand, full bills including the generation provider, a shade study, electrical-service information, fire-access layout and at least comparable contractor quotes. Test the design with a non-ideal battery controller and the actual tariff/credit rules. Re-run the financial analysis after those inputs are known.

The 30 new system simulations pass annual energy balance with residual below 0.00000001 kWh. Monthly PV is normalized to the cached PVGIS totals. These checks establish internal numerical consistency; they do not validate the assumed household profile, legal roof envelope, product layout or future prices.
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

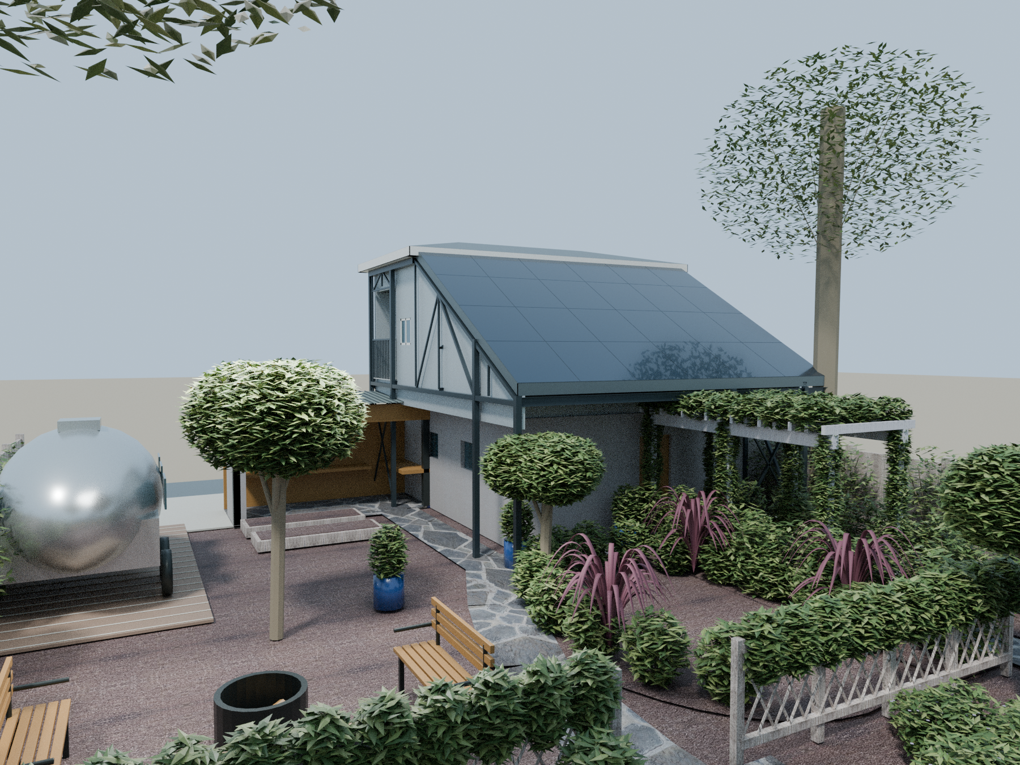
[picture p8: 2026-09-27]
render/20260910.01-backyard-proposal/02-proposed-patio-to-garage.png

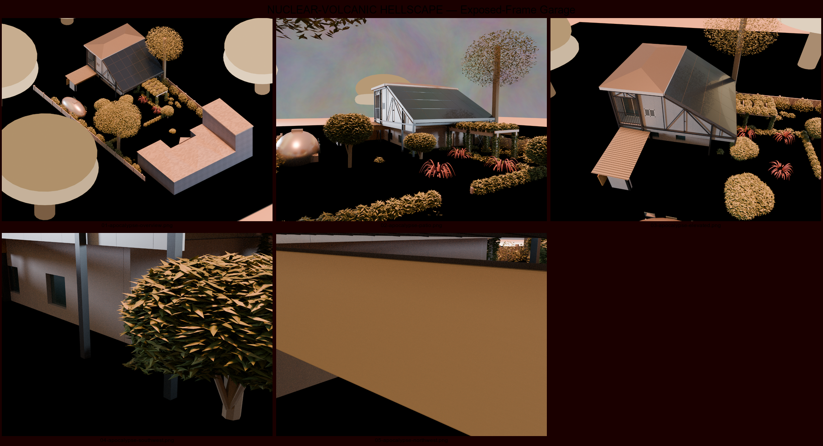
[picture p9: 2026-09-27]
render/20260910.01-backyard-proposal/apocalypse-contact-sheet.png

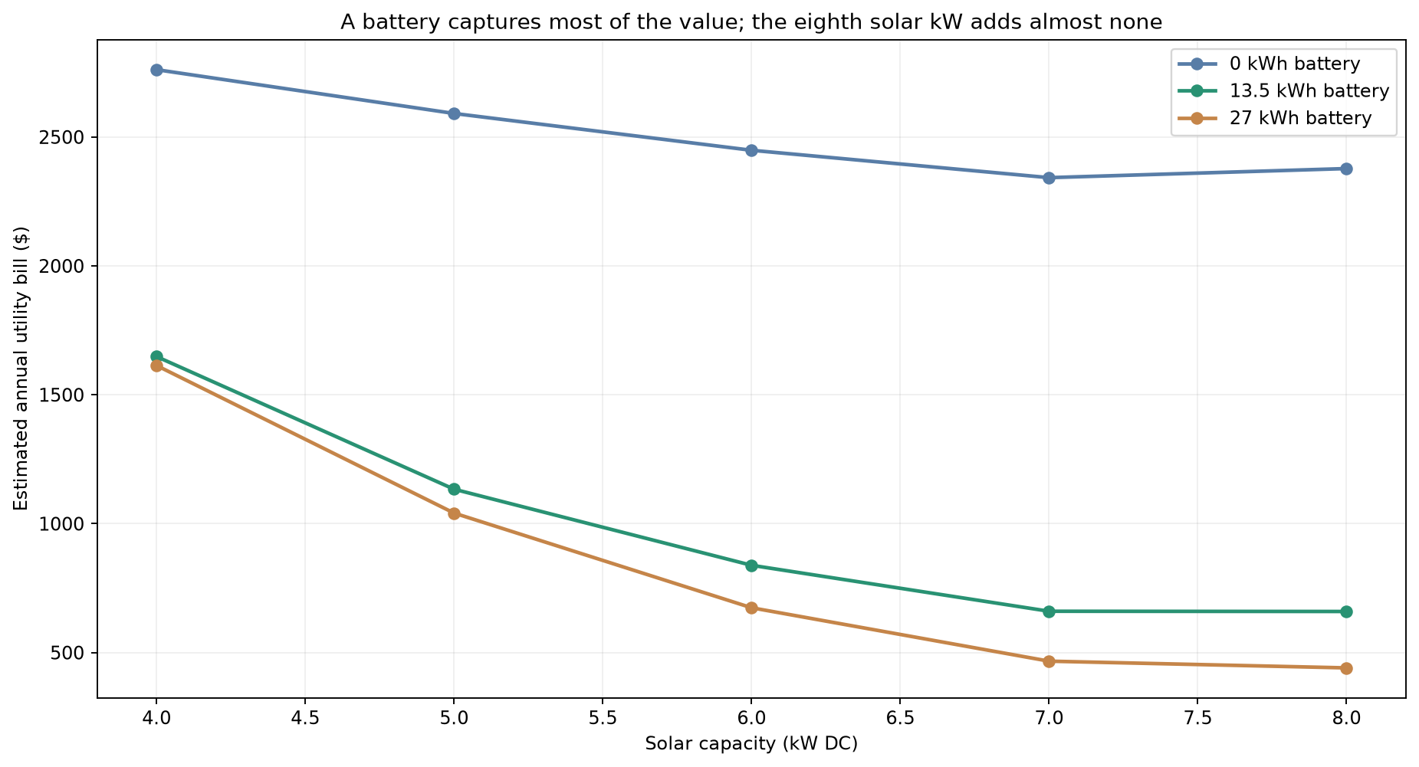
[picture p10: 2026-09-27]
report/08-solar-electrical-and-energy/figures/historical-bill-by-system.png

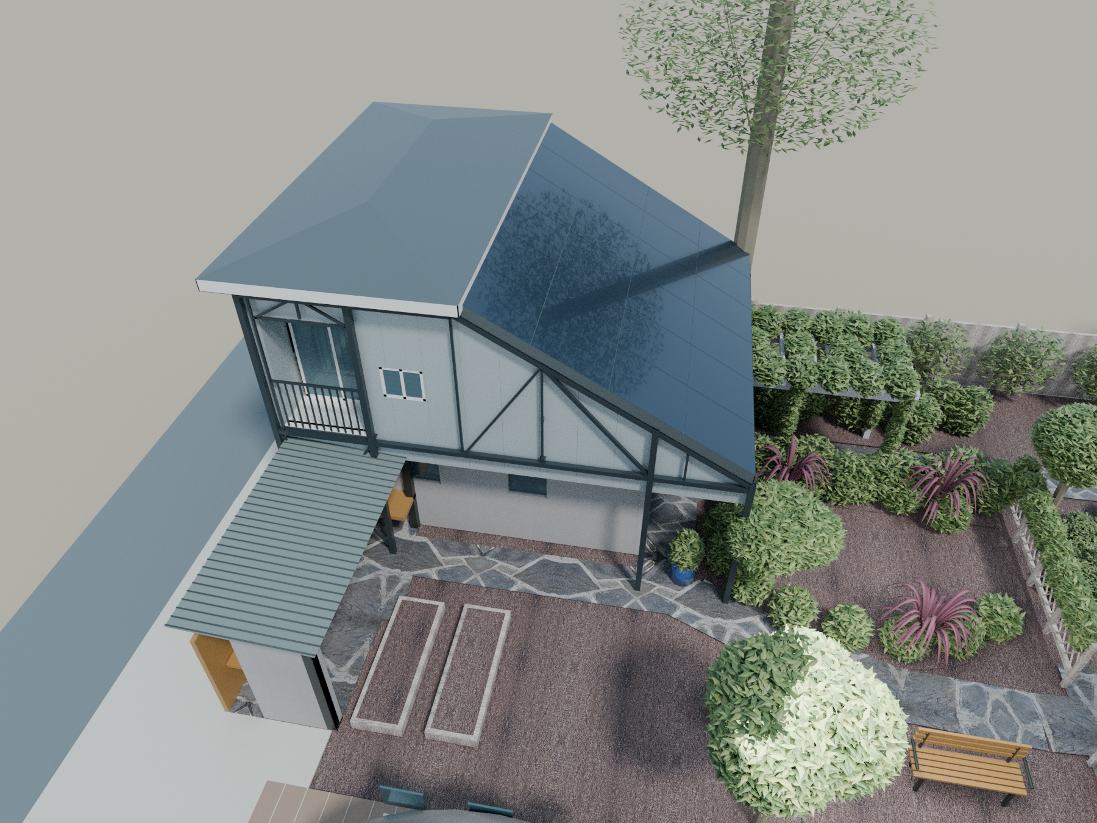
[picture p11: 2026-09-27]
render/20260910.01-backyard-proposal/03-proposed-garage-context.png

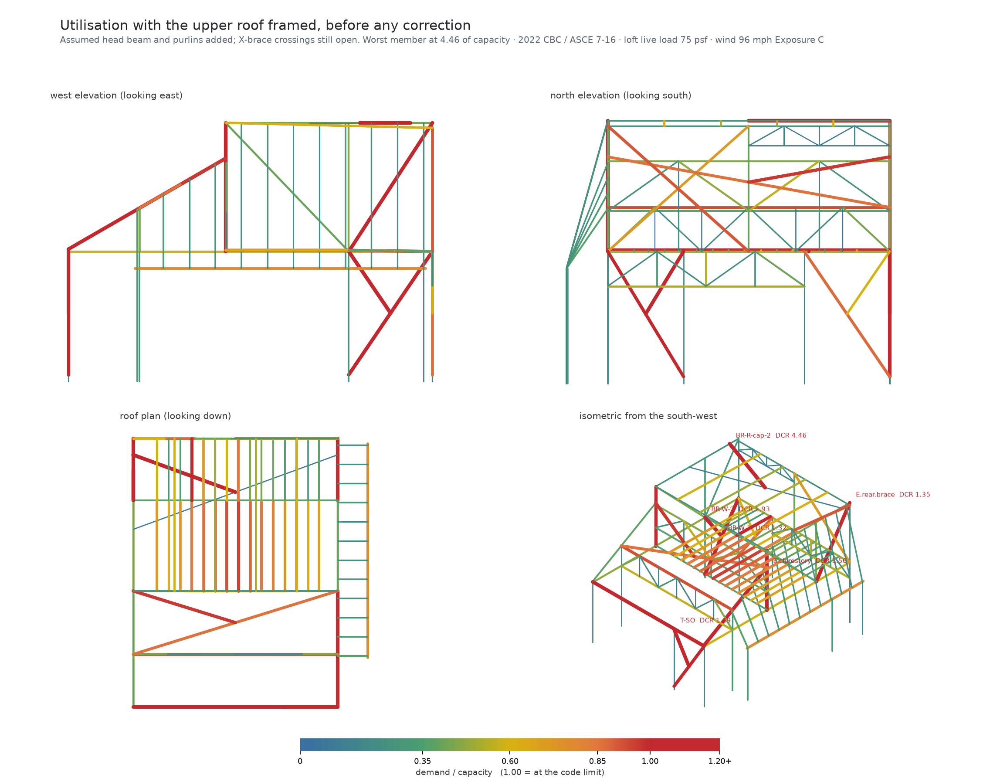
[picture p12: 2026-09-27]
report/06-structural-engineering/fea-study/figures/utilisation.png

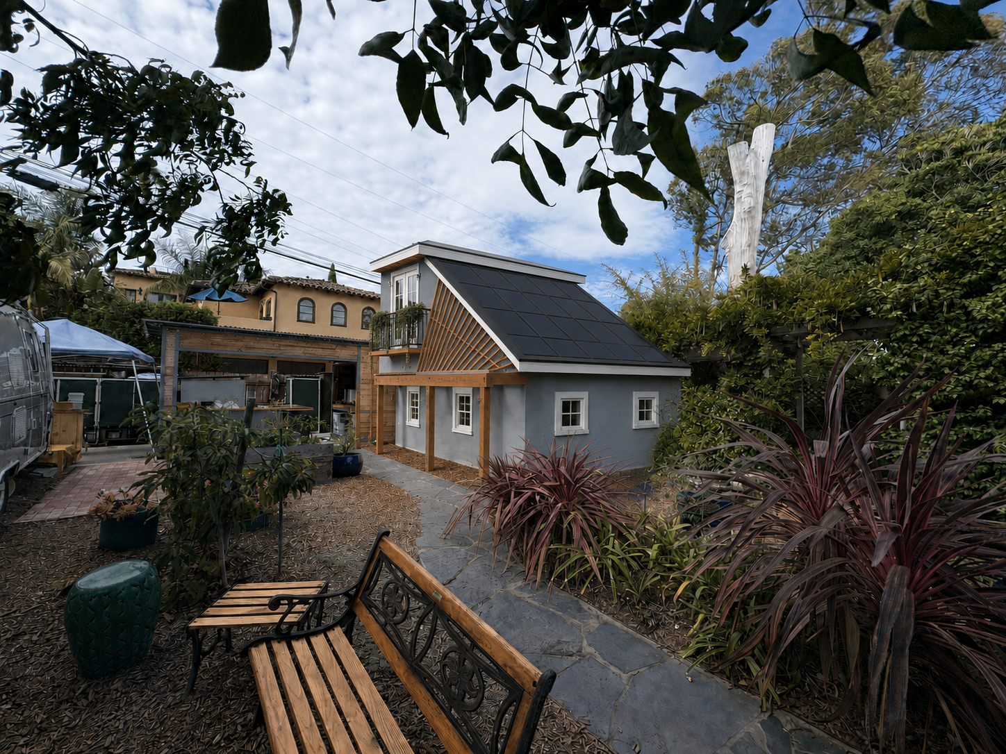
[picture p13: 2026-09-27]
render/20260907.01-site-concepts/flat-cap-balcony-v1.png

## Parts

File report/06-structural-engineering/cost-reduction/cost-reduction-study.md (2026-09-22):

# STR-008 — Frame cost reduction study

**Revision:** 3 · **Date:** 2026-09-18 · **Status:** `draft` · **Section:** 06 Structural engineering
**Scheme analysed:** BEAM-001, `frame-models/frame-20260920.01-beam-scheme.compas.json`
**Live load:** 100 psf (DEC-014) · **Wind:** 96 mph, Exposure C · **Code:** 2022 CBC / ASCE 7-16
**Rates:** `EW-TRUSS-PROCUREMENT.md` §3 and `COST-ESTIMATE.md` §D/§E, via `structural-analysis-v6/cost.py`
**Interactive models** — both switch colouring between utilisation, recommended
action, removability and what governs:
[**cost-reduction-3d-solid.html**](cost-reduction-3d-solid.html), every member
extruded at its actual cross-section so relative sizes are readable, and
[cost-reduction-3d.html](cost-reduction-3d.html), the lighter line version.
Green removes, red enlarges, blue re-sections, grey stays.
**Plan:** [frame-plan.png](frame-plan.png) — every member named and dimensioned,
openings hatched; [frame-plan-stair-middle.png](frame-plan-stair-middle.png) is
the superseded arrangement, kept for comparison (§10).

> Preliminary engineering study. Not a quotation and not a construction document.
> No connection, base plate, anchor or foundation is designed or checked.

> **Revision 3** adds the second north-wall post (§11). **Revision 2** adopted the
> owner's stairwell move (§10) into the drawn model.
>
> **Revision 1 corrects revision 0.** Revision 0 proposed deleting 33 of 54 floor
> joists. That was a defect in the deck-span check, not a finding — it would have
> left one shelf with no framing at all and a 128 in. gap in a loft bay. **No floor
> joist can be deleted.** See §3 and §13. The saving falls from $7,220 to $5,630.

---

## 1. The finding that reorders everything else

**Optimising this frame for weight optimises the cheapest thing in it.**

| Cost driver | Rate |
|---|---|
| Steel material | $0.77–0.94/lb — **1,000 lb is worth about $850** |
| Shop fitting and welding | 0.20–0.35 hr per joint at $80–110/hr — **$16–39 per joint** |
| Field-bolted connections | $40–80 each |
| Erection, per piece | $55–95 |
| Procurement and stocking | $150–400 per **distinct section** |
| Shop fabrication minimum | $10,000–18,000 as a job charge |

So the quantities that move money are **pieces, joints and distinct sections**. The
project's own procurement note reached this independently:

> *"A truss that saves 180 lb of steel (worth about $130) while adding 46 joints
> (worth $736–1,794) is a worse buy, and no amount of steel price movement closes
> that gap."* — `loft-span-study/cost.py`

## 2. Four strategies, all verified by re-analysis

Each option below was re-solved against every governing load combination and
checked for strength, span deflection **and** wind drift before being counted.

| Option | Steel | Pieces | Joints | Sections | Cost (mid) | Change |
|---|---:|---:|---:|---:|---:|---:|
| As drawn | 9,718 lb | 73 | 135 | 11 | $32,202 | — |
| Adequate — 3 members enlarged | 9,776 lb | 73 | 135 | 13 | $32,826 | +$624 |
| **Adequate, 46 pieces removed** | 8,860 lb | **60** | **108** | 12 | **$27,035** | **−$5,167** |
| Adequate, 46 sections lightened | 7,123 lb | 73 | 135 | 17 | $30,115 | −$2,087 |

**Removing pieces saves two and a half times what lightening sections saves — while
removing a third as much weight.** 860 lb removed beats 2,653 lb shaved, because
deleting a member deletes its joints, its handling and its erection, and thinning a
member's wall deletes none of those. Lightening also *adds* distinct sections
(11 → 17), which costs money at $150–400 each.

These two are alternatives, not additions. They compete for the same margin: after
lightening, the frame sits at DCR 0.99 and drift H/405, and nothing further can be
removed. **Remove first.**

## 3. What can be removed — steel only, no joists

**14 steel members, 935 lb**, verified together at max DCR 1.00 and wind drift H/409.

| Member | Why it can go |
|---|---|
| `BW` | West edge beam; the deck reaches the columns without it |
| `CT.mullion.1`–`4`, `CT.diag.E` | Clerestory frame members surplus to the structure |
| `E.rear.brace`, `E.square.brace`, `W.square.brace` | Redundant with the remaining bracing |
| `BR-NU-2`, `BR-W-1` | One diagonal of an X-pair; the other carries both directions |
| `RE-N`, `RE-S`, `RF @ 170.58` | Rafters within the spacing the panel already spans |

`CT.mullion.5` was tested and **rejected** — it pushes the frame to DCR 1.01.

12 members are **critical** — deleting any one leaves a mechanism. 14 more are
required to keep the rest within capacity.

### No floor joist can be deleted

The joists carry the deck, and the deck is not in the structural model. Tested
one at a time against the 23/32 in. OSB span of 24 in., measured across each deck
including out to its framed edges:

| Deck | Joists | Spacing | Can any single joist go? |
|---|---:|---:|---|
| loft bay 1 | 12 | 16.0 in. | **No** — any deletion opens ~31 in. |
| loft bay 2 | 12 | 16.0 in. | **No** |
| loft bay 3 | 15 | 15.3 in. | **No** |
| shelf SH-E | 2 | 12.0 in. | **No** |
| shelf SH-W | 5 | 14.8 in. | One edge joist only, against a rim — not recommended |
| shelf SH-M | 8 | 14.2 in. | One edge joist only, against a rim — not recommended |

At 15.4 in. centres, removing one joist doubles the span to about 31 in. There is
no deletion that lands inside 24 in. **Fewer joists is only available by
re-spacing with a deeper joist — §5, not §3.**

## 4. Fewer distinct sections — the cheapest change of all

Collapsing to one section per structural role:

| | Sections | Steel | Cost (mid) |
|---|---:|---:|---:|
| As drawn | 11 | 9,718 lb | $32,202 |
| One per role | **5** | 9,899 lb | **$30,783** |
| Change | **−6** | **+181 lb** | **−$1,419** |

| Role | Members | Single section |
|---|---:|---|
| Columns | 14 | HSS5X5X3/16 |
| Rafters | 15 | HSS3-1/2X3-1/2X3/16 |
| Truss | 11 | HSS3X3X3/16 |
| Clerestory | 9 | HSS3X3X3/16 |
| Bracing | 8 | HSS2-1/2X2-1/2X1/8 |

**Adding 181 lb of steel saves $1,419**, and the frame gets safer doing it — worst
utilisation falls from 0.98 to 0.77. Verified: stable, no deflection violations.

## 5. Joist spacing

The joists were never sized by structure. At 100 psf they run at DCR 0.19–0.58 and
deflect L/960 against an L/360 limit.

| Option | Joists | Worst DCR | Deflection | Cost Δ | Deck required |
|---|---:|---:|---:|---:|---|
| 2×8 @ 15.4 in. as drawn | 54 | 0.58 | L/960 | — | 19/32 in. OSB |
| 2×8 @ 30.8 in., delete alternate | 32 | **1.02 ✗** | L/539 | −$1,210 | 1⅛ in. OSB |
| **2×10 @ 24 in., respaced** | 36 | 0.57 | L/1369 | **−$990** | 23/32 in. OSB |
| 2×12 @ 32 in., respaced | 29 | 0.60 | L/2004 | −$1,375 | structural panel |
| 2×12 @ 48 in., respaced | 22 | 0.86 | L/1388 | −$1,760 | steel deck + topping |

Two things constrain this. You cannot simply delete alternate joists — a 2×8 at
30.8 in. goes to 1.02. And **the deck governs, not the joist**: every option past
24 in. forces a more expensive deck that consumes most of the saving. NDS also
withdraws the 15 % repetitive-member factor beyond 24 in. centres.

Realistic joist saving: **about $1,000**, and it is now the *only* route to fewer
joists — §3 can remove none. It is additive to the §8 package rather than
overlapping with it, but it needs its own verification run before being counted.

## 6. Where the money is not

- **Weight.** 1,000 lb is $850. It is the last thing to optimise.
- **The clerestory mullions.** Five verify as removable structurally, but they
  carry glazing. Their spacing is set by the glass, not by this analysis.
- **The fabrication minimum.** $10,000–18,000 is a job charge. Below some size,
  making the frame smaller does not make the invoice smaller. Three San Diego
  shops should be quoted before any of these reductions are treated as money.

## 7. Scheme comparison

| | Steel | Pieces | Joints | Sections | Cost |
|---|---:|---:|---:|---:|---:|
| BEAM-001 beam scheme | 9,718 lb | 73 | 135 | 11 | $22,948–41,456 |
| Truss scheme (`square-upper-west`) | 5,825 lb | 100 | 186 | 15 | $21,779–41,165 |

**The beam scheme uses 67 % more steel for the same money** — 27 fewer pieces,
51 fewer joints, 4 fewer sections. This is the project's own procurement thesis,
reproduced from the structural model rather than from a rule of thumb.

## 8. The two changes together — verified as one package

§3 and §4 were each verified against the adequate frame **on their own**. Applied
together they are not automatically valid, and they are not: deleting 46 members
redistributes force into the very members the five-section palette has just
standardised, and the naive combination lands over capacity.

Reconciled (a handful of members stepped back up a size), the package verifies:

| | As drawn | Recommended package | Change |
|---|---:|---:|---:|
| Steel | 9,718 lb | 8,047 lb | −1,671 lb |
| Pieces | 73 | **58** | −15 |
| Fitted joints | 135 | **104** | −31 |
| Distinct sections | 11 | **6** | −5 |
| Cost | $23,028–41,596 | $18,416–32,840 | **−$6,684** |
| Worst utilisation | 0.98 | **0.777** | — |
| Wind drift | H/464 | **H/431** | — |
| Deflection violations | 0 | 0 | — |

These are the current figures, which include the owner revisions carried since
revision 1 — the south slope seated on `B-SO`, the `BE.upper` beam, the east side
rebuilt in wood and analysed as a separate structure, and the stairwell move of
§10 and the second north-wall post of §11. They are larger than the $5,630 quoted
in the revision-1 note above because the east-side rebuild deletes 10 steel
members on its own.

Drift moves the wrong way (H/514 → H/431) and is still well inside the H/400
serviceability target, because the east steel columns that used to stiffen that
wall are gone. That is a consequence of the wood lean-to, not of the stair.

The package is worth more than the sum of its parts as presented in §3 and §4
separately, because removing members and rationalising sections both reduce the
same overheads. The five-section palette:

| Role | Section |
|---|---|
| Columns | HSS5X5X1/4 |
| Rafters | HSS2X2X1/8 |
| Truss | HSS3X3X1/8 |
| Clerestory and bracing | HSS2-1/2X2-1/2X1/8 |

## 9. Recommended sequence

1. **Take the package in §8 as one change**, not as two. Re-verify after any
   deviation from it — the components do not compose safely on their own.
2. **Re-space the joists to 2×10 @ 24 in.** (§5) as a separate change. It is the
   only way to fewer joists; none can simply be deleted.
3. **Do not thin the remaining sections** further. It saves less than removal,
   adds section types, and consumes the margin the package needs.
4. **Quote three San Diego shops** before treating any of this as banked. The
   $10,000–18,000 fabrication minimum may absorb part of it.

## 10. Stairwell moved one bay south — adopted into the model

Owner variant, now the drawn arrangement. The stair sits in the west strip
between `BW` and the inner beams. As drawn it occupied the **middle** of three
bays, y 71–185, so reaching it meant walking the length of the loft. It now
occupies the **south** bay, y 3–128, arriving near the south wall and still
under cover.

Two moves do it:

- **`B-1A` runs west to `BW`** instead of stopping at the inner line, closing the
  strip at y = 128.
- **`B-1` gives up its length west of the inner line** (3 segments), opening the
  strip at y = 71.

The deck follows: the shelf gives up its west end, and the strip from y 128 to
185 — the old stair's north half — is decked as `west strip infill`.

### Verification

Both arrangements were run through the **same** pipeline — same owner revisions,
same removals, same five-section palette, same reconciliation loop — so the two
columns are comparable rather than merely adjacent. Reproduce the left column
with `STAIR_SOUTH=0 python make_view.py`.

| | Stair in middle bay | **Stair south (adopted)** |
|---|---:|---:|
| Adequate | yes | **yes** |
| Worst utilisation | 0.754 | **0.777** |
| Wind drift | H/441 | **H/431** |
| Deflection violations | 0 | **0** |
| Steel | 8,002 lb | **8,002 lb** |
| Pieces / fitted joints | 58 / 104 | **57 / 102** |
| Cost (mid) | $25,551 | **$25,382** |
| Before-demo members | 50 up, 62 wait | **50 up, 61 wait** |

**The move is free, and the splice it removes pays a dividend.** Steel is
identical to the pound, because `B-1A` gains exactly the length `B-1` gives up.
Utilisation rises 0.754 → 0.777 and drift falls H/441 → H/431, both small enough
to sit inside the reconciliation's own step size, and the governing members are
unchanged — `N2` and `S3` under 1.2D+1.6L, neither of which touches the stair.
One piece and two fitted ends come out with the `BWI` splice below, worth $169.

### `BWI-2` and `BWI-3` become one beam

`BWI` was split at y = 71 because `B-1` crossed there and carried on west to
`BW`. `B-1` stops at this line now, so the splice was left sitting in the middle
of the **free edge of the stair opening** — the last place to put one.

The two merge into a single `W12X16` running the full **182 in.** from `B-S` to
`B-2`. The node stays, because `B-1` still frames into the side of the beam;
what goes is the splice, and with it one piece and two fitted ends. The
continuous beam deflects L/814 over the opening.

### The vacated bay is framed, not just decked

The strip from y 128 to 185 — the old stair's north half — becomes floor.
Declaring the `west strip infill` deck is not the same as framing it: with
nothing underneath, the tributary machinery hands that floor load straight to
the four beams around it, they carry it, and the frame verifies over a bay with
nothing for the sheathing to land on. **That is the §13 blind spot exactly, in a
new place.**

Two 2×8 DF-L No.2 joists now span the 57 in. from `B-1A` to `B-2`, on the same
x stations as the bay immediately north (x = −18.66 and −3.31) so the lines run
through across `B-2` rather than stopping and restarting a few inches over.
Measured out to the framed edges of the strip — the fix §13 had to make three
times before it stuck — the widest gap is **15.4 in.** against the deck's 24 in.
span:

| Station | −34.0 (`BW`) | −18.66 | −3.31 | 3.75 (`BWI-2`) |
|---|---:|---:|---:|---:|
| Gap to the next | 15.34 in. | 15.35 in. | 7.06 in. | — |

`_check_deck_span` in `owner_revisions.py` raises if that ever exceeds 24 in., so
the bay cannot quietly go back to being decked but unframed.

The before-demolition stage nets one member: two deleted shelf joists out, two
infill joists in, and one beam absorbed by the merge.

### The number to watch

`B-1A` now spans the full **245.5 in.** instead of 207.75, and it becomes the
softest member in the floor:

| Beam | Middle bay | **Stair south** |
|---|---:|---:|
| `B-1A` | 207.8 in. · L/574 | **245.5 in. · L/334** |
| `B-2` | 245.5 in. · L/372 | 245.5 in. · L/387 |
| `B-1` | 245.5 in. · L/376 | 207.8 in. · L/523 |
| `BE` | 331.0 in. · L/780 | 331.0 in. · L/780 |

The two beams trade places: `B-1` was the long one and is now the short one.

L/334 passes the L/240 total-load floor limit with room to spare and is not a
violation. It is softer than anything in the middle-bay arrangement (worst
L/372), because `B-1A` carries the wider of the two strips over the longer
span. It is recorded because it is the member to deepen if the bay is ever
wanted stiffer underfoot, and because nothing else in the floor is close to it.

### Two joists came out with it

`shelf SH joist 1` and `shelf SH joist 2` spanned from `B-S` up to `B-1`.
Cutting `B-1` back left their north ends in mid-air — the eigenvalue solver
flagged them as unstable nodes before any drawing would have. They stand inside
the new stair opening in any case, so they are deleted rather than re-supported.

This is the same class of error as §13: the geometry change was drawn correctly
and the consequence two members away was not visible in the drawing.

### Opening area

The opening grows slightly, from 29.9 sf to **32.8 sf** — the south bay is the
longer of the two. That is a stair-design input, not a structural one, and the
headroom over the run has not been checked here.

## 11. Second post in the north wall — the loading opening cut to 6 ft

Owner revision. Above the loft the north wall is carried by three posts: `W4` at
x = −34, `N-M` at x = 88.75 and `N2` at x = 211.5. The bay from `W4` to `N-M` is
**122.75 in. of nothing** — the loading opening.

`N-M2` is added at **x = 16.75**, 6 ft west of `N-M`, as that post's twin: same
`HSS4X4X1/4`, same group, standing on `B-N` and carrying `R-W4` over the same
120.75 in. The opening becomes the 6 ft the owner wants, and the **50.75 in.
from `N-M2` to `W4` is walled**.

### It costs one post and pays for itself in stiffness

| | Before | After |
|---|---:|---:|
| Worst utilisation | 0.777 | **0.777** |
| Wind drift | H/431 | **H/434** |
| Deflection violations | 0 | 0 |
| Steel | 8,002 lb | 8,047 lb (+45) |
| Pieces / fitted joints | 57 / 102 | 58 / 104 |
| Cost (mid) | $25,382 | $25,628 (+$246) |

Halving a 122.75 in. span of `R-W4` is worth slightly more than the post costs in
utilisation and drift, which is why both numbers move the right way.

### The dead load does not change

`surfaces.py` already models the north wall as **a solid rectangle from sill to
roof** — the loading opening lives in the label, not in the outline. The cladding
over that bay has therefore been carried in every analysis run to date. Walling
it is load the frame was already designed for, and the post is a pure addition.

That is conservative in the right direction, but it should be said plainly: the
model has never taken credit for the opening, so none of the wind or gravity
results above change when the opening closes.

## 12. Limits

Gravity, wind and a seismic screening check only. No connection, base plate, anchor
or foundation is designed. Costs are parametric estimates on this project's own
rates, not quotations; the ranges are wide and the differences between options are
more reliable than the totals. Every reduction here is conditional on the
100 psf live load of DEC-014 and on the concentrated equipment loads of ASM-011,
which remain open.

---

_Generated by `structural-analysis-v6/cost.py`, `spacing.py` and `studies.py` from
`frame-models/frame-20260920.01-beam-scheme.compas.json`._

## 13. Correction history

**Revision 1, 2026-09-18.** Revision 0 reported 46 removable members including 33
floor joists, and a $7,220 saving. The deck-span check that should have caught it
failed three times over, each fix exposing the next:

1. It grouped all 54 joists as **one set** measured across the building, so
   deleting every joist in one shelf did not widen that set's spacing — joists in
   the other decks stood at the same stations. Fixed by keying sets to the deck
   rectangle the model declares.
2. It allowed each set its own as-drawn worst gap as precedent. Across a single
   set that meant the 27 in. walkway between two shelves licensed 27 in. holes in
   the middle of a floor. Fixed by applying that allowance per deck, where it is
   correct, rather than across the floor.
3. It measured only **between** surviving joists, never out to the deck edge, so
   deleting the joists at one end of a shelf left three feet of deck cantilevered
   over nothing while the check read 14.8 in. Fixed by including the framed deck
   edges in the measurement.

The frame solver never objected at any stage, because there are no plates in the
model: with the joists gone the tributary machinery handed the floor load straight
to the beams, and the beams could carry it. Nothing in a bare frame analysis knows
whether there is anything left for the sheathing to sit on. That is the standing
limitation behind this whole study, not a one-off.

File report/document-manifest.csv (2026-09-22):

document_id | section | title | status | discipline | required_for | authoritative_source | report_path | working_source | last_verified | notes
CTRL-001 | 00 | Master report index | draft | Project controls | All issues | Project record | 00-report-index.md |  | 2026-09-15 | Update whenever controlled content or status changes
CTRL-002 | 00 | Document requirements | draft | Project controls | All issues | Project record | 00-project-controls/document-requirements.md |  | 2026-09-15 | Content specification for full document set
CTRL-003 | 00 | Decision log | draft | Project controls | All issues | Owner and design-team decisions | 00-project-controls/decision-log.md |  | 2026-09-15 | Add only adopted decisions
CTRL-004 | 00 | Assumptions register | draft | Project controls | All issues | Project record | 00-project-controls/assumptions-register.md |  | 2026-09-15 | Close assumptions with documented evidence
CTRL-005 | 00 | Open items register | draft | Project controls | All issues | Project record | 00-project-controls/open-items.md |  | 2026-09-15 | Track design-controlling unknowns
DEF-001 | 01 | Owner project brief | planned | Architectural | Design development | Owner | 01-project-definition/project-brief.md |  |  | Define legal use scope and performance goals
DEF-002 | 01 | Basis of design | planned | Multidiscipline | Design development | Coordinated design team | 01-project-definition/basis-of-design.pdf |  |  | Freeze controlling geometry criteria and systems
EX-001 | 02 | Boundary and topographic survey | planned | Survey | Permit and construction | Licensed surveyor | 02-existing-conditions/boundary-topographic-survey.pdf |  |  | Must show utilities trees grades and improvements
EX-002 | 02 | Measured existing-condition drawings | planned | Architectural | Design development | Field survey | 02-existing-conditions/existing-condition-drawings.pdf | ../data/model/garage.FCStd |  | Working CAD is not a field-certified survey
EX-003 | 02 | Existing structural condition assessment | planned | Structural | Structural design | Licensed structural engineer | 02-existing-conditions/structural-condition-assessment.pdf |  |  | Include slab walls foundations roof and prior lofts
EX-004 | 02 | Existing photo log | planned | Architectural | Design development | Field photographs | 02-existing-conditions/photo-log.pdf | ../render/20260908.01-existing-site/references/ |  | Key photos to surveyed plan
EX-005 | 02 | Utility and overhead-line exhibit | planned | Survey/Electrical | Design development | Survey and utility records | 02-existing-conditions/utility-exhibit.pdf |  |  | Include clearances and service equipment
EX-006 | 02 | Tree and vegetation inventory | planned | Site/Arborist | Construction planning | Survey and arborist field review | 02-existing-conditions/tree-inventory.pdf | ../render/20260908.01-existing-site/site-with-trees.png |  | Determine public/private status and protection
LAND-001 | 03 | Parcel zoning and overlay report | planned | Planning | Design development | City parcel and zoning records | 03-land-use-and-permitting/parcel-zoning-overlay-report.pdf |  |  | Verify exact address/APN/base zone/overlays
LAND-002 | 03 | Setback height FAR and lot coverage analysis | planned | Planning/Architectural | Design freeze | Survey and Municipal Code | 03-land-use-and-permitting/development-regulations.pdf |  |  | Owner-provided 5-ft setback is unverified
LAND-003 | 03 | Permit and agency matrix | planned | Architectural | Permit planning | City/utility requirements | 03-land-use-and-permitting/permit-matrix.md |  |  | Include coastal determination and PV/ESS
LAND-004 | 03 | Permit history and existing legal status | planned | Planning | Permit planning | City permit records | 03-land-use-and-permitting/permit-history.pdf |  |  | Reconcile prior garage and loft work
LAND-005 | 03 | Setbacks retained garage and proposed storage roof | draft | Planning/Architectural | Design development and City interpretation | SDMC official GIS City bulletins and owner statements | 03-land-use-and-permitting/setbacks-and-roof-findings.md | September 2026 research; local sources listed in document | 2026-09-15 | Revision 0; editable Markdown research record; no permit approval or certified survey
GEO-001 | 04 | Geotechnical investigation or documented waiver basis | planned | Geotechnical | Foundation design | Licensed geotechnical professional/City criteria | 04-geotechnical-and-foundations/geotechnical-report.pdf |  |  | Need determined from parcel hazards soil and field conditions
GEO-002 | 04 | Foundation design criteria | planned | Geotechnical/Structural | Structural design | Geotechnical report and structural calculations | 04-geotechnical-and-foundations/foundation-criteria.pdf |  |  | Include bearing lateral uplift settlement and corrosion
ARCH-001 | 05 | Selected architectural design narrative | planned | Architectural | Design freeze | Owner and architect | 05-architectural-design/design-narrative.md |  |  | Separate adopted design from alternatives
ARCH-002 | 05 | Architectural drawing set | planned | Architectural | Permit/construction | Coordinated CAD and survey | 05-architectural-design/architectural-drawings.pdf | ../studies/20260915.01-roof-options/south-post-solar-clerestory.pdf |  | Plans roof plan elevations sections details schedules
ARCH-003 | 05 | Architectural editable model | planned | Architectural | Design coordination | Coordinated CAD | 05-architectural-design/garage-proposed.FCStd | ../studies/20260911.01-structural-optimization/exposed-frame/Garage-Exposed-Steel.FCStd |  | Current candidate requires geometry reconciliation
ARCH-004 | 05 | Architectural exchange model | planned | Architectural | Design coordination | Coordinated CAD | 05-architectural-design/garage-proposed.step | ../studies/20260911.01-structural-optimization/exposed-frame/Garage-Exposed-Steel.step |  | Export from accepted native model
ARCH-005 | 05 | Selected renderings | planned | Architectural | Owner/design review | Accepted model | 05-architectural-design/renderings.pdf | ../studies/20260911.01-structural-optimization/exposed-frame/01-southwest.png |  | Illustrative only
ARCH-006 | 05 | Combined floor plan study | draft | Architectural/Structural | Owner/design review | Owner-directed study; sources in study README | 05-architectural-design/floor-plan-study/floor-plan-study.pdf | ../studies/20260915.04-floor-plan-setbacks/draw_floor_plan_study.py | 2026-09-15 | Revision 4; optional east-wall framing; prior duplicate/history files removed per DEC-011; SHA256 79721362af3c17cfa34201010cfad8daf4fb0dde67fea54128d5a54be56a869b
ARCH-006-A01 | 05 | floor-plan-study.png | draft | Architectural/Structural | Owner/design review | Owner-directed study; sources in study README | 05-architectural-design/floor-plan-study/floor-plan-study.png | ../studies/20260915.04-floor-plan-setbacks/draw_floor_plan_study.py | 2026-09-15 | Revision 4; optional east-wall framing; prior duplicate/history files removed per DEC-011; SHA256 c95f31b4044071f40885d2d0f8485362c1d7308848087c1fbc86cc608e383e40
ARCH-006-A02 | 05 | floor-plan-study.svg | draft | Architectural/Structural | Owner/design review | Owner-directed study; sources in study README | 05-architectural-design/floor-plan-study/floor-plan-study.svg | ../studies/20260915.04-floor-plan-setbacks/draw_floor_plan_study.py | 2026-09-15 | Revision 4; optional east-wall framing; prior duplicate/history files removed per DEC-011; SHA256 62a173ee2a1e37d71c6cbb24fa4cdbb73e2901c2ba3d6d3afcdba83ca5243fe3
ARCH-006-A03 | 05 | basis.json | draft | Architectural/Structural | Owner/design review | Owner-directed study; sources in study README | 05-architectural-design/floor-plan-study/basis.json | ../studies/20260915.04-floor-plan-setbacks/draw_floor_plan_study.py | 2026-09-15 | Revision 4; optional east-wall framing; prior duplicate/history files removed per DEC-011; SHA256 3c62638984d76b2e05e4b240274b6f4f49064f4ee7e25c816eec3781acfb8df2
ARCH-006-A04 | 05 | README.md | draft | Architectural/Structural | Owner/design review | Owner-directed study; sources in study README | 05-architectural-design/floor-plan-study/README.md | ../studies/20260915.04-floor-plan-setbacks/publish_clean_study.py | 2026-09-15 | Revision 4; optional east-wall framing; prior duplicate/history files removed per DEC-011; SHA256 e5aaf4c3d2fde499276cc13c731dd38dd07743541ffb05f85cf40a2ce07966c8
STR-001 | 06 | Structural basis of design | planned | Structural | Design freeze | Licensed structural engineer | 06-structural-engineering/structural-basis-of-design.pdf |  |  | Loads materials criteria and model assumptions
STR-002 | 06 | Global analysis and load take-down | planned | Structural | Permit/construction | Licensed structural engineer | 06-structural-engineering/global-analysis.pdf | ../studies/20260911.01-structural-optimization/network-analysis/ |  | Must match accepted geometry and foundations
STR-003 | 06 | Truss beam column and connection calculations | planned | Structural | Permit/construction | Licensed structural engineer | 06-structural-engineering/member-connection-calculations.pdf | ../studies/20260908.03-structural-analysis-v3/truss-design-and-calculations.pdf |  | Prior package is preliminary and may use superseded geometry
STR-004 | 06 | Structural drawing set | planned | Structural | Permit/construction | Licensed structural engineer | 06-structural-engineering/structural-drawings.pdf |  |  | Plans elevations sections schedules and details
STR-005 | 06 | Hoist trolley and jib design criteria | planned | Structural/Equipment | Procurement and structural design | Manufacturer and engineer | 06-structural-engineering/hoist-trolley-jib-criteria.pdf |  |  | Nominal 1000-lb lifted load is owner criterion
STR-006 | 06 | Coordinated frame geometry study | draft | Structural | Owner review and structural geometry handoff | Owner-directed geometry; source-inventory.csv; no structural adequacy claim | 06-structural-engineering/frame-geometry-study/frame-geometry-study.pdf | ../studies/20260917.01-compas-frame/coordinated_study.py; ../studies/20260917.01-compas-frame/publish_report.py | 2026-09-15 | Revision 0; geometry checks only; SHA256 eb8f8d86cd114fa5164b3a3d463821fc2c6140743c47896c7a4b9988cfc5d567
STR-006-A01 | 06 | README.md | draft | Structural | Owner review and structural geometry handoff | Owner-directed geometry; source-inventory.csv; no structural adequacy claim | 06-structural-engineering/frame-geometry-study/README.md | ../studies/20260917.01-compas-frame/coordinated_study.py; ../studies/20260917.01-compas-frame/publish_report.py | 2026-09-15 | Revision 0; geometry checks only; SHA256 45ea10a2dd2e3290357c06b0f47acb35ccf1ebb4411e0ba1229254370e67b57b
STR-006-A02 | 06 | beam-and-truss-positions.csv | draft | Structural | Owner review and structural geometry handoff | Owner-directed geometry; source-inventory.csv; no structural adequacy claim | 06-structural-engineering/frame-geometry-study/beam-and-truss-positions.csv | ../studies/20260917.01-compas-frame/coordinated_study.py; ../studies/20260917.01-compas-frame/publish_report.py | 2026-09-15 | Revision 0; geometry checks only; SHA256 224f4b35eec69976fdd3bb6fe80cd192a5d8ce04cd04df89c7b6172851057963
STR-006-A03 | 06 | coordinated.compas.json | draft | Structural | Owner review and structural geometry handoff | Owner-directed geometry; source-inventory.csv; no structural adequacy claim | 06-structural-engineering/frame-geometry-study/coordinated.compas.json | ../studies/20260917.01-compas-frame/coordinated_study.py; ../studies/20260917.01-compas-frame/publish_report.py | 2026-09-15 | Revision 0; geometry checks only; SHA256 caec62cd38ab1313ed00852ef022c5fdce60d6e7c6c8224e3cdeb51b0f61bc73
STR-006-A04 | 06 | coordination-report.md | draft | Structural | Owner review and structural geometry handoff | Owner-directed geometry; source-inventory.csv; no structural adequacy claim | 06-structural-engineering/frame-geometry-study/coordination-report.md | ../studies/20260917.01-compas-frame/coordinated_study.py; ../studies/20260917.01-compas-frame/publish_report.py | 2026-09-15 | Revision 0; geometry checks only; SHA256 2102c121c90385ec74109fd2010f2af61c05a9d181c8bb52ec6ec888190e8a56
STR-006-A05 | 06 | floor-plan.png | draft | Structural | Owner review and structural geometry handoff | Owner-directed geometry; source-inventory.csv; no structural adequacy claim | 06-structural-engineering/frame-geometry-study/floor-plan.png | ../studies/20260917.01-compas-frame/coordinated_study.py; ../studies/20260917.01-compas-frame/publish_report.py | 2026-09-15 | Revision 0; geometry checks only; SHA256 185b2d0a875d5e62d808b5fa3d3dd11de1444a6c288df5897a7f98c7c40afedf
STR-006-A06 | 06 | frame-geometry.obj | draft | Structural | Owner review and structural geometry handoff | Owner-directed geometry; source-inventory.csv; no structural adequacy claim | 06-structural-engineering/frame-geometry-study/frame-geometry.obj | ../studies/20260917.01-compas-frame/coordinated_study.py; ../studies/20260917.01-compas-frame/publish_report.py | 2026-09-15 | Revision 0; geometry checks only; SHA256 06b63baa03f54a647ac019a3a9e0ac41fe51a0447b8e88444554b199ab88e482
STR-006-A07 | 06 | model-3d.html | draft | Structural | Owner review and structural geometry handoff | Owner-directed geometry; source-inventory.csv; no structural adequacy claim | 06-structural-engineering/frame-geometry-study/model-3d.html | ../studies/20260917.01-compas-frame/coordinated_study.py; ../studies/20260917.01-compas-frame/publish_report.py | 2026-09-15 | Revision 0; geometry checks only; SHA256 23200e98ba1d17f97bc60bcd724496c4d49622f486c8116c4347dc517799642a
STR-006-A08 | 06 | source-inventory.csv | draft | Structural | Owner review and structural geometry handoff | Owner-directed geometry; source-inventory.csv; no structural adequacy claim | 06-structural-engineering/frame-geometry-study/source-inventory.csv | ../studies/20260917.01-compas-frame/coordinated_study.py; ../studies/20260917.01-compas-frame/publish_report.py | 2026-09-15 | Revision 0; geometry checks only; SHA256 23df159ce4365023d4baee2165c75094c55191100e74ce02b5a85837790fba6b
STR-006-A09 | 06 | support-offsets.csv | draft | Structural | Owner review and structural geometry handoff | Owner-directed geometry; source-inventory.csv; no structural adequacy claim | 06-structural-engineering/frame-geometry-study/support-offsets.csv | ../studies/20260917.01-compas-frame/coordinated_study.py; ../studies/20260917.01-compas-frame/publish_report.py | 2026-09-15 | Revision 0; geometry checks only; SHA256 8789bb3d98ed8bd7c12f12b91dae9b7a762db7008dfd815cc5e882b1fedb1ffa
STR-006-A10 | 06 | support-positions.csv | draft | Structural | Owner review and structural geometry handoff | Owner-directed geometry; source-inventory.csv; no structural adequacy claim | 06-structural-engineering/frame-geometry-study/support-positions.csv | ../studies/20260917.01-compas-frame/coordinated_study.py; ../studies/20260917.01-compas-frame/publish_report.py | 2026-09-15 | Revision 0; geometry checks only; SHA256 20ca59b017769b6ca8fd2276432780b9f24a0b6061cbabe9be4c0067405ade16
STR-006-A11 | 06 | truss-members.csv | draft | Structural | Owner review and structural geometry handoff | Owner-directed geometry; source-inventory.csv; no structural adequacy claim | 06-structural-engineering/frame-geometry-study/truss-members.csv | ../studies/20260917.01-compas-frame/coordinated_study.py; ../studies/20260917.01-compas-frame/publish_report.py | 2026-09-15 | Revision 0; geometry checks only; SHA256 101996056c81252ada80266eeabf4c215b5e031c422419807aa3dec1fb242044
STR-006-A12 | 06 | validation.json | draft | Structural | Owner review and structural geometry handoff | Owner-directed geometry; source-inventory.csv; no structural adequacy claim | 06-structural-engineering/frame-geometry-study/validation.json | ../studies/20260917.01-compas-frame/coordinated_study.py; ../studies/20260917.01-compas-frame/publish_report.py | 2026-09-15 | Revision 0; geometry checks only; SHA256 c5fa8e26c386817e4c82f60481a3833834c43b44b28ff1c3a9fd8baabf2dbb26
STR-007 | 06 | Frame finite element analysis and member optimisation study | draft | Structural | Owner review and structural engineering handoff | Preliminary engineering analysis by the project team; no structural adequacy is certified and no connection or foundation is designed | 06-structural-engineering/fea-study/structural-analysis.md | ../src/structural-analysis-v6/run_all.py; ../src/structural-analysis-v6/publish.py | 2026-09-18 | Revision 0; SHA256 41cece4ba2481af7efbc0eefc8017f1f34a0f9bca5b7a2c23521f1644e310354
STR-007-A01 | 06 | README.md | draft | Structural | Owner review and structural engineering handoff | Preliminary engineering analysis by the project team; no structural adequacy is certified and no connection or foundation is designed | 06-structural-engineering/fea-study/README.md | ../src/structural-analysis-v6/run_all.py; ../src/structural-analysis-v6/publish.py | 2026-09-18 | Revision 0; SHA256 62215cef96a1a257a9d53474dd06f0ed8ec9329dc235f49be56c3cac07ba08ba
STR-007-A02 | 06 | design-load-basis.md | draft | Structural | Owner review and structural engineering handoff | Preliminary engineering analysis by the project team; no structural adequacy is certified and no connection or foundation is designed | 06-structural-engineering/fea-study/design-load-basis.md | ../src/structural-analysis-v6/run_all.py; ../src/structural-analysis-v6/publish.py | 2026-09-18 | Revision 0; SHA256 5422b6c17e610c5e8c48ff8abaad2650b1f9503ee55558297da363e7b3bfd37f
STR-007-A03 | 06 | fea-model-3d.html | draft | Structural | Owner review and structural engineering handoff | Preliminary engineering analysis by the project team; no structural adequacy is certified and no connection or foundation is designed | 06-structural-engineering/fea-study/fea-model-3d.html | ../src/structural-analysis-v6/run_all.py; ../src/structural-analysis-v6/publish.py | 2026-09-18 | Revision 0; SHA256 6c0fd4547845761356e8db0be5283048932d2cb0e1978d05ba6a9c3f9db72950
STR-007-A04 | 06 | figures/opportunity-map.png | draft | Structural | Owner review and structural engineering handoff | Preliminary engineering analysis by the project team; no structural adequacy is certified and no connection or foundation is designed | 06-structural-engineering/fea-study/figures/opportunity-map.png | ../src/structural-analysis-v6/run_all.py; ../src/structural-analysis-v6/publish.py | 2026-09-18 | Revision 0; SHA256 3ebacfe3715b53ec76fd767e68b27ef96b1167ce27405be145e5f590759f8d48
STR-007-A05 | 06 | figures/utilisation-adequate.png | draft | Structural | Owner review and structural engineering handoff | Preliminary engineering analysis by the project team; no structural adequacy is certified and no connection or foundation is designed | 06-structural-engineering/fea-study/figures/utilisation-adequate.png | ../src/structural-analysis-v6/run_all.py; ../src/structural-analysis-v6/publish.py | 2026-09-18 | Revision 0; SHA256 21e1e9b743b186bda8996471cc1c25b16fe8016a20dfb87b483a6fc20b4a34de
STR-007-A06 | 06 | figures/utilisation-as-drawn.png | draft | Structural | Owner review and structural engineering handoff | Preliminary engineering analysis by the project team; no structural adequacy is certified and no connection or foundation is designed | 06-structural-engineering/fea-study/figures/utilisation-as-drawn.png | ../src/structural-analysis-v6/run_all.py; ../src/structural-analysis-v6/publish.py | 2026-09-18 | Revision 0; SHA256 2f72240f1d95238e23b3398567290a6bf3f51ee7b5c6df738162cc5aa77bafc7
STR-007-A07 | 06 | figures/utilisation-histogram.png | draft | Structural | Owner review and structural engineering handoff | Preliminary engineering analysis by the project team; no structural adequacy is certified and no connection or foundation is designed | 06-structural-engineering/fea-study/figures/utilisation-histogram.png | ../src/structural-analysis-v6/run_all.py; ../src/structural-analysis-v6/publish.py | 2026-09-18 | Revision 0; SHA256 498217854eb7490eb22fae3f14b145f99a28ac679254141a77da8b8163f230ce
STR-007-A08 | 06 | figures/utilisation.png | draft | Structural | Owner review and structural engineering handoff | Preliminary engineering analysis by the project team; no structural adequacy is certified and no connection or foundation is designed | 06-structural-engineering/fea-study/figures/utilisation.png | ../src/structural-analysis-v6/run_all.py; ../src/structural-analysis-v6/publish.py | 2026-09-18 | Revision 0; SHA256 9a74b11b6569aa95ee519dfd3745b40b434b70aaa741065e3707601ead796f53
STR-007-A09 | 06 | figures/weight-by-group.png | draft | Structural | Owner review and structural engineering handoff | Preliminary engineering analysis by the project team; no structural adequacy is certified and no connection or foundation is designed | 06-structural-engineering/fea-study/figures/weight-by-group.png | ../src/structural-analysis-v6/run_all.py; ../src/structural-analysis-v6/publish.py | 2026-09-18 | Revision 0; SHA256 b147339768c6235be6f55cf7041665fc7b382c471ba221de409a9baa962bba5c
STR-007-A10 | 06 | findings.csv | draft | Structural | Owner review and structural engineering handoff | Preliminary engineering analysis by the project team; no structural adequacy is certified and no connection or foundation is designed | 06-structural-engineering/fea-study/findings.csv | ../src/structural-analysis-v6/run_all.py; ../src/structural-analysis-v6/publish.py | 2026-09-18 | Revision 0; SHA256 7e3721e73424a77dd7bc0739f92dc8df97c239a93b6c78dec925c863b766f6e4
STR-007-A11 | 06 | load-cases.csv | draft | Structural | Owner review and structural engineering handoff | Preliminary engineering analysis by the project team; no structural adequacy is certified and no connection or foundation is designed | 06-structural-engineering/fea-study/load-cases.csv | ../src/structural-analysis-v6/run_all.py; ../src/structural-analysis-v6/publish.py | 2026-09-18 | Revision 0; SHA256 ec2a197489cec4a0801167f6b45134774e75a09011bbef0b2fec1a1c3af831f8
STR-007-A12 | 06 | member-schedule.csv | draft | Structural | Owner review and structural engineering handoff | Preliminary engineering analysis by the project team; no structural adequacy is certified and no connection or foundation is designed | 06-structural-engineering/fea-study/member-schedule.csv | ../src/structural-analysis-v6/run_all.py; ../src/structural-analysis-v6/publish.py | 2026-09-18 | Revision 0; SHA256 c3ade2fb45a97402a546658e48ad18b84a07d16023ee98073f7d698b50c71fb1
STR-007-A13 | 06 | reactions.csv | draft | Structural | Owner review and structural engineering handoff | Preliminary engineering analysis by the project team; no structural adequacy is certified and no connection or foundation is designed | 06-structural-engineering/fea-study/reactions.csv | ../src/structural-analysis-v6/run_all.py; ../src/structural-analysis-v6/publish.py | 2026-09-18 | Revision 0; SHA256 3c9b1cbd7bf55f5c6dd3e5d507c4d0e338b1ec1bc1d6215acfa56015128bb8f9
STR-007-A14 | 06 | results.json | draft | Structural | Owner review and structural engineering handoff | Preliminary engineering analysis by the project team; no structural adequacy is certified and no connection or foundation is designed | 06-structural-engineering/fea-study/results.json | ../src/structural-analysis-v6/run_all.py; ../src/structural-analysis-v6/publish.py | 2026-09-18 | Revision 0; SHA256 4a9ac92b59eac3c06562ea8ec8dcd41f4cc08042138a3740092224693e8e93ae
STR-007-A15 | 06 | source-inventory.csv | draft | Structural | Owner review and structural engineering handoff | Preliminary engineering analysis by the project team; no structural adequacy is certified and no connection or foundation is designed | 06-structural-engineering/fea-study/source-inventory.csv | ../src/structural-analysis-v6/run_all.py; ../src/structural-analysis-v6/publish.py | 2026-09-18 | Revision 0; SHA256 927968babf0b4b9ef94d2790c5576d55cc2a4432b2bb04ea7f218a42ef5e437f
STR-008 | 06 | Frame cost reduction study | draft | Structural | Owner cost decisions and scheme selection | Preliminary engineering study on project rates; not a quotation | 06-structural-engineering/cost-reduction/cost-reduction-study.md | ../src/structural-analysis-v6/cost.py; ../src/structural-analysis-v6/make_view.py | 2026-09-18 | Revision 1; supersedes revision 0, which proposed deleting floor joists in error; SHA256 5074a707a0a6810ae1cee15be5add560a6616b6dcdbf5d1f054e8cd7114f8c8b
STR-008-A01 | 06 | cost-reduction-3d.html | draft | Structural | Owner cost decisions and scheme selection | Preliminary engineering study on project rates; not a quotation | 06-structural-engineering/cost-reduction/cost-reduction-3d.html | ../src/structural-analysis-v6/cost.py; ../src/structural-analysis-v6/make_view.py | 2026-09-18 | Revision 1; supersedes revision 0, which proposed deleting floor joists in error; SHA256 a0a63ed5b3fb79d783729ee9548aa6c90599ea5c6eb00d84d1a2acbc669e173e
STR-008-A02 | 06 | cost-reduction-3d-solid.html | draft | Structural | Owner cost decisions and scheme selection | Preliminary engineering study on project rates; not a quotation | 06-structural-engineering/cost-reduction/cost-reduction-3d-solid.html | ../src/structural-analysis-v6/solid_view.py | 2026-09-18 | Revision 1; members extruded at true section size; SHA256 3a804b775ad74f896aa64bd2f45daefe6d5848fa6d5d3575ab2372bdb2e4fc13
ENV-001 | 07 | Envelope basis and assembly schedule | planned | Architectural/Envelope | Design development | Coordinated products and code | 07-building-envelope/envelope-basis.pdf |  |  | Roof walls insulation condensation corrosion
ENV-002 | 07 | Waterproofing drainage and flashing details | planned | Architectural/Envelope | Construction | Coordinated design | 07-building-envelope/envelope-details.pdf |  |  | Include PV roof hip cap balcony and existing transitions
ENV-003 | 07 | Infill wall panel options: materials, attachment, and structural role | draft | Envelope/Architectural | Design development | Published manufacturer, trade-association, standards-body and trade-press sources accessed 2026-09-17; see study section 11 | 07-building-envelope/wall-panel-options/wall-panel-options.md | (desk research; no generator) | 2026-09-17 | Revision 1; owner-directed market and materials survey; research only; no product selection, structural design, code determination or quotation; prices are published market ranges; raises ENV-OI-01..12; rev 1 adds section 8A applying the coastal-corrosion finding to the roof; SHA256 06b07151a96db05498004f651a44bf2c07850e82dae2aad47f4343c525a504d2
ENV-A003 | 07 | README.md | draft | Envelope/Architectural | Design development | See ENV-003 section 11 sources | 07-building-envelope/wall-panel-options/README.md | (desk research; no generator) | 2026-09-17 | Supporting artifact for ENV-003 rev 0; SHA256 a9d577d1ad3dae13e1dbd3e2fb203bd40792204a827f41e27e4986466c629b57
SOL-001 | 08 | Solar battery sizing and 30-35-40 degree roof analysis | draft | Energy | Design development | Weather/utility/manufacturer data | 08-solar-electrical-and-energy/solar-energy-report.pdf | ../studies/20260915.03-solar/chapter8/build_report.py; ../studies/20260915.03-solar/chapter8/analyze_chapter.py | 2026-09-15 | Revision 1; owner-review draft; 325 sqft gross face; includes historical gallery; tariff layout and costs provisional
SOL-002 | 08 | PV and ESS permit drawing set | planned | Electrical/Solar | Permit/construction | Electrical designer and manufacturer data | 08-solar-electrical-and-energy/pv-ess-drawings.pdf |  |  | Layout one-line equipment labels pathways and attachment
SOL-003 | 08 | Utility interconnection package | planned | Electrical/Solar | Utility approval | Utility requirements | 08-solar-electrical-and-energy/interconnection-package.pdf |  |  | Record current tariff/export assumptions
SOL-A001 | 08 | README.md | draft | Energy/Architectural | Design development | See SOL-001 references and source-inventory.csv | 08-solar-electrical-and-energy/README.md | ../studies/20260915.03-solar/chapter8/build_report.py | 2026-09-15 | Supporting artifact for SOL-001 rev 1; SHA256 cd0abe509f31c8b1f279de34ccf39f3022eef350535f7ab7dd852acf44f438c7
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

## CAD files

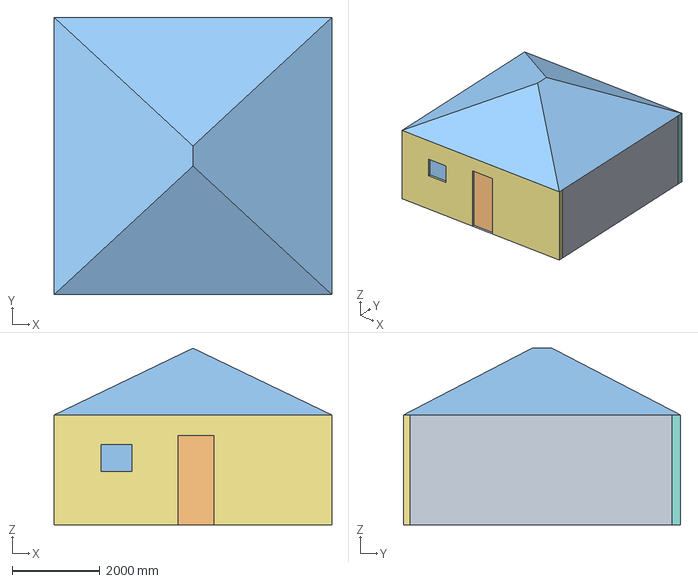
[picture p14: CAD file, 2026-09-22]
data/model/garage-existing.step
6337.3 x 6324.6 x 4025.9 mm

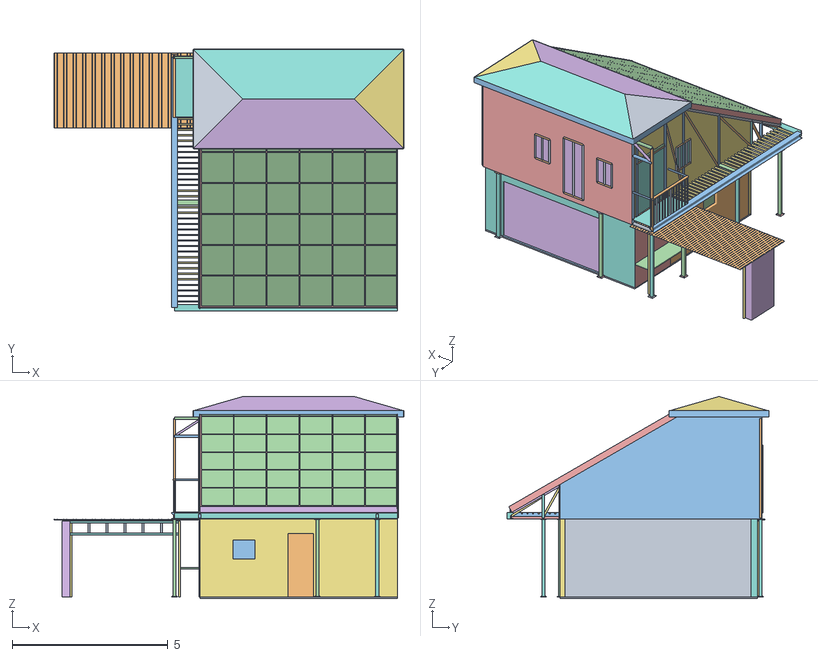
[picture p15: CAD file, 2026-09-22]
render/20260907.02-garage-model/garage-model.obj
11.2 x 8.39 x 6.48
Existing_garage_slab
South_entry_door_(assumed_height)
South_window_(confirmed_sill_and_height)
West_window_1_(confirmed_sill_and_height)
West_window_2_(confirmed_sill_and_height)
North_garage_door_(assumed_height)
South_window_opening
North_garage_door_opening
East_wall
West_window_2_opening
Floor_datum_surface_(no_thickness_specified)
W1_steel_column
W1_base_plate
W1_cap_plate
W1_anchor
W2_steel_column
W2_base_plate
W2_cap_plate
W2_anchor
W3_steel_column
W3_base_plate
W3_cap_plate
W3_anchor
W4_steel_column
W4_base_plate
W4_cap_plate
W4_anchor
S1_steel_column
S1_base_plate
S1_cap_plate
S1_anchor
S2_steel_column
S2_base_plate
S2_cap_plate
S2_anchor
N1_steel_column
N1_base_plate
N1_cap_plate
N1_anchor
N2_steel_column
N2_base_plate
N2_cap_plate
N2_anchor
S3_steel_column
S3_base_plate
S3_cap_plate
S3_anchor
T-SO_beam
B2_beam
B3_beam
B-WO_beam
O2
O3
T-S_bottom
T-S_top
T-S_upright
T-S_end_brace
T-S_joint_plate
T1_bottom
T1_top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

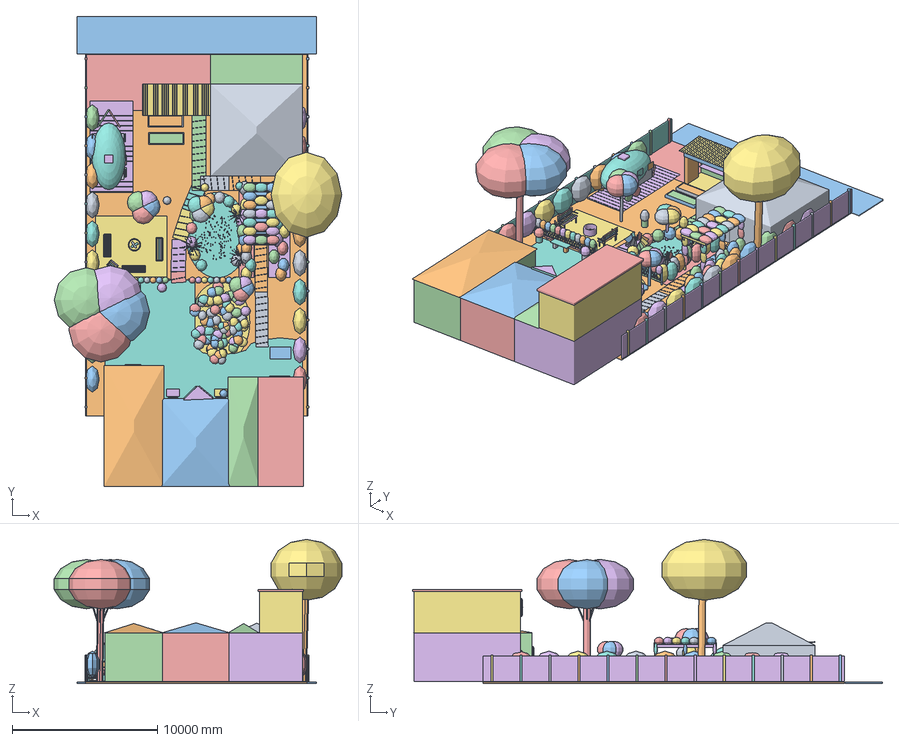
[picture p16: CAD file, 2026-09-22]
render/20260908.01-existing-site/existing-backyard.FCStd
19817.1 x 32380.0 x 9940.0 mm
Existing garage — measured source solid
Approximate backyard extent
Rear alley context
Garage driveway apron
Rear work patio
Trailer brick parking pad
Work shelter slab
House flagstone patio
East access path0
East access path1
East access path2
East access path3
Curving garden flagstone0
Curving garden flagstone1
Curving garden flagstone2
Curving garden flagstone3
Curving garden flagstone4
Curving garden flagstone5
Work shelter access0
Work shelter access1
Work shelter access2
Brick joint
Brick joint001
Brick joint002
Brick joint003
Brick joint004
Brick joint005
Brick joint006
Brick joint007
Brick joint008
Brick joint009
Brick joint010
Brick joint011
Brick joint012
Brick joint013
Brick joint014
Brick joint015
Brick joint016
Brick joint017
Flagstone joint
Flagstone joint001
Flagstone joint002
Flagstone joint003
Flagstone joint004
Flagstone joint005
Flagstone joint006
Flagstone joint007
Flagstone joint008
Flagstone joint009
Flagstone joint010
Flagstone joint011
Flagstone joint012
Flagstone joint013
Flagstone joint014
Flagstone joint015
Flagstone joint016
Flagstone joint017
Flagstone joint018
Flagstone joint019
Flagstone joint020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

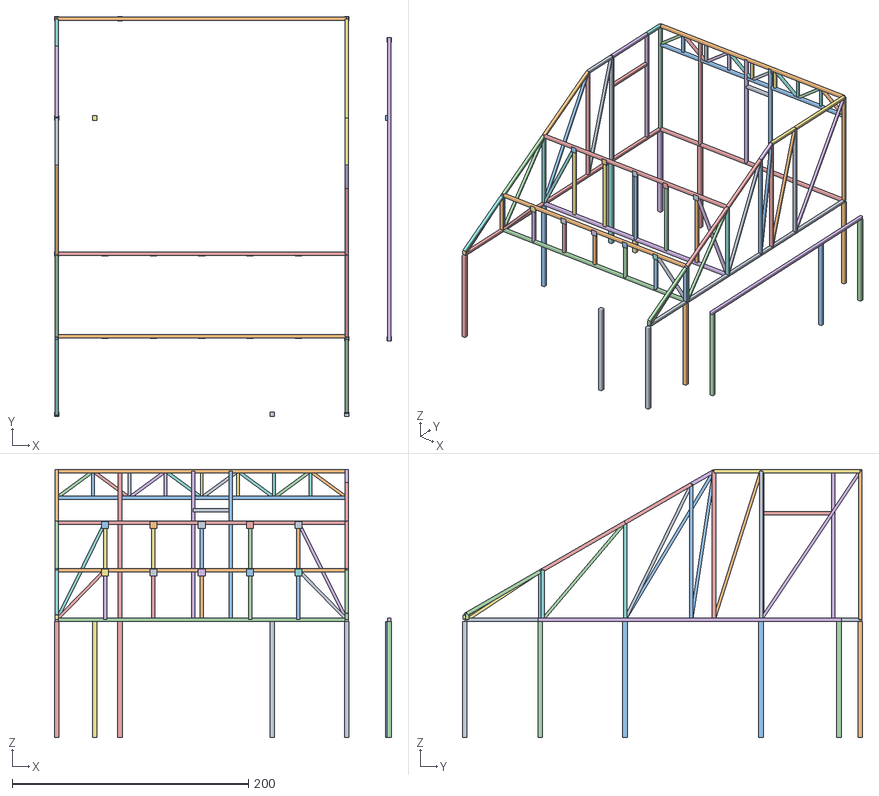
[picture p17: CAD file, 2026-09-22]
report/06-structural-engineering/frame-geometry-study/frame-geometry.obj
285.5 x 339.0 x 227.2
T-E.bottom.0
T-E.upright.7
T-E.web.4
T-E.top.0
T-E.top.3
T-E.top.4
T-E.top.6
T-E.upright.3
T-E.upright.6
T-E.upright.2
T-E.upright.4
T-E.web.2
T-E.top.2
T-E.top.1
T-E.web.0
T-E.web.1
T-E.web.3
T-E.web.5
T-E.upright.1
T-E.upright.0
T-E.upright.5
T-E.web.6
T-E.top.5
T-N.header_vertical.6
T-N.door_header.0
T-N.upright.4
T-N.header_vertical.1
T-N.header_brace.6
T-N.header_brace.1
T-N.header_vertical.3
T-N.header_vertical.5
T-N.header_brace.3
T-N.header_brace.4
T-N.header_brace.7
T-N.header_lower.0
T-N.upright.0
T-N.upright.1
T-N.header_brace.2
T-N.header_vertical.0
T-N.header_brace.5
T-N.header_vertical.2
T-N.top.0
T-N.upright.3
T-N.header_brace.0
T-N.bottom.0
T-N.upright.2
T-N.header_vertical.4
T-N.header_vertical.7
T-S.brace.1
T-S.upright.3
T-S.plate.3
T-S.upright.4
T-S.upright.2
T-S.upright.1
T-S.plate.0
T-S.upright.6
T-S.plate.1
T-S.top.0
T-S.upright.5
T-S.bottom.0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

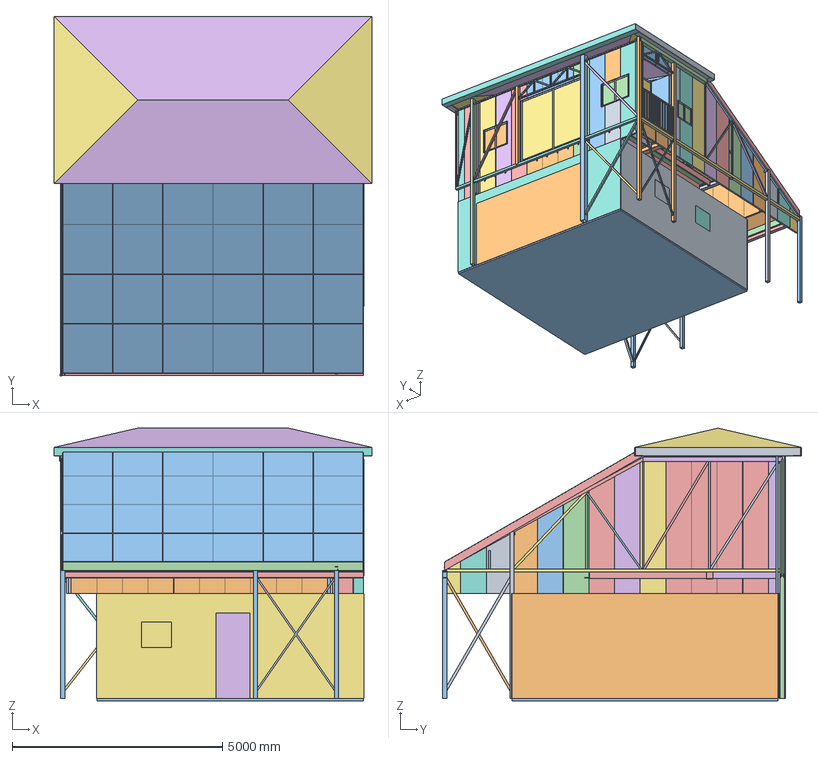
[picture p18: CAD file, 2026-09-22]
studies/20260911.01-structural-optimization/exposed-frame/Garage-Exposed-Steel.step
7556.5 x 8534.4 x 6483.4 mm

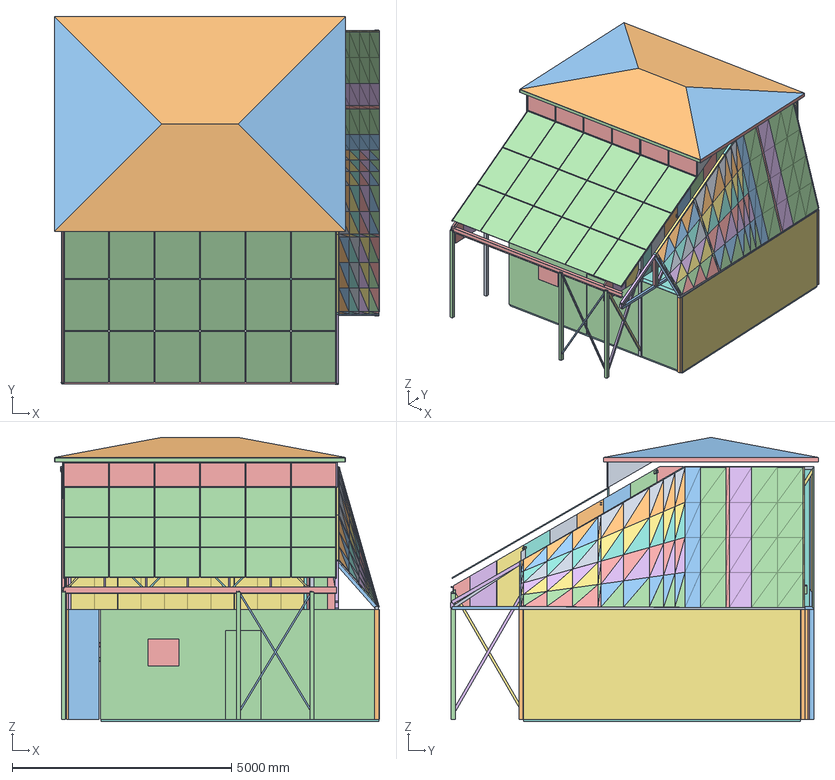
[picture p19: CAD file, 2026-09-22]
studies/20260916.01-roof/east-clerestory/garage-east-clerestory.step
7416.8 x 8394.7 x 6483.4 mm

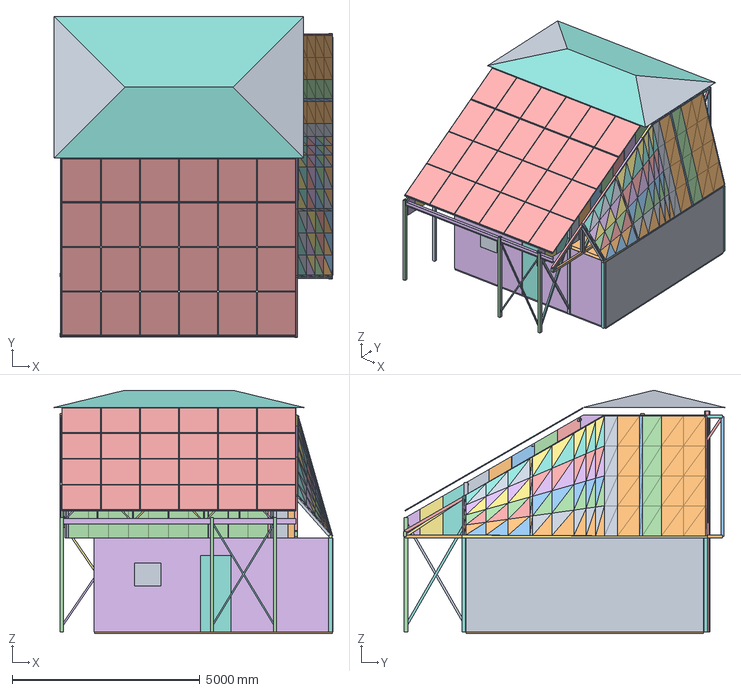
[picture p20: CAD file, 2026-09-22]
studies/20260916.01-roof/east-infill-skylights/garage-east-infill-skylights.step
7416.8 x 8547.1 x 6483.4 mm

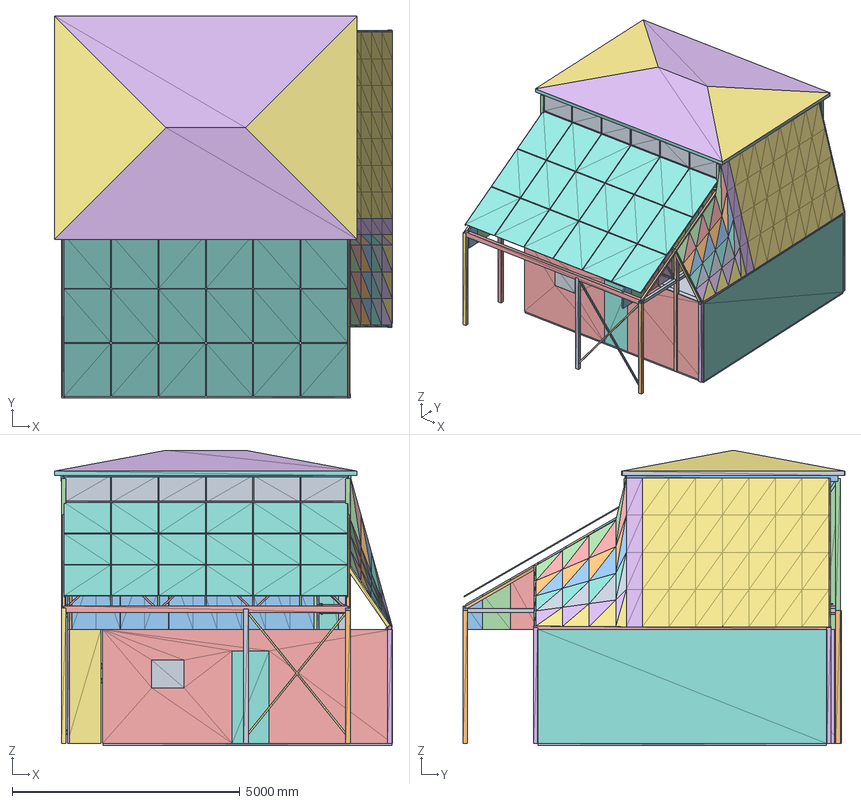
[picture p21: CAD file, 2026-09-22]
studies/20260916.01-roof/square-upper-west/connected-frame/garage-connected-frame.step
7416.8 x 8382.0 x 6483.4 mm

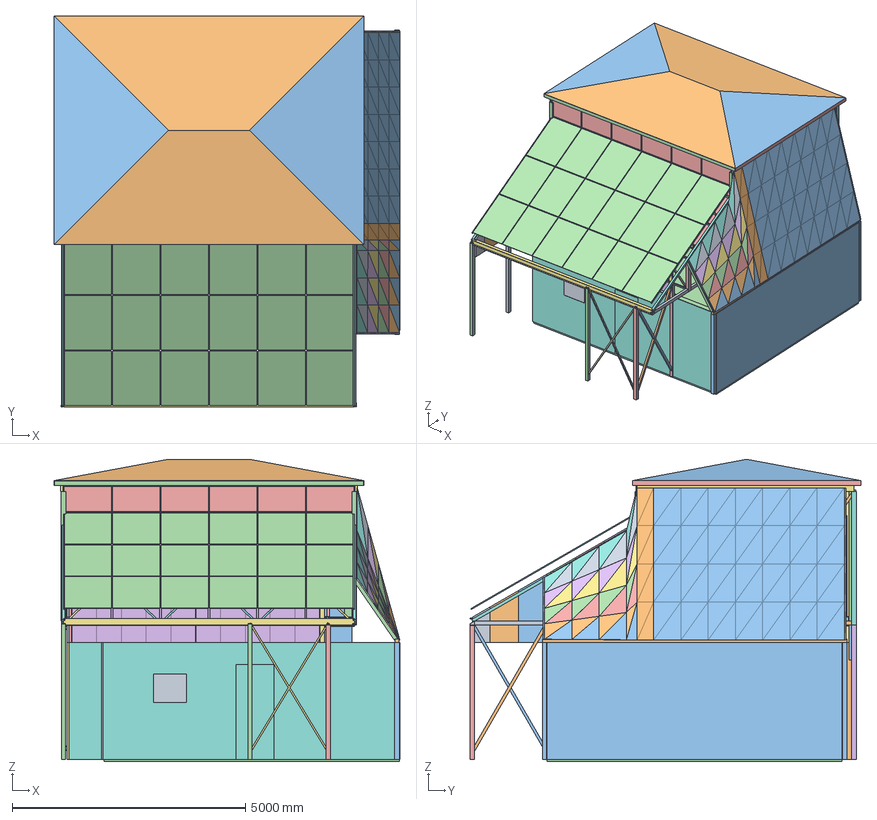
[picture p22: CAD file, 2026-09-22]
studies/20260916.01-roof/square-upper-west/garage-square-upper-west.step
7416.8 x 8382.0 x 6483.4 mm

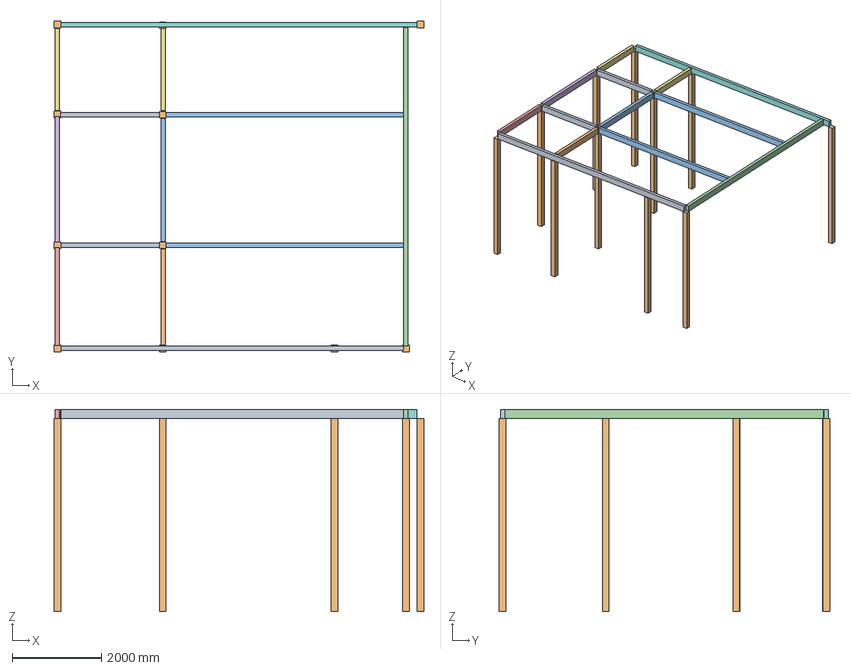
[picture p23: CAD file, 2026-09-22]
data/model/proposal-concept.step
8293.1 x 7410.4 x 4533.9 mm

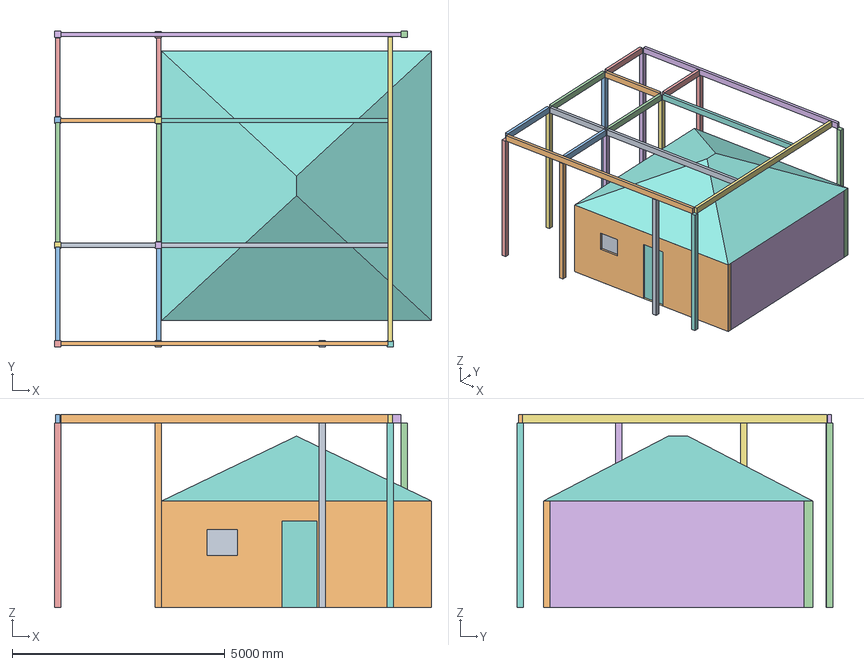
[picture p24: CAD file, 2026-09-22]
data/model/garage.FCStd
8851.9 x 7410.4 x 4533.9 mm
Beam Graphic_42
Beam Graphic_46
Beam Graphic_47
Beam Graphic_48
Beam Graphic_49
Beam Graphic_50
Beam Graphic_51
Beam Graphic_86
Beam Graphic_87
Beam Graphic_88
Beam Graphic_89
Beam Graphic_90
Beam Graphic_91
East wall
Floor datum surface (no thickness specified)
Existing hip roof envelope - 18 inch N-S ridge
North garage door (assumed height)
South window opening
West window 2 opening
North garage door opening
Post Graphic_30
Post Graphic_31
Post Graphic_32
Post Graphic_33
Post Graphic_34
Post Graphic_35
Post Graphic_36
Post Graphic_39
Post Graphic_83
Post Graphic_84
Post Graphic_85
South entry door (assumed height)
South window (confirmed sill and height)
West window 1 (confirmed sill and height)
West window 2 (confirmed sill and height)

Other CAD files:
data/model/garage-existing.obj
render/20260907.02-garage-model/garage-render-package/garage-site-hip-cap.blend
render/20260908.01-existing-site/existing-backyard.obj
render/20260908.03-garage-site/garage-site-hip-cap.blend
render/20260908.03-garage-site/garage-site.blend
render/20260908.03-garage-site/garage.blend
studies/20260911.01-structural-optimization/exposed-frame/Garage-Exposed-Steel.FCStd
studies/20260911.01-structural-optimization/exposed-frame/Garage-Exposed-Steel.blend
studies/20260916.01-roof/east-clerestory/garage-east-clerestory.FCStd
studies/20260916.01-roof/east-clerestory/garage-east-clerestory.blend
studies/20260916.01-roof/east-infill-skylights/garage-east-infill-skylights.FCStd
studies/20260916.01-roof/east-infill-skylights/garage-east-infill-skylights.blend
studies/20260916.01-roof/square-upper-west/connected-frame/garage-connected-frame.FCStd
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

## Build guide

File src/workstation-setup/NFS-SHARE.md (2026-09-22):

# Buzzkill project share

Server: buzzkill, current address 192.168.1.23. Export: /proj.
Mac client currently 192.168.1.40; only this address is authorized.
Server config: /etc/exports.d/garage-mac.exports.
Options: rw,sync,no_subtree_check,all_squash,anonuid=1002,anongid=1002.
NFS server installed and enabled. exportfs and showmount verified.

Intended Mac mount: /Volumes/Proj/Buzzkill-Proj.
Mount not yet completed: Finder stalled; direct mount requires administrator privileges and sudo needs user password.
Run `Connect Buzzkill.command` to complete TCP NFSv3 mount and test read/write. Re-run after reboot or unmount; no persistent automount configuration installed.
If either LAN address changes, update the export/client mount accordingly; reserve addresses in router if desired.

Existing Mac /Volumes/Proj/proj/CAD/garage has NOT been copied or moved. This share is Buzzkill's separate /proj directory.

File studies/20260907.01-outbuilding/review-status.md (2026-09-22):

# Outbuilding review status
User accepted the standalone dimension check as close enough for the analysis. Ground is not flat; existing approximate vertical geometry is intentionally retained. Beam-end interpretation and unknown heights are not promoted to measured facts.

Combined west elevations show both window options with the existing outbuilding in the foreground. Apparent roof/balcony clearance is not verified. Base shallow roof cap used; decorative cap alternatives remain separate. CAD remains unchanged pending design review.

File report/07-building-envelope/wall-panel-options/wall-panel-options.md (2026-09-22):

# ENV-003 — Infill wall panel options: materials, attachment, and structural role

**Document ID:** ENV-003 · **Revision:** 1 · **Date:** 2026-09-17 · **Status:** `draft`
**Section:** 07 Building Envelope
**Purpose:** Owner-directed market and materials survey for the inside-frame wall panels, including whether panels should be recruited for lateral stiffness, how they meet the exposed frame, and which sections could be glazed.
**Units:** inches unless noted. Frame geometry as [STR-006](../../06-structural-engineering/frame-geometry-study/README.md) revision 0.

> This is a research and options document. Nothing here is a product selection, a structural design, or a code determination. Every price is a published market range for comparison only, not a quotation. Any lateral-load role for the panels requires the responsible California-licensed structural engineer's design and sealing.

---

## 1. What this study answers

The recorded design direction ([DEC-004](../../00-project-controls/decision-log.md)) exposes the painted steel frame and places metal wall panels inside it. Four questions follow, and this study addresses each:

1. **Should the panels carry lateral load?** The frame currently does not rely on them. Section 5.
2. **Do the panels run continuous across the inside face, or sit inside each bay?** Section 4 — and this turns out to be the decision that constrains material choice more than anything else.
3. **What panel products actually exist, and what do they cost?** Sections 2, 3, 6.
4. **Which bays could be glass, and what glazing systems suit a 4-inch steel frame?** Section 7.

A fifth issue emerged during research and is treated as a finding rather than a question: **the site is in a marine corrosion zone, and this disqualifies the default substrate.** Section 8. Revision 1 carries that finding through to the roof at owner request, in section 8A.

---

## 2. The panel families, and where the current assumption sits

The market divides into six families. The project's current cost basis ([COST-ESTIMATE.md](../../../COST-ESTIMATE.md) Part 2, Item I) assumes family 3 — 2-inch insulated metal panel at $8–14/sq ft material, $6–10/sq ft installation, over 665 sq ft.

| # | Family | What it is | Fastener | Material $/sq ft | Interior-rated | Fits "textured/wavy" |
|---|---|---|---|---|---|---|
| 1 | **Single-skin exposed-fastener** | Roll-formed sheet: ⅞" corrugated, R/PBR panel, 7.2 box rib, 9.5 box rib | Exposed screws through the flat | $1–5 | Yes | Yes — the classic |
| 2 | **Single-skin concealed-fastener** | Flush / T-groove, reveal panel, board-and-batten, shiplap, wave, shadow rib, flat-lock | Clip and interlock | $3–5+ | Yes | Yes — subtler |
| 3 | **Insulated metal panel (IMP)** | Two steel skins bonded to a PIR or mineral-wool core; 2"–8" thick | Concealed tongue-and-groove | $8–14 | Yes | Light: Mesa, Light Mesa |
| 4 | **Metal composite (ACM/MCM)** | Two thin aluminum sheets on a solid core, routed and folded into cassettes | Concealed, rainscreen clips | $8–20 installed system | Yes | No — dead flat by nature |
| 5 | **Designer / custom-profile aluminum** | Deep or irregular corrugations on coated aluminum, optionally micro-perforated with acoustic backing | Clip | Premium, quote-only | Yes | Yes — the strongest option |
| 6 | **Liner panel** | Light ribbed 26/29-ga sheet meant for the inside of a metal building | Exposed | $2.00–2.50 | Yes (that is its job) | Mildly |

### On the "waviness" the owner described

Three distinct looks are available and they are not interchangeable:

- **⅞" corrugated** — sinusoidal, continuous, no flats. This is the recognisable wavy profile. Cheapest of everything at $1–3/sq ft material, universally stocked, impact-resistant, and reads as both agricultural and contemporary depending on finish. It is also the only profile in this study that a competent owner-builder can install without specialist trade.
- **Box rib / R-panel** — flat fields separated by trapezoidal ribs. Crisper and more industrial; the 7.2 box rib is the strongest single-skin wall profile in the surveyed range and is the usual choice when the panel is also meant to span. R-panel runs 15–20% above corrugated, and roughly half of standing seam.
- **Deep sculpted profiles on aluminum** — Pure + FreeForm markets seven named corrugation profiles (Adder, Block, Canyon, Peak, Ravine, Sharkfin, Terrain) on 0.8 mm and 1 mm aluminum, with 17+ stocked finishes including blackened steel, bronze, weathered-rust, stone, and woodgrain, plus AAMA 2605 coating, ASTM E84 Class A, and a 20-year warranty. Micro-perforation with acoustic backing is available. This is the family that matches "patterned or textured, in-and-out waviness" most directly, and it is also the family that requires a quotation rather than a catalogue price.

Foam backing for insulation, which the owner raised as a possibility, is exactly what family 3 is. It is not an add-on to families 1, 2, or 5 — for those the insulation goes in the wall cavity behind, which is what the current estimate already provides ($7,486–$11,055 for studs, R-19 batt, vapour barrier, and 5/8" Type X).

### IMP specifics, since that is the current basis

Metl-Span CF Mesa, taken as representative: thicknesses 2, 2.5, 3, 4, 5, 6, 8 inch; widths 30, 36, 42, 44 inch; R-17.5 at 2 inch rising to R-70 at 8 inch; G-90 galvanised or AZ-50 Galvalume skins in 26, 24, or 22 gauge; offset double tongue-and-groove with no exposed fasteners; explicitly rated for exterior walls, **interior walls, and ceilings**; horizontal or vertical installation. Kingspan's range spans 1–8 inch at R-7.2/inch for PIR and R-8.0/inch for QuadCore.

At 2 inch and R-17.5, the IMP alone is close to the R-19 batt wall already in the estimate. If IMP is selected, the batt-and-drywall assembly behind it is partly redundant insulation — though see Section 9, because it may still be required for other reasons.

---

## 3. Installed cost comparison, 665 sq ft

Market ranges, materials plus labour, applied to the recorded 665 sq ft net panel area. Ranked cheapest first.

| Option | Material $/sf | Installed $/sf | 665 sq ft installed | Notes |
|---|---|---|---|---|
| Liner panel, 26 ga | 2.00–2.50 | ~3–5 | $2,000–3,300 | Utility finish; exposed fasteners |
| ⅞" corrugated, 24 ga | 1–3 | 3–6 | $2,000–4,000 | Owner-installable |
| R-panel / PBR | 2–5 | 4–7 | $2,700–4,700 | |
| 7.2 box rib | 1–3 | 4–7 | $2,700–4,700 | Strongest single-skin |
| Flush / T-groove / reveal | 3–5 | 7–11 | $4,700–7,300 | Concealed fastener |
| **IMP, 2 inch (current basis)** | **8–14** | **14–24** | **$10,510–18,460** | Per COST-ESTIMATE Item I |
| ACM cassette | — | 15–25 | $10,000–16,600 | Flat only |
| Designer aluminum, custom profile | quote | quote | quote | Premium tier |

**The spread is the headline.** Moving from IMP to ⅞" corrugated on a cavity-insulated wall saves roughly $7,000–15,000 on a project whose panel line item is currently 7% of total cost. Moving to a designer profile moves the other way by an unquantified amount. The decision is aesthetic and durability-driven, not thermal — the cavity wall behind can deliver the insulation either way.

---

## 4. The attachment question, and why it decides the material

The owner's open question — panels on the inside face running past the beams, versus panels set into each bay — is the governing decision. Research indicates it is not a free aesthetic choice, because the two arrangements suit different panel families.

### 4.1 Frame geometry the panels must meet

From [STR-006](../../06-structural-engineering/frame-geometry-study/beam-and-truss-positions.csv) and [support-positions.csv](../../06-structural-engineering/frame-geometry-study/support-positions.csv). Column symbols are 4 inch; wall height floor datum Z0 to frame bottom Z98.5 = 98.5 in (8 ft 2½ in); loft datum Z107.25.

| Row | Bay | c/c (in) | Clear between 4-in faces (in) | Clear (ft) |
|---|---|---:|---:|---:|
| West X=−34 | W1→W2 | 135.75 | 131.75 | 10.98 |
| West X=−34 | W2→W3 | 115.25 | 111.25 | 9.27 |
| West X=−34 | W3→W4 | 84.00 | 80.00 | 6.67 |
| North Y=269 | W4→N1 | 53.50 | 49.50 | 4.12 |
| North Y=269 | N1→N2 | 192.00 | 188.00 | 15.67 |
| South Y=−66 | W1→S1 | 182.50 | 178.50 | 14.88 |
| South Y=−66 | S1→S2 | 63.00 | 59.00 | 4.92 |
| East X≈247 | E-S→E-M | 187.00 | 183.00 | 15.25 |
| East X≈247 | E-M→E-N | 66.00 | 62.00 | 5.17 |
| Inner east X=211.5 | S3→N2 | 271.00 | 267.00 | 22.25 |

The N1→N2 bay at 192 in c/c is the north door bay and is already flagged as unresolved ([OI-FP-05](../../00-project-controls/open-items.md)); it gives 188 in between faces, not a 16-ft clear opening.

### 4.2 Module fit — the finding that matters

Standard IMP widths are 30, 36, 42, and 44 inch. Checked against every bay clear width above:

| Clear width | ÷30 | ÷36 | ÷42 | ÷44 |
|---:|---:|---:|---:|---:|
| 49.50 | 1.65 | 1.38 | 1.18 | 1.12 |
| 59.00 | 1.97 | 1.64 | 1.40 | 1.34 |
| 80.00 | 2.67 | 2.22 | 1.90 | 1.82 |
| 111.25 | 3.71 | 3.09 | 2.65 | 2.53 |
| 131.75 | 4.39 | 3.66 | 3.14 | 2.99 |
| 178.50 | 5.95 | 4.96 | 4.25 | 4.06 |
| 188.00 | 6.27 | 5.22 | 4.48 | 4.27 |
| 267.00 | 8.90 | 7.42 | 6.36 | 6.07 |

**Not one bay is a whole multiple of any standard width.** The near misses are 131.75 ÷ 44 = 2.99 and 59.00 ÷ 30 = 1.97.

This is decisive. A tongue-and-groove IMP or a concealed-clip single-skin panel derives its weather seal and its concealed fastening *from its factory side joint*. Cut one to an odd width to fit a bay and you cut that joint off, and every bay then needs a bespoke closure piece plus a field-formed edge. The economics and the weatherproofing both degrade.

### 4.3 The two arrangements

**Arrangement A — continuous across the inside face.** Panels run past the columns and beams on the inside, on horizontal sub-girts set off the frame. The panel module is set by the panel, not by the bay; sidelaps stay factory-formed; the run is uninterrupted. From the outside the full 4-inch depth of every member reads clear, which serves the decorative intent directly. The penalty: the panel plane is offset inboard by the sub-girt depth plus panel thickness, so the frame is fully expressed but the wall loses that depth of interior room, and the beam-to-panel junction needs a designed closure and flashing at every crossing.

**Arrangement B — set into each bay.** Each bay is its own framed opening, panel captured on all four edges by trim against the members. Reads as a coffered wall with the steel as a picture frame. This suits materials that are *cut to size and perimeter-captured rather than interlocked*: flat sheet or plate, ACM cassette, glass, polycarbonate, perforated sheet. It suits T&G IMP and concealed-clip single-skin panels poorly, for the reason above. It also multiplies the trim and sealant count by the number of bays, and every bay is a separate shop measurement.

**Arrangement C — hybrid.** Run a continuous inside-face panel, and align its reveals or its rib spacing to the column centres so the field reads as bays without being built as bays. The existing visualisation studies already assume something close to this: light grey 2-inch insulated infill panels with expressed vertical joints at 24 in. Note that 24 in does not divide 135.75, 115.25, or 84 either, so if joint-to-column alignment is wanted it needs to be drawn, not assumed.

Whichever is chosen, **both arrangements need secondary framing.** A girt is the horizontal member that gives the panel lateral support against wind; sub-girts set the spacing, alignment, and load transfer between panel and primary frame. None of this secondary steel is in STR-006, which excludes secondary joists, rafters, diaphragms, bracing design, fasteners, and foundations, and it is not separately priced in the current estimate.

### 4.4 Recommendation for review

Arrangement A or C for the opaque field, Arrangement B for the glazed and feature bays. This lets the cheap, well-sealed, factory-jointed product run continuously where it does the weatherproofing work, and reserves bay-by-bay infill for the places where the picture-frame effect is the point and where the material is cut-to-size anyway.

---

## 5. Can the panels provide rigidity?

Short answer: **some panel types can, the currently assumed type cannot, and recruiting them is probably not worth what it costs the design.**

### 5.1 IMP is disqualified

Insulated metal panels are not designed for use as bearing walls or shear diaphragm walls; they are cladding systems, not structural support systems. Unlike structural insulated panels, IMPs do not provide shear resistance to the wall assembly, though they do resist transverse loads such as wind. They are normally installed on steel frames that are already braced and provide all necessary lateral support. Where IMPs do have structural strength, capacity is typically governed by the fastener system under negative wind load.

So if the 2-inch IMP in the current cost basis is retained, the rigidity question is closed: the frame carries everything lateral, as STR-006 already assumes.

### 5.2 Profiled single-skin sheet can be designed as a diaphragm

There is a real, codified path. ANSI/AISI S310 is the North American Standard for the Design of Profiled Steel Diaphragm Panels; it covers diaphragms **and wall diaphragms** built from fluted panels, deck, and cellular deck, gives shear strength and shear stiffness provisions, and permits supports of steel, wood, or concrete with or without insulation between panel and support. SDI's Diaphragm Design Manual, 4th edition (DDM04), is the companion design manual covering strength, stiffness, fasteners, connections, and warping.

Published test data for sheet-steel-sheathed shear walls indicates allowable shear from roughly **500 plf to 2,300 plf ASD**, varying with sheet thickness and screw size, and that capacity rises sharply as edge fastener spacing tightens — one test series held field screws at 12 in while reducing edge spacing from 6 in to 2 in, with large strength gains. Corrugated sheathing with slit patterns can be tuned for ductility alongside high strength and initial stiffness. The governing failure mode is screws popping out as the sheet warps, and screws gouging elongated holes in the framing under cyclic racking. AISI S310 and DDM04 cap the fastener contribution at 25% of total diaphragm strength.

Note that most of this literature is cold-formed steel framing (AISI S400 governs seismic design of CFS shear walls and added steel-sheet sheathing provisions). This frame is HSS. The panel-to-frame connection would therefore be a bespoke engineered detail, not a tabulated assembly, and the load path from panel through sub-girt to HSS to base plate to pier would all need design.

### 5.3 Why it is probably not worth it here

Four arguments against, for the owner's consideration:

1. **It contradicts the glass.** Section 7 contemplates substantial glazing. A shear panel cannot have a hole in it. Every bay promoted to structural is a bay that can never become a window, and the choice would have to be frozen before the engineer's lateral design, ahead of the architectural design freeze.
2. **It contradicts the cheap options.** The panels that can be designed as diaphragms are the exposed-fastener profiled sheets — and they need close edge fastener spacing in a visible field. A 2-inch edge screw pitch on an interior feature wall is a strong aesthetic commitment.
3. **The frame is already there.** Five truss families plus 13 columns are modelled. Bracing is unresolved, but adding lateral capacity by tuning member sizes and a defined bracing scheme is ordinary engineering; adding it by cladding diaphragm introduces an unusual assembly for a plan-check in a high-seismic jurisdiction.
4. **It transfers risk to the finish.** A structural cladding panel cannot be replaced, reconfigured, or drilled through later without re-analysis. On a building whose interior use is storage and equipment handling with a 1,000 lb trolley, that is a real operational constraint.

The conservative position — and the one consistent with STR-006's stated limits — is to keep the panels non-structural, design them for component-and-cladding wind pressure only, and let the frame and an explicit bracing scheme do the lateral work. If the engineer later finds a diaphragm contribution useful, the codified path exists and is documented above.

---

## 6. Non-metal and mixed options worth keeping on the table

| Material | Installed $/sf | Why consider it |
|---|---|---|
| **Plywood, 5/8" exterior grade** | 1.40–3.70 | Cheapest real wall. Screws hold anywhere, takes shelving and equipment mounting directly, paintable or clear-finished. Combustible; conflicts with the fire-separation intent behind the Type X drywall. |
| **FRP panel** | 3.50–7.50 | Washable, bright, moisture-proof. Reads as commercial kitchen, not architectural. |
| **Perforated metal, including perforated weathering steel** | quote | Perforated Corten is produced for interior and exterior use via CNC punching for repeating patterns or laser cutting for custom geometry. Pairs with acoustic backing. Good candidate for a feature bay, or for the guard/screen at the balcony where the existing design already uses horizontal walkway slats. |
| **Weathering steel / Corten look** | ~$3–6 material | Real Corten needs pre-rusting and sealing, carries a price premium over plain steel, and often has minimum tonnage runs. Pre-weathered painted products (e.g. Corten AZP Raw) arrive looking aged and are marketed for interior use — the practical route to the look. |
| **Multiwall polycarbonate** | quote | Tongue-and-groove translucent panels from EXTECH (LIGHTWALL 3440, 40 mm), Danpal, and Rodeca (to 60 mm), at roughly 45–70% light transmittance. Insulating, light, impact-tolerant, far cheaper than glass per square foot, and it glows. A strong candidate for the bays where daylight matters more than a view. |

---

## 7. Glazed bays

### 7.1 Systems, from cheapest to most expensive

| System | Installed $/sf | Character | Fit to a 4-in steel frame |
|---|---|---|---|
| Fixed aluminum picture window in a framed opening | see estimate | Simple, residential | Easy; needs a framed rough opening in the bay |
| Multiwall polycarbonate | quote, well below glass | Translucent, no view | Very good; light, big panels, forgiving tolerance |
| Aluminum storefront, non-thermal, tempered IGU | 50–150 | Commercial, crisp sightlines | Good; standard bay infill product |
| Aluminum storefront, thermally broken, Low-E IGU | 75–140, or 90–140 for standard thermally-broken with tempered Low-E IGU | Same look, better performance | Good |
| Channel glass (Pilkington Profilit via TGP) | roughly curtain-wall pricing; material ≈ half of installed | U-shaped self-supporting cast glass channels in an extruded aluminum perimeter frame; textured, translucent, vertical rhythm | Excellent conceptually — it is *made* for spanning a tall bay with only a perimeter frame, and its vertical channel rhythm would sit beautifully against an exposed painted frame |
| Curtain wall / large custom IGU | to 300 | Maximal glass | Overkill at this scale |

Storefront material alone is around $25–75/sf; a lower-end IGU is roughly $25–55/sf and a premium krypton-filled unit $60–80/sf.

### 7.2 Which bays

For review, not decided:

- **South row** — S1→S2, 59.0 in clear, 4.92 ft, and W1→S1, 178.5 in clear, 14.88 ft. South glass is the daylight prize and also the solar-gain and glare risk. The 14.88 ft bay is a large piece of glass; splitting it at the panel module or intermediate mullion is likely.
- **West row** — W3→W4, 80.0 in clear, 6.67 ft, is the natural single-bay glazed opening: a well-proportioned, modest 6 ft 8 in × 8 ft 2½ in bay.
- **North row** — N1→N2, 188 in clear, is the door bay; the estimate already carries a glass insulated loading door at 8 ft × 7 ft ($1,200–2,500). W4→N1 at 49.5 in clear is a good sidelight.
- **East row** — E-M→E-N, 62.0 in clear. E-M retains option B status in STR-006, so this bay's geometry is not settled.
- **Balcony / loft level** — the estimate already carries a sliding glass door ($1,200–2,500) and two tempered glass guardrail panels at 36×60 ($2,400–4,200).

The existing cost basis nets 665 sq ft of panel against 778 sq ft of wall cavity, so 113 sq ft is already assumed as openings. Promoting further bays to glass reduces panel area and increases glazing area roughly one for one, at a large unit-cost step up: panel at $3–24/sf installed versus glazing at $50–150/sf installed. A single 6.67 ft × 8.21 ft bay glazed in thermally-broken storefront is on the order of $4,100–7,700 in place of roughly $160–1,300 of panel.

---

## 8. Marine corrosion — a finding that constrains substrate choice

The site is 1370 Wilbur Avenue, San Diego 92109 (Pacific Beach), within short distance of both the Pacific surf line and Mission Bay, both saltwater.

Published Galvalume warranties **exclude structures within 1,500 ft of salt water, marine atmospheres, or salt spray**, with at least one manufacturer drawing the line at two miles. Within that zone a standard Galvalume or steel panel may carry no meaningful finish or substrate warranty at all; in some cases coverage drops from 25 years to 5 years within a mile of saltwater. The recommended substrate inside the exclusion zone is **painted aluminum with a coastal-rated paint warranty**, because aluminum forms a passive oxide layer that resists salt-air corrosion.

This matters immediately, because:

- The representative IMP in Section 2 offers G-90 galvanised or **AZ-50 Galvalume** skins. Both are steel. Aluminum-skin IMP is a narrower market with a price premium.
- The designer-profile family (Section 2, family 5) is 100% aluminum by construction, which makes it the substrate-correct choice as well as the aesthetic one.
- ⅞" corrugated and the other single-skin profiles are available in aluminum as well as steel, so the cheap route survives the constraint — but the aluminum version, not the stocked Galvalume version.

**Action:** the exact distance to mean high tide for both the ocean and Mission Bay must be established from the survey, and each candidate manufacturer's written coastal exclusion checked against it, before any substrate is specified. This extends [OI-011](../../00-project-controls/open-items.md).

Because the panels are inside a weathertight envelope rather than fully exposed, a case may exist for a less corrosion-resistant substrate. That case has to be argued against the actual assembly — a vented cavity behind a panel in a coastal marine atmosphere is not a benign interior — and it is not argued here.

---

## 8A. The same finding applied to the roof

Added at owner request 2026-09-17. The roof is the more exposed surface, and the finding lands harder there than on the walls.

### 8A.1 What is currently assumed

[COST-ESTIMATE.md](../../../COST-ESTIMATE.md) item G carries 713 sq ft of 22-ga corrugated metal roof deck, self-adhered underlayment, and standing seam metal roof panels at $6.00-9.00/sq ft, plus 131 sq ft of standing seam hip cap at $8-12/sq ft and 60 lin ft of gutter. No substrate is named. The unstated default for standing seam at that price point is painted Galvalume, which is the product the 1,500-ft exclusion applies to.

### 8A.2 Why the roof is the harder case

Three reasons the wall conclusion does not simply carry over.

**The roof is not sheltered.** Trade guidance is explicit that Galvalume "will not stand up to" coastal conditions, that saltwater degrades the coating and causes premature damage, and that aluminum is the recommended substrate. Whatever argument exists for a steel panel inside a weathertight wall cavity does not exist for the outermost surface of the building.

**Most of the roof will never be rain-washed.** This is the finding that matters most. Exposed roof areas can corrode *more slowly* than sheltered ones, because rain periodically rinses salt away; sheltered and covered areas get no such rinse, accumulate salt, and corrode faster. Panel overlaps, flashings, undersides, gutters, and specifically the area *beneath solar equipment* retain deposits. Light rain can make it worse, dissolving salt and then leaving fresh deposits as it evaporates.

On this building that zone is not a detail. Using SOL-001's array footprint of 273.5 x 143.2 in (272 sq ft) against its 325 sq ft south face, **the modules shelter roughly 84% of the south slope** and about 38% of the whole 713 sq ft roof. The south slope is also the slope that faces the prevailing marine air. A substrate chosen on the assumption that rain keeps it clean is being chosen for conditions that will not exist across most of this roof.

Note that the roof area bases do not currently reconcile: item G's 713 sq ft derives from the older 30-degree geometry (282 x 214 in south, slope run 17.83 ft, plus 282 x 150 in north, run 12.50 ft), while ASM-SOL-01 records a 325 sq ft south face at 35 degrees with a 13.86 ft run. The percentages above should be recomputed once the roof geometry is frozen.

**Access for washing is poor and gets worse.** The remedy trade sources give for salt accumulation is periodic rinsing. Under a fixed PV array on a 30-35 degree slope, two storeys up, that is not a realistic owner maintenance task, and the solar report already notes that required fire access, roof edges, clamps and waterproofing may invalidate the current module layout.

### 8A.3 What changes

| Item | Current basis | Coastal position |
|---|---|---|
| Standing seam substrate | unstated; Galvalume implied by price | Painted aluminum, 0.032-0.040 in, with a coastal-rated paint warranty |
| Paint warranty | not stated | Aluminum PVDF is typically 40 yr standard, **25 yr coastal**; Galvalume substrate perforation warranty is excluded within 1,500 ft |
| Weathertight warranty | not stated | Available on aluminum including coastal; Galvalume weathertight warranties are non-coastal |
| Clips and fasteners | in the $6-9/sf line | 316 stainless, not 304 or 18-8; 316 resists the chloride attack and tea-staining that fail 304 in coastal service, at a 20-30% fastener premium |
| Gutters, 60 lin ft | unstated at $8-12/lin ft | Aluminum or stainless, not galvanized |
| PV attachment | not detailed | Non-penetrating seam clamps with round-point setscrews; Class III 20+ micron anodising for coastal |
| Module-to-roof isolation | not addressed | Non-conductive isolation pads (EPDM, neoprene) at every dissimilar-metal contact |
| Corrugated 22-ga deck | steel, unstated coating | Protected by the underlayment, but condensation on its underside and its galvanic relationship to an aluminum panel above need the envelope consultant's review |

### 8A.4 Galvanic pairing, which the substrate switch partly solves

Galvalume performs best when not in contact with concrete, treated lumber, copper, lead, bricks, or iron. The PV array introduces aluminum module frames and aluminum rails onto whatever the roof is made of, in the presence of a salt electrolyte, which is the classic accelerated-corrosion setup. In marine ISO C4/C5 exposure, galvanized steel racking components can have a service life of only 5-20 years against a 25-year PV system design life.

An aluminum roof panel under aluminum rails and aluminum module frames is the compatible pairing, which is a second, independent argument for the substrate switch. It does not eliminate the need for isolation pads at stainless-to-aluminum contacts, because aluminum is the less noble metal there and will sacrifice itself to protect the stainless.

### 8A.5 Cost

Material only, per published ranges: painted Galvalume $1.75-2.35/sq ft against aluminum $2.20-3.00/sq ft. Over 713 sq ft that is a **$321-463** difference in raw material.

Installed is where the estimate moves. Two methods, both shown because they disagree:

| Method | Main roof, 713 sq ft | Hip cap, 131 sq ft |
|---|---|---|
| Current estimate, item G | $4,278-6,417 | $1,048-1,572 |
| Aluminum at a 20-30% premium | $5,134-8,342 | $1,258-2,044 |
| Aluminum at published $9-18/sq ft installed | $6,417-12,834 | not separately published |

On the premium method the roof subtotal moves from $9,601-14,944 to roughly **$10,666-17,341**, a delta of about **$1,065-2,397**, before the 316 stainless fastener premium and the isolation pads. The absolute $9-18/sq ft range would push it further; the spread between the two methods is itself a reason to get a real quotation rather than settle this from published ranges.

Set against a PV and battery package at $30,475-39,095 gross and a 25-year design life, a one-to-two-thousand-dollar substrate decision on the surface the array is bolted to is not where this project should economise.

### 8A.6 Two things the switch costs

**Thermal movement.** Aluminum expands and contracts roughly twice as much as steel, and panels over 15-20 ft need expansion clips to avoid oil canning and noise. The south slope run at the 30-degree basis is 17.83 ft, squarely inside that band; the 35-degree basis gives 13.86 ft, outside it. So whether the south slope needs floating clips depends on which roof geometry is frozen, and the north slope at 12.50 ft does not. This must be settled with the roof geometry, not after.

**Denting.** Aluminum is more malleable and more susceptible to surface denting during handling and installation. On a roof that will be walked for PV installation, module cleaning and future replacement, that argues for the heavier 0.040 in sheet and for defined walk paths, not the thinnest warrantable gauge.

### 8A.7 Position for review

Specify painted aluminum standing seam with a coastal-rated paint warranty, 316 stainless clips and fasteners, aluminum or stainless gutters, non-penetrating seam clamps for the array, and isolation pads at every dissimilar-metal contact. Obtain the written coastal warranty terms before ordering, because the 1,500-ft line is a manufacturer-by-manufacturer term and one surveyed manufacturer draws it at two miles.

The roof warrants this more strongly than the walls do, and unlike the walls it cannot be revisited later: the panels will be under a fixed PV array, and replacing them means removing and reinstalling the array.

---

## 9. Fire and code items the panel choice triggers

Not determinations. Items for the architect and plan-check.

1. **Foam plastic core and thermal barrier.** IBC/CBC Chapter 26 requires foam plastic to be separated from the building interior by an approved thermal barrier: ½-inch gypsum wallboard, heavy timber, or a material meeting the acceptance criteria of both the Temperature Transmission and Integrity fire tests of NFPA 275. An exception exists by special approval after large-scale testing — NFPA 286, FM 4880, UL 1040, or UL 1715 — and this exception is commonly relied on for composite foam insulated metal panels. **If IMP is selected, the specific panel's large-scale test approval must be obtained, or the thermal barrier retained.** Note also that where a thermal barrier was present in an assembly's fire test, it cannot be omitted in the real installation and must run the full wall height.
2. **NFPA 285.** This test governs flammability of exterior non-load-bearing wall assemblies containing foam plastic insulation. Applicability depends on construction type and height and should be confirmed rather than assumed for an accessory structure — but if it applies, the tested assembly, not just the panel, is what complies.
3. **The Type X drywall already in the estimate.** 778 sq ft of 5/8" Type X is carried for fire code. It plausibly doubles as the Chapter 26 thermal barrier. If the drywall is deleted as redundant insulation once an IMP is chosen, the thermal-barrier and fire-separation functions must be re-established by another means. **Do not delete that line item on thermal grounds alone.**
4. **Coastal Overlay Zone.** [Document requirements](../../00-project-controls/document-requirements.md) already list a Coastal Overlay Zone and coastal-development-permit determination, and [OI-002](../../00-project-controls/open-items.md) is open. An overlay may carry appearance or materials expectations that bear on a visible exterior frame and panel colour.

---

## 10. Open items this study raises

| Ref | Item | Why it matters |
|---|---|---|
| ENV-OI-01 | Establish distance to mean high tide, ocean and Mission Bay; obtain written coastal warranty exclusions for each candidate manufacturer. | Governs substrate. Galvalume may be unwarrantable on this site. |
| ENV-OI-02 | Decide arrangement A, B, or C before selecting a panel family. | No bay clear width is a multiple of any standard panel width; T&G products do not suit bay infill. |
| ENV-OI-03 | Owner decision: are panels non-structural, or is a diaphragm contribution to be pursued? | Freezing panels as structural forecloses glazing in those bays and must precede lateral design. |
| ENV-OI-04 | Design and price secondary framing — girts and sub-girts — for whichever arrangement is chosen. | Absent from STR-006 and not separately priced in COST-ESTIMATE. |
| ENV-OI-05 | Select glazed bays and system, and reconcile with the 665 / 778 sq ft panel-to-cavity area basis. | Glazing at $50–150/sf installed versus panel at $3–24/sf; area moves one for one. |
| ENV-OI-06 | If IMP: obtain the specific product's NFPA 286 / FM 4880 / UL 1040 / UL 1715 approval, or retain the thermal barrier. | Chapter 26 compliance. |
| ENV-OI-07 | Confirm whether the R-19 batt and Type X assembly is retained behind an IMP. | Thermal redundancy versus fire-separation and thermal-barrier necessity. |
| ENV-OI-09 | Specify the roof panel substrate. Confirm whether item G's standing seam is Galvalume by default, and price painted aluminum with a coastal-rated paint warranty as the alternative. | The 1,500-ft exclusion applies to the roof more strongly than the walls, and the roof is the outermost surface. Delta about $1,065-2,397 on the premium method. | Owner / architect / roofing contractor | Roof material procurement | draft |
| ENV-OI-10 | Specify roof clips, fasteners, gutters and PV attachment hardware for marine exposure: 316 stainless rather than 304, aluminum or stainless gutters, non-penetrating seam clamps with round-point setscrews, Class III anodising, and isolation pads at dissimilar-metal contacts. | 304 stainless suffers chloride attack and tea-staining in coastal service. Aluminum module frames on a steel roof in a salt electrolyte is the classic accelerated-corrosion pairing. None of this is separately priced in item G. | Architect / roofing contractor / solar designer | Construction documents | draft |
| ENV-OI-11 | Address salt accumulation beneath the PV array, where roughly 84% of the south face is sheltered from rain washing, and establish whether any rinsing or inspection access is realistic under a fixed array. | Sheltered roof areas corrode faster than exposed ones because rain never rinses them. The trade remedy is periodic washing, which a fixed array on a 30-35 degree slope largely prevents. | Architect / envelope consultant / solar designer | Roof and array layout freeze | draft |
| ENV-OI-12 | Reconcile the roof area bases before recomputing any per-square-foot roof figure: item G's 713 sq ft at 30 degrees (282x214 in south, 282x150 in north) against ASM-SOL-01's 325 sq ft south face at 35 degrees. | The two bases disagree, and the south slope run differs between them (17.83 ft versus 13.86 ft), which decides whether aluminum expansion clips are required. | Architect / solar designer | Roof geometry freeze | draft |
| ENV-OI-08 | Reconcile the 24-in expressed joint spacing in the visualisation studies with actual column centres of 135.75, 115.25, and 84 in. | 24 in divides none of them. |

---

## 11. Sources

All accessed 2026-09-17. Manufacturer and trade pricing is published market range, not quotation.

**Panel types, profiles, and pricing**
- [PAC-CLAD metal wall panels](https://www.pac-clad.com/products/metal-wall-panels/)
- [McElroy Metal wall panels](https://www.mcelroymetal.com/metal-wall-panel) · [McElroy sub-girt](https://www.mcelroymetal.com/substructural-components/sub-girt)
- [Western States Metal Roofing — metal wall panels](https://www.westernstatesmetalroofing.com/metal-wall-panels) · [which panel is right for you](https://www.westernstatesmetalroofing.com/blog/types-of-metal-wall-panels-which-is-right-for-you) · [what is R-panel](https://www.westernstatesmetalroofing.com/blog/what-is-r-panel) · [7.2 box rib](https://www.westernstatesmetalroofing.com/blog/7-2-box-rib-panel) · [metal siding cost](https://www.westernstatesmetalroofing.com/blog/metal-siding-cost)
- [MBCI corrugated](https://www.mbci.com/products/corrugated/) · [MBCI interior liner panels](https://www.mbci.com/products/wall/interior-wall-panels/)
- [Metal America — metal wall panels](https://metalamerica.com/metal-wall-panels/) · [⅞" corrugated](https://metalamerica.com/7-8-corrugated-metal-panels/) · [gauges explained](https://metalamerica.com/metal-roofing-panel-gauges/)
- [AEP Span metal siding](https://www.aepspan.com/metal-siding/) · [ARCAT metal wall panel manufacturers](https://www.arcat.com/content-type/product/thermal-and-moisture-protection-07/metal-wall-panels-074213)
- [HomeGuide corrugated metal cost 2026](https://homeguide.com/costs/corrugated-metal-roof-cost) · [The Roofing Brief — R-panel](https://theroofingbrief.com/r-panel-roofing/)
- [Nucor Steel Store liner panel](https://www.nucorsteelstore.com/Subcategory.aspx?CategoryID=5977) · [Rhino liner panels](https://www.rhinobldg.com/liner-panels-partitions/)

**Insulated metal panels**
- [Metl-Span CF Mesa](https://metlspan.com/products/wall/insulated-metal-panels/mesa/) · [CF Light Mesa](https://www.metlspan.com/products/wall/insulated-metal-panels/light-mesa/) · [SIPs and IMPs](https://metlspan.com/sips-and-imps/) · [CF wall guide specs](https://metlspan.com/wp-content/uploads/2023/01/Metl-Span-Commerical-and-Industrial-CF-Wall-Panels-with-PIR-Guide-Specs.pdf)
- [Kingspan insulated panel systems](https://kipna.kingspan.com/en-us/products/insulated-panel-systems/) · [Benchmark architectural IMP](https://www.kingspan.com/us/en/products/architectural-panel-facade-systems/) · [R-value of IMPs](https://www.kingspan.com/us/en/knowledge-articles/what-is-the-r-value-of-insulated-metal-panels/)
- [ATAS IMP selection guideline (PDF)](https://atas.com/wp-content/uploads/2019/07/IMP-Selection-Guide.pdf)
- [Kovach — comparing metal panel attributes](https://www.kovach.net/comparing-metal-panel-attributes/)

**Designer, perforated, and weathering steel**
- [Pure + FreeForm corrugated metal walls](https://purefreeform.com/corrugated-metal-walls/)
- [Accurate Perforating — perforated Corten](https://www.accurateperforating.com/capabilities/perforated-metal-materials/perforated-corten-steel) · [TBK perforated Corten facade panels](https://www.tbkmetal.com/perforated-corten-steel-facade-panels/)
- [Corten Roofing — siding panels](https://www.cortenroofing.com/corten-steel-siding) · [Western States corrugated Corten AZP Raw](https://www.westernstatesmetalroofing.com/corrugated-corten-azp-raw-metal-roofing-siding-panels)
- [CENTRIA concealed fastener rainscreen](https://centria.com/product-series/rainscreen-systems/concealed-fastener-panels/) · [ALUCOBOND ACM systems](https://www.alucobondusa.com/systems.html)

**Glass and translucent**
- [TGP channel glass systems](https://www.tgpamerica.com/products/channel-glass-systems/) · [Pilkington Profilit at TGP](https://www.tgpamerica.com/products/glass/pilkington-profilit-channel-glass/) · [channel glass cost listing](https://www.tgpamerica.com/resources/channel-glass-basics/channel-glass-product-listing/) · [channel glass FAQ](https://www.tgpamerica.com/resources/reference-tools/channel-glass-faq/) · [Pilkington Profilit](https://www.pilkington.com/en/us/products/product-categories/glass-systems/pilkington-profilit)
- [EXTECH translucent walls](https://extechinc.com/translucent-walls/) · [LIGHTWALL 3440](https://extechinc.com/lightwall-3440-polycarbonate-wall-panels/) · [Danpal translucent wall systems](https://danpal.com/translucent-wall-system/) · [Rodeca 60 mm panels](https://www.buildingdesignindex.co.uk/entry/126436/RODECA/60mm-translucent-polycarbonate-panels-PC-256012/) · [Building Enclosure on polycarbonate systems](https://www.buildingenclosureonline.com/articles/90601-benefits-of-translucent-polycarbonate-window-and-wall-systems)
- [Insight Glass — commercial storefront cost 2026](https://www.insightglass.com/commercial-storefront-windows-cost-bay-area-2026/) · [ProGlass storefront installation cost 2026](https://proglassgv.com/storefront-glass-installation-cost/) · [Hotian storefront cost guide](https://hotianwindows.com/storefront-windows-cost/) · [Swivl storefront and glazing cost guide](https://swivl.tech/cost-guide-customer/commercial-storefront-glazing)

**Structural role of panels**
- [ANSI/AISI S310-23 (PDF)](https://www.buildusingsteel.org/wp-content/uploads/2023/12/AISI-S310-23-S310-C-23_s.pdf) · [SDI listing for S310-23](https://sdi.org/publications/publications/sdi-standards/aisi-standards/ansi-aisi-s310-23/) · [BuildSteel on the S310 update](https://buildsteel.org/technical/codes-and-standards/aisi-updates-standard-for-the-design-of-profiled-steel-diaphragm-panels/)
- [SDI Diaphragm Design Manual DDM4](https://sdi.org/publications/publications/design-manual/diaphragm-design-manual-fourth-edition-no-ddm4/) · [STRUCTURE magazine on the new SDI manual](https://www.structuremag.org/article/new-sdi-diaphragm-design-manual/) · [SJI diaphragm design with steel deck](https://steeljoist.org/resources/diaphragm-design-with-steel-deck/)
- [AISI S400-20 (PDF)](https://www.steelframing.org/assets/Library/Standards/AISI-S400-20.pdf) · [STRUCTURE magazine on AISI S400-15/S1-16](https://www.structuremag.org/article/aisi-s400-15-s1-16/) · [AISI steel sheet sheathing research report RP09-2 (PDF)](https://buildusingsteel.org/wp-content/uploads/2020/12/CFSD-Report-RP09-2.pdf)
- [Structural testing of corrugated sheet steel shear walls (Missouri S&T)](https://scholarsmine.mst.edu/cgi/viewcontent.cgi?article=1328&context=isccss) · [Cold-formed steel shear wall design course (PDF)](https://pdhonline.com/courses/s102/shear.pdf) · [Slit configuration in corrugated CFS sheathing](https://www.sciencedirect.com/science/article/abs/pii/S0143974X17308519)
- [Ceco — metal building secondary framing](https://www.cecobuildings.com/blog/secondary-framing/) · [Steel support framing for facades (PDF)](https://pdhonline.com/courses/s217/s217content.pdf) · [Allied Steel building details](https://www.alliedbuildings.com/building-details/)

**Fire and code**
- [MCA white paper — IMPs and NFPA 285 (PDF)](https://designandbuildwithmetal.com/docs/default-source/TechnicalArticles/mca13-imp-and-nfpa-285.pdf?sfvrsn=2) · [same, MCA hosted](https://metalconstruction.org/view/download.php/online-education/education-materials/imp-educational-materials/insulated-metal-panels-and-nfpa-285)
- [IBC 2603 foam plastic insulation, code commentary (PDF)](https://upcfoam.com/wp-content/uploads/2024/02/IBC-2603-Code-Commentary-Pertaining-to-Thermal-Protection.pdf) · [UpCodes — thermal barrier](https://up.codes/s/thermal-barrier) · [UpCodes — exterior walls of buildings of any height](https://up.codes/s/exterior-walls-of-buildings-of-any-height)

**Coastal corrosion**
- [Western States — coastal paint warranties](https://www.westernstatesmetalroofing.com/blog/metal-roofing-coastal-areas-paint-warranties)
- [McElroy — is Galvalume as effective as aluminum in coastal applications](https://blog.mcelroymetal.com/metal-roofing-contractors/is-galvalume-as-effective-as-aluminum-in-coastal-applications)
- [Metal Sales AZ55 Galvalume warranty (PDF)](https://www.metalsales.us.com/wp-content/uploads/2024/01/231208-Galvalume-Warranty.pdf) · [Sheffield Metals — warranty types](https://sheffieldmetals.com/learning-center/metal-roof-warranty-types/) · [Gulf Coast metal roof warranty guide](https://gulfcoastmetalroofguide.com/coastal-performance/warranties/)

**Roof: coastal substrate, PV attachment, and galvanic corrosion** (added 2026-09-17)
- [Sheffield Metals — Galvalume steel vs aluminum](https://sheffieldmetals.com/learning-center/galvalume-steel-vs-aluminum/) · [metal roof material types](https://sheffieldmetals.com/learning-center/metal-roof-material-types/)
- [Metal Alliance — Galvalume vs aluminum for coastal projects](https://www.metalalliance.com/post/galvalume-vs-aluminum-roofing) · [The Roofing Brief — aluminum roofing cost and vs steel 2026](https://theroofingbrief.com/aluminum-roofing/) · [WeatherShield — standing seam cost 2026](https://weathershieldroofers.com/blog/standing-seam-metal-roof-cost/) · [WeatherShield — standing seam guide, coastal](https://weathershieldroofers.com/blog/standing-seam-metal-roof-complete-guide-coastal-sc/)
- [Marine Construction Magazine — causes of corrosion in coastal areas](https://marineconstructionmagazine.com/article/causes-of-corrosion-in-coastal-areas/) · [Preventing corrosion in coastal metal roofing systems](https://smalltownroofing.org/preventing-corrosion-in-coastal-metal-roofing-systems/) · [Worthouse — coastal metal roofing care](https://worthouse.com/metal-roofing-maintenance-for-coastal-regions/) · [Allstate — metal roof corrosion in coastal Florida](https://acroof.net/blog/metal-roof-corrosion-in-coastal-florida/)
- [S-5! — mounting to standing seam without voiding the warranty](https://blog.s-5.com/blog/mount-to-standing-seam-metal-roof-without-voiding-warranty) · [S-5! roof clamps](https://www.s-5.com/products/roof-clamps/) · [Metal Roofing Magazine — warranty-safe metal roof attachments](https://readmetalroofing.com/warranty-safe-metal-roof-attachments-designing-for-long-term-performance/) · [standing seam solar clamps guide](https://solartechonline.com/blog/standing-seam-solar-clamps-guide/)
- [Greentech Renewables — galvanic corrosion and protection in PV installations](https://www.greentechrenewables.com/article/galvanic-corrosion-and-protection-solar-pv-installations) · [preventing galvanic corrosion in PV mounting](https://www.anernstore.com/blogs/diy-solar-guides/prevent-galvanic-corrosion-pv-mounting) · [coastal PV racking isolation pads](https://www.anernstore.com/blogs/diy-solar-guides/coastal-pv-racking-isolation-pads) · [PVRack — corrosion standards for solar mounting steel](https://pvrack.com/regulations-standards/corrosion-standards/)
- [Suncor — 304 vs 316 stainless for marine hardware](https://suncorstainless.com/blog/304-vs-316-stainless-steel-which-is-better-for-marine-hardware/) · [Fair Wind — 304 vs 316](https://fairwindfasteners.com/blogs/news/the-difference-between-304-and-316-stainless-steel) · [Cyclone Bolt — 18-8 vs 304 vs 316 marine use guide](https://www.cyclonebolt.com/stainless-steel-marine-use-guide/) · [Wikipedia — marine grade stainless](https://en.wikipedia.org/wiki/Marine_grade_stainless)

**Non-metal alternatives**
- [FRP wall panel cost ranges 2026](https://designtransitionstudio.com/frp-wall-panels-cost-price-ranges-u-s-buyers/) · [GTOFRP installation cost guide](https://www.gtofrp.com/FRP-Panel-Installation-Cost-Guide-Materials-Labor-And-Pricing-Per-Square-Foot-id45379216.html)
- [Homewyse — cost to install wall paneling](https://www.homewyse.com/services/cost_to_install_wall_paneling.html) · [Cutlistor — plywood cost 2026](https://www.cutlistor.com/blog/how-much-does-plywood-cost)

**Project internal references**
- [STR-006 frame geometry study](../../06-structural-engineering/frame-geometry-study/README.md), rev 0, `draft`
- [ARCH-006 floor plan study](../../05-architectural-design/floor-plan-study/README.md), rev 4, `draft`
- [SOL-001 solar and roof report](../../08-solar-electrical-and-energy/README.md), rev 1, `draft`
- [COST-ESTIMATE.md](../../../COST-ESTIMATE.md) — working cost basis, not a report-controlled artifact
- [DEC-004](../../00-project-controls/decision-log.md), [ASM-007](../../00-project-controls/assumptions-register.md), [OI-002](../../00-project-controls/open-items.md), [OI-011](../../00-project-controls/open-items.md), [OI-FP-05](../../00-project-controls/open-items.md)

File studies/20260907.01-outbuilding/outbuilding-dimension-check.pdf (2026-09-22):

### 01 PLAN · north up

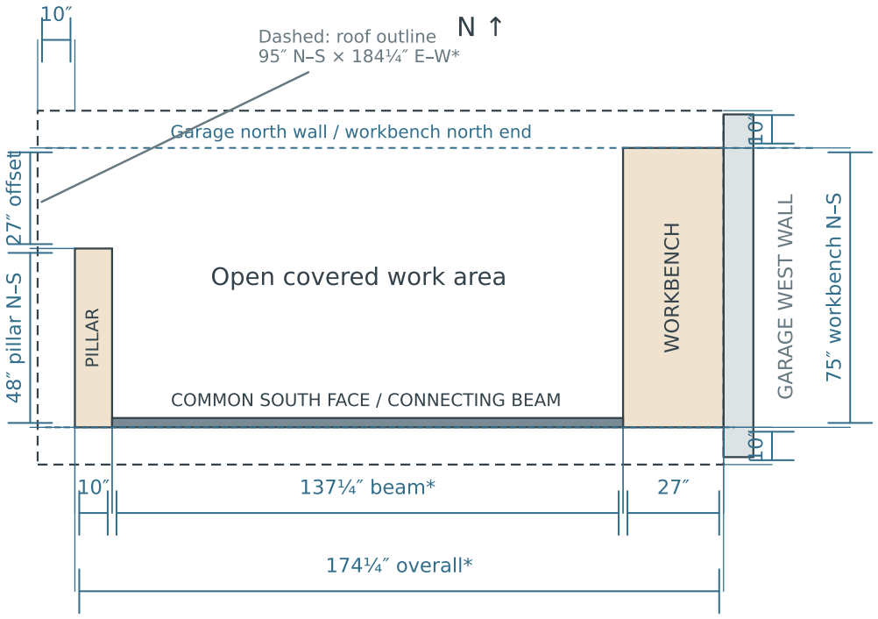
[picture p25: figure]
GARAGE WEST WALL; WORKBENCH; PILLAR; Garage north wall / workbench north end; COMMON SOUTH FACE / CONNECTING BEAM; Open covered work area; 137¼ beam*; 174¼ overall*; 75 workbench N; 48 pillar N; S 27 offset; Dashed: roof outline

GARAGE

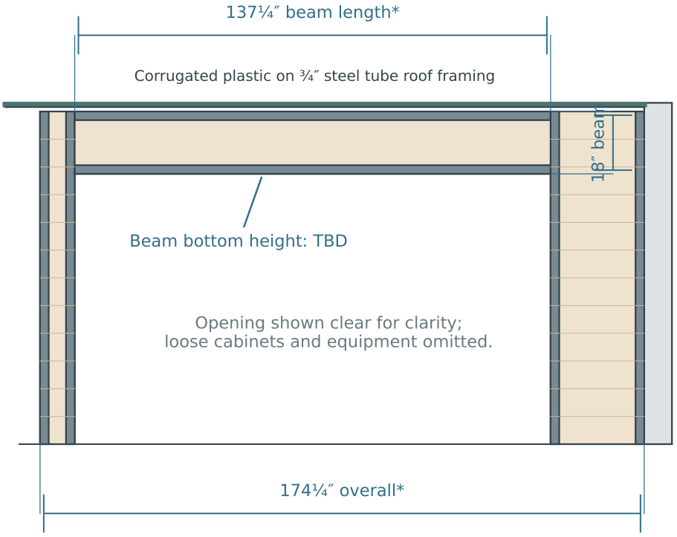
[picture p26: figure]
137¼ beam length*; 18 beam; 174¼ overall*; Beam bottom height: TBD; Opening shown clear for clarity; loose cabinets and equipment omitted.

Corrugated plastic on ¾ steel tube roof framing

### 02 SOUTH / FRONT ELEVATION · looking north

### 03 WEST ELEVATION · looking east

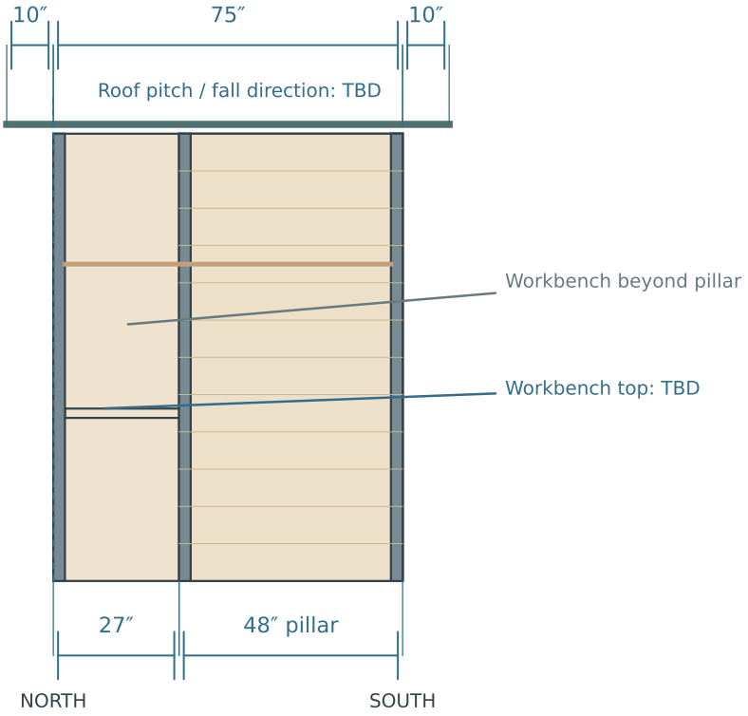
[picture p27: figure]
48 pillar; NORTH; SOUTH; Workbench beyond pillar; Workbench top: TBD; Roof pitch / fall direction: TBD

### MEASURED / USER-SUPPLIED

Workbench: 27 E W × 75 N S, against garage west wall. Workbench north end aligns with garage north wall. Electrical pillar: 10 E W × 48 N S; south faces align. Connecting beam: 137¼ long × 18 high × 2½ deep. Beam frame: 2½ × 2½ tube; tube wall thickness unknown. Other main supports: 2½ × 2½ × ¼ steel angle.
Roof framing: ¾ rectangular steel tube; other section dimension / wall thickness / spacing not supplied.
Roof panels: corrugated plastic; three 10 overhangs.

### CHECK BEFORE COMBINING WITH GARAGE

* Beam drawn between inner faces of the two supports. Result: 174¼ overall width; 184¼ roof width.
Roof east edge drawn meeting garage wall; confirm. Overall height, beam-bottom height, bench-top height and roof pitch are unmeasured. Vertical positions are schematic; only the 18 beam height is dimensioned. Beam south face taken flush with both support faces.

# Existing outbuilding · dimension check

PLAN + ELEVATIONS / Dimensions in inches / Standalone survey draft for review

Heights are schematic, not measured from photos. Derived dimensions marked * depend on the beam-end interpretation. No garage proposal geometry changed.

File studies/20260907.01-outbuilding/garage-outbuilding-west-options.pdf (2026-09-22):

NORTH | SOUTH

30° integrated solar roof

## A · One window south of the balcony

Existing outbuilding roof

NORTH | SOUTH

30° integrated solar roof

## B · Three small windows following the slope

Existing outbuilding roof

# Garage + existing outbuilding · west elevation comparison

Both window options retained · outbuilding shown in front of garage · north left / south right

Existing outbuilding: tan infill, gray steel and green roof line. Proposed garage walkway / balcony: white framing at loft-floor level.

Outbuilding heights and grade remain approximate, as accepted. Apparent roof-to-balcony separation is not a verified clearance.

Base shallow-cap profile used for this overlay. Both projecting-cornice and low-hip alternatives remain available. No FreeCAD geometry changed.

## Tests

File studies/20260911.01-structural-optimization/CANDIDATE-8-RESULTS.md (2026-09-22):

# Candidate 8 — garage structural study

**Recommendation:** carry forward this braced steel scheme as the next design candidate. It supports the studied loft and roof without assigning vertical capacity to the old walls or slab. It is not a permitted or fabrication-ready design, and is not a proven global cost minimum.

## Main choices

- Remove W2; retain the other nine ground columns. Strengthen TW diagonals to compensate.
- B2: W8×24. T1 future suspended floor beam: W6×15. T-SO: W6×15.
- TE upper chord: HSS 6×6×1/4. TE lower chord: HSS 4×4×1/2, centerline raised from 115 to 118 in to clear old rafters while retaining the floor and roof elevations.
- TE webs: HSS 3×3×1/4. Most other webs remain HSS 2×2×1/8. TW diagonals: HSS 3×3×1/8.
- TW lower chord: HSS 4×4×1/4; upper: HSS 4×4×5/16. The heavier bottom chord avoids relying on the future loft for its roof-first lateral restraint.
- Typical posts: HSS 4×4×1/4. W4 and N2: HSS 4×4×3/8. N1/U-W retains its 6×6×1/4 candidate section. The CSV records all remaining sections.
- Add 16 diagonal bracing members: four lower perimeter bays, two upper-wall bays and two roof-plane bays. The north lower braces move 4 in north for eave clearance; their offset connections need design.

## What the computations establish

Primary steel: 9,408 lb, plus a separate assumed 10% connection dead-weight reserve of 941 lb. This includes primary beams, trusses, posts and the explicit new braces. Secondary roof framing is included only as part of the roof assembly weight allowance. Earlier lighter gravity-only candidates omitted this bracing and are not equivalent completed designs.

Maximum screened member ratio: 0.82 in the completed stage and 0.84 in the roof-first stage. Values below 1 pass the implemented checks; they are not safety factors or proof of every limit state. The additional full-length lower-chord buckling check gives 0.87 for roof-first construction. Upper chords and trolley rails still require designed lateral/torsional restraint at no more than 72 in.

Maximum main floor-support movement under dead, storage-band and roof live loads: 0.58 in. B2 live-only deflection relative to its moving supports: 0.35 in versus a 256.25/360 = 0.71 in comparison. Midspan B2 hoist-case relative deflection: 0.61 in. These are steel-support results, not plywood or joist deflections.

The 10 psf equivalent horizontal-force test gives 0.34 in in the east–west direction and 0.11 in north–south. Roof-first results are 0.34 and 0.11 in. Pinned-base tests give 0.35 and 0.12 in, so these results no longer depend strongly on fixed bases. Tests in both directions at twice the lateral force are included in member checks.

These lateral loads are diagnostic roof-level horizontal forces derived from 10/20 psf times a projected rectangle, not a code wind-pressure distribution. They are not San Diego wind or seismic design loads. The completed candidate uses P–Delta analysis; release/base sensitivities use separate cases. Global force balance, linear moment balance, a closed-form beam benchmark and an axial-force sign check were used. Explicit offset links use finite high stiffness, with a lower-stiffness sensitivity. Coordinates are rounded to 0.001 in to avoid spurious microscopic elements.

## Loads and lightweight envelope

The loft is 275.64 ft². Uniform 40 psf live load is 11,026 lb. The storage case raises 36-in bands along the north and east edges to 75 psf. One 200-lb machine case is also applied over the general floor load. The hoist is 1,000 lb rated, with 25% assumed impact plus 100 lb assumed equipment weight, tested at three trolley positions on each rail. One hoist operates at a time. The separate exterior jib crane, landing ledge and a 1,000-lb concentrated load on plywood are not approved by this trolley analysis.

Dead-load ledger for the candidate:

- Primary steel plus connection allowance: 10,349 lb.
- Loft joists/deck allowance: 3,308 lb (12 psf).
- Roof assembly allowance: 6,058 lb (9.5 psf main sloped surface; 6.6 psf cap).
- Lightweight wall allowance: 2,329 lb (4 psf gross wall surface).

A representative REC module weighs 50 lb over 22.4 ft², about 2.23 psf ([manufacturer data](https://www.recgroup.com/sites/default/files/2025-04/Web_DS_REC%20Alpha%20Pure-RX_EN%20US_042025.pdf)). Metl-Span lists roughly 2.1–3.2 psf for the shown 2-in insulated metal-panel configurations ([panel weights](https://metlspan.com/wp-content/uploads/2022/11/PSF-Panel-Weights_2019.pdf)). These support retaining a lightweight assembly: solar above waterproof metal, foam insulation and metal interior skin. The remaining roof allowance covers secondary framing, fasteners, flashings and reserve. Product attachment, ventilation and the complete roof fire/waterproofing assembly remain to be specified.

The 125 psf storage sensitivity does NOT pass: maximum screened ratio 1.47. The owner’s 40 psf target is not a determination of the legally applicable occupancy load. Confirm that classification under [San Diego's adopted codes](https://www.sandiego.gov/development-services/codes-regulations) before treating these sizes as the design basis. Existing walls do not justify reducing the required load or safety factors.

## Foundations and existing walls

Uplift remains a structural design issue that can be addressed with an engineered load path through connections, anchors, reinforced foundations and soil. It has not been eliminated by assumption. In the service40 case S2 is +0.05 kip and SW0 is -2.95 kip. Bracing redistributes forces. The reaction CSV includes the larger lateral-test demands; those are not final foundation design loads.

No footing dimensions have been approved. The old estimated 18-in by 36-in piers cannot be assumed adequate for uplift, overturning or soil bearing. New connections to the old walls must account for actual stiffness and differential movement; a rigid connection can transfer weight into an old wall even when its capacity is not credited in calculations. Do not use the previous 20 years of performance as a quantified reserve capacity.

## Build-around-existing check

The candidate is saved separately as Garage-Candidate-8.FCStd. The original Proposed-Garage.FCStd remains unchanged. CAD was reopened and all 121 candidate steel solids validated. The existing roof is unclad in that model; field clearances and cladding thickness still matter.

TE now clears the modeled old roof framing by a minimum of 0.35 in. This does not include old roof cladding or erection tolerance; field measurement is required before accepting roof-first clearance.

Remaining modeled intersections involve: BR-E-ground-2, N1 / U-W, N2, S3. See candidate8-clearance-check.json for each existing component. These require planned local openings or adjustment before erection; do not cut loaded existing framing based on this model. Roof-first means the complete tested braced frame and secondary roof restraint are installed, not that any partially erected sequence is stable.

The braced bays must be reviewed against windows, the covered walkway, the outbuilding and access. The main north garage-door opening is left clear. Upper north bracing may affect the adjacent window treatment.

## Secondary framing and remaining design

For the modeled approximately 109-in joist span at 16-in centers, a 1.5×7.25-in wood joist needs approximately 1,093 psi adjusted bending strength and 1.06 million psi modulus to meet the simple 75 psf live + 12 psf dead checks used here. This is a demand specification; species/grade, adjustments, hangers, bearing and plywood point-load capacity still need selection.

At a trial 48-in spacing and 256.25-in span, an E–W roof purlin needs roughly I = 12.1 in⁴ for the provisional roof-live L/240 comparison, and elastic section modulus at least 2.7 in³ for the stated factored gravity load. These are lower-bound property targets, not a cold-formed section design. A supplier/AISI check must include local/distortional buckling, continuity, uplift and bracing. Roof fasteners alone are not an automatically adequate diaphragm.

Still needed before fabrication: actual joint and HSS face checks; welds/bolts/gussets; member torsion/warping and complete applicable code interaction checks; rail flange/wheel contact and hoist side loads; site wind/seismic load cases and combinations; foundation/soil design; fire and property-line requirements; and erection-stage sequencing. A California structural engineer should verify and complete that design.

## Cost and reproducibility

This is the best-performing candidate tested in this study, not proof of the cheapest possible structure. W2 removal requires stronger TW diagonals; its earlier net steel saving was only about 150 lb, so avoided foundation work is the main potential benefit. Whether welding or bolting is cheaper depends on the connection details and shop/erection quotes. A hybrid with shop-fabricated truss sections and site connections is a pricing option, not an established winner.

Files include the Python model, stock catalog, geometry, load basis, member checks and every case reaction. Run candidate8.py with PyNiteFEA 3.0.0 after installing requirements.txt to repeat this candidate from the supplied prior selection input. Change design-basis.json for loads, re-export geometry when CAD changes, and compare all cases before accepting a revision. The historical trials have different scope/assumptions; candidate8 results are the current reference.

Compression uses the AISC E3 column curve; W bending screening includes lateral-torsional buckling with Cb=1. Axial/biaxial demands are combined conservatively with elastic capacities. These partial checks are not an automatic AISC compliance engine. [AISC specification formula reference](https://www.aisc.org/globalassets/aisc/publications/standards/a360-16-spec-and-commentary_march-2021.pdf), [Atlas HSS section properties](https://www.atlastube.com/wp-content/uploads/2018/04/A500-Square-Current.pdf), [PyNite analysis API](https://pynite.readthedocs.io/en/latest/FEModel3D.html).

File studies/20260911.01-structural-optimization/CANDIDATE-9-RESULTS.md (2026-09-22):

# Candidate 9 — garage structural study

**Recommendation:** carry forward this braced steel scheme as the next design candidate. It supports the studied loft and roof without assigning vertical capacity to the old walls or slab. It is not a permitted or fabrication-ready design, and is not a proven global cost minimum.

## Main choices

- Remove W2; retain the other nine ground columns. Strengthen TW diagonals to compensate.
- B2: W8×24. T1 future suspended floor beam: W6×15. T-SO: W6×15.
- TE upper chord: HSS 6×6×1/4. TE lower chord: HSS 4×4×1/2, centerline raised from 115 to 120 in to clear old rafters while retaining the floor and roof elevations.
- TE webs: HSS 3×3×1/4. Most other webs remain HSS 2×2×1/8. TW diagonals: HSS 3×3×1/8.
- TW lower chord: HSS 4×4×1/4; upper: HSS 4×4×5/16. The heavier bottom chord avoids relying on the future loft for its roof-first lateral restraint.
- Typical posts: HSS 4×4×1/4. W4 and N2: HSS 4×4×3/8. N1/U-W retains its 6×6×1/4 candidate section. The CSV records all remaining sections.
- Add 16 diagonal bracing members: four lower perimeter bays, two upper-wall bays and two roof-plane bays. The north lower braces move 4 in north for eave clearance; their offset connections need design.

## What the computations establish

Primary steel: 9,387 lb, plus a separate assumed 10% connection dead-weight reserve of 939 lb. This includes primary beams, trusses, posts and the explicit new braces. Secondary roof framing is included only as part of the roof assembly weight allowance. Earlier lighter gravity-only candidates omitted this bracing and are not equivalent completed designs.

Maximum screened member ratio: 0.82 in the completed stage and 0.84 in the roof-first stage. Values below 1 pass the implemented checks; they are not safety factors or proof of every limit state. The additional full-length lower-chord buckling check gives 0.87 for roof-first construction. Upper chords and trolley rails still require designed lateral/torsional restraint at no more than 72 in.

Maximum main floor-support movement under dead, storage-band and roof live loads: 0.57 in. B2 live-only deflection relative to its moving supports: 0.35 in versus a 256.25/360 = 0.71 in comparison. Midspan B2 hoist-case relative deflection: 0.60 in. These are steel-support results, not plywood or joist deflections.

The 10 psf equivalent horizontal-force test gives 0.34 in in the east–west direction and 0.11 in north–south. Roof-first results are 0.34 and 0.11 in. Pinned-base tests give 0.35 and 0.12 in, so these results no longer depend strongly on fixed bases. Tests in both directions at twice the lateral force are included in member checks.

These lateral loads are diagnostic roof-level horizontal forces derived from 10/20 psf times a projected rectangle, not a code wind-pressure distribution. They are not San Diego wind or seismic design loads. The completed candidate uses P–Delta analysis; release/base sensitivities use separate cases. Global force balance, linear moment balance, a closed-form beam benchmark and an axial-force sign check were used. Explicit offset links use finite high stiffness, with a lower-stiffness sensitivity. Coordinates are rounded to 0.001 in to avoid spurious microscopic elements.

## Loads and lightweight envelope

The clear deck is 273.18 ft² after trimming 2 in from its east edge against the raised TE chord. Loads conservatively retain the earlier 275.64 ft² footprint. TE projects 1.25 in above the finished deck at the wall edge; its cladding/guard detail requires review. Uniform 40 psf live load is 11,026 lb. The storage case raises 36-in bands along the north and east edges to 75 psf. One 200-lb machine case is also applied over the general floor load. The hoist is 1,000 lb rated, with 25% assumed impact plus 100 lb assumed equipment weight, tested at three trolley positions on each rail. One hoist operates at a time. The separate exterior jib crane, landing ledge and a 1,000-lb concentrated load on plywood are not approved by this trolley analysis.

Dead-load ledger for the candidate:

- Primary steel plus connection allowance: 10,326 lb.
- Loft joists/deck allowance: 3,308 lb (12 psf).
- Roof assembly allowance: 6,058 lb (9.5 psf main sloped surface; 6.6 psf cap).
- Lightweight wall allowance: 2,331 lb (4 psf gross wall surface).

A representative REC module weighs 50 lb over 22.4 ft², about 2.23 psf ([manufacturer data](https://www.recgroup.com/sites/default/files/2025-04/Web_DS_REC%20Alpha%20Pure-RX_EN%20US_042025.pdf)). Metl-Span lists roughly 2.1–3.2 psf for the shown 2-in insulated metal-panel configurations ([panel weights](https://metlspan.com/wp-content/uploads/2022/11/PSF-Panel-Weights_2019.pdf)). These support retaining a lightweight assembly: solar above waterproof metal, foam insulation and metal interior skin. The remaining roof allowance covers secondary framing, fasteners, flashings and reserve. Product attachment, ventilation and the complete roof fire/waterproofing assembly remain to be specified.

The 125 psf storage sensitivity does NOT pass: maximum screened ratio 1.48. The owner’s 40 psf target is not a determination of the legally applicable occupancy load. Confirm that classification under [San Diego's adopted codes](https://www.sandiego.gov/development-services/codes-regulations) before treating these sizes as the design basis. Existing walls do not justify reducing the required load or safety factors.

## Foundations and existing walls

Uplift remains a structural design issue that can be addressed with an engineered load path through connections, anchors, reinforced foundations and soil. It has not been eliminated by assumption. In the service40 case S2 is +0.07 kip and SW0 is -2.95 kip. Bracing redistributes forces. The reaction CSV includes the larger lateral-test demands; those are not final foundation design loads.

No footing dimensions have been approved. The old estimated 18-in by 36-in piers cannot be assumed adequate for uplift, overturning or soil bearing. New connections to the old walls must account for actual stiffness and differential movement; a rigid connection can transfer weight into an old wall even when its capacity is not credited in calculations. Do not use the previous 20 years of performance as a quantified reserve capacity.

## Build-around-existing check

The candidate is saved separately as Garage-Candidate-9.FCStd. The original Proposed-Garage.FCStd remains unchanged. CAD was reopened and all 121 candidate steel solids validated. The existing roof is unclad in that model; field clearances and cladding thickness still matter.

TE now clears the modeled old roof framing by a minimum of 2.17 in. This does not include old roof cladding or erection tolerance; field measurement is required before accepting roof-first clearance.

Remaining modeled intersections involve: BR-E-ground-2, N1 / U-W, N2, S3. See candidate9-clearance-check.json for each existing component. These require planned local openings or adjustment before erection; do not cut loaded existing framing based on this model. Roof-first means the complete tested braced frame and secondary roof restraint are installed, not that any partially erected sequence is stable.

The braced bays must be reviewed against windows, the covered walkway, the outbuilding and access. The main north garage-door opening is left clear. Upper north bracing may affect the adjacent window treatment.

## Secondary framing and remaining design

For the modeled approximately 109-in joist span at 16-in centers, a 1.5×7.25-in wood joist needs approximately 1,093 psi adjusted bending strength and 1.06 million psi modulus to meet the simple 75 psf live + 12 psf dead checks used here. This is a demand specification; species/grade, adjustments, hangers, bearing and plywood point-load capacity still need selection.

At a trial 48-in spacing and 256.25-in span, an E–W roof purlin needs roughly I = 12.1 in⁴ for the provisional roof-live L/240 comparison, and elastic section modulus at least 2.7 in³ for the stated factored gravity load. These are lower-bound property targets, not a cold-formed section design. A supplier/AISI check must include local/distortional buckling, continuity, uplift and bracing. Roof fasteners alone are not an automatically adequate diaphragm.

Still needed before fabrication: actual joint and HSS face checks; welds/bolts/gussets; member torsion/warping and complete applicable code interaction checks; rail flange/wheel contact and hoist side loads; site wind/seismic load cases and combinations; foundation/soil design; fire and property-line requirements; and erection-stage sequencing. A California structural engineer should verify and complete that design.

## Cost and reproducibility

This is the best-performing candidate tested in this study, not proof of the cheapest possible structure. W2 removal requires stronger TW diagonals; its earlier net steel saving was only about 150 lb, so avoided foundation work is the main potential benefit. Whether welding or bolting is cheaper depends on the connection details and shop/erection quotes. A hybrid with shop-fabricated truss sections and site connections is a pricing option, not an established winner.

Files include the Python model, stock catalog, geometry, load basis, member checks and every case reaction. Run candidate9.py with PyNiteFEA 3.0.0 after installing requirements.txt to repeat this candidate from the supplied prior selection input. Change design-basis.json for loads, re-export geometry when CAD changes, and compare all cases before accepting a revision. The historical trials have different scope/assumptions; candidate9 results are the current reference.

Compression uses the AISC E3 column curve; W bending screening includes lateral-torsional buckling with Cb=1. Axial/biaxial demands are combined conservatively with elastic capacities. These partial checks are not an automatic AISC compliance engine. [AISC specification formula reference](https://www.aisc.org/globalassets/aisc/publications/standards/a360-16-spec-and-commentary_march-2021.pdf), [Atlas HSS section properties](https://www.atlastube.com/wp-content/uploads/2018/04/A500-Square-Current.pdf), [PyNite analysis API](https://pynite.readthedocs.io/en/latest/FEModel3D.html).

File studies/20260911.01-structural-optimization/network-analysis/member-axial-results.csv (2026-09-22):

truss | stage | case | physical_member | maximum_compression_lb | maximum_tension_lb
T1 | complete | service40 | T1 upper lower chord | 628.55068900038 | 2352.17711994622
T1 | complete | service40 | T1 future floor beam | 0.0 | 684.7335280684521
T1 | complete | service40 | T1 vertical 1 | 0.0 | 1318.4111848859168
T1 | complete | service40 | T1 vertical 2 | 0.0 | 1105.6869516910613
T1 | complete | service40 | T1 vertical 3 | 46.927190105901275 | 0.0
T1 | complete | service40 | T1 vertical 4 | 0.0 | 1143.100698760353
T1 | complete | service40 | T1 vertical 5 | 0.0 | 630.1344096089192
T1 | complete | service40 | T1 diagonal 6 | 3309.64705209312 | 0.0
T1 | complete | service40 | T1 diagonal 7 | 0.0 | 1322.2392415006475
T1 | complete | service40 | T1 diagonal 8 | 0.0 | 1360.4804233042084
T1 | complete | service40 | T1 diagonal 9 | 3386.267889245648 | 0.0
T1 | complete | service40 | T1 future hanger 1 | 0.0 | 404.7758329747445
T1 | complete | service40 | T1 future hanger 2 | 0.0 | 1126.8756316619429
T1 | complete | service40 | T1 future hanger 3 | 0.0 | 1407.183251941354
T1 | complete | service40 | T1 future hanger 4 | 0.0 | 1160.6970616611604
T1 | complete | service40 | T1 future hanger 5 | 0.0 | 152.96636497411097
T1 | complete | service40 | T1 top / segment 1 | 3811.6652546069095 | 124.62302089399606
T1 | complete | service_patches | T1 upper lower chord | 669.6440648077113 | 2370.3919730993043
T1 | complete | service_patches | T1 future floor beam | 0.0 | 730.649909616942
T1 | complete | service_patches | T1 vertical 1 | 0.0 | 1337.3402064017732
T1 | complete | service_patches | T1 vertical 2 | 0.0 | 1105.5296751607045
T1 | complete | service_patches | T1 vertical 3 | 48.91584715000758 | 0.0
T1 | complete | service_patches | T1 vertical 4 | 0.0 | 1292.635158804336
T1 | complete | service_patches | T1 vertical 5 | 0.0 | 733.7117128855542
T1 | complete | service_patches | T1 diagonal 6 | 3365.4305534126242 | 0.0
T1 | complete | service_patches | T1 diagonal 7 | 0.0 | 1383.9763457388717
T1 | complete | service_patches | T1 diagonal 8 | 0.0 | 1273.4852873116283
T1 | complete | service_patches | T1 diagonal 9 | 3554.6694748739887 | 0.0
T1 | complete | service_patches | T1 future hanger 1 | 0.0 | 407.4890905872915
T1 | complete | service_patches | T1 future hanger 2 | 0.0 | 1128.9960288054172
T1 | complete | service_patches | T1 future hanger 3 | 0.0 | 1388.2065331303454
T1 | complete | service_patches | T1 future hanger 4 | 0.0 | 1317.7064850435038
T1 | complete | service_patches | T1 future hanger 5 | 0.0 | 235.0747022013026
T1 | complete | service_patches | T1 top / segment 1 | 3898.710451242045 | 105.7243925009249
T1 | complete | typical30 | T1 upper lower chord | 499.5944675131416 | 1973.8333668289943
T1 | complete | typical30 | T1 future floor beam | 0.0 | 574.1528268064828
T1 | complete | typical30 | T1 vertical 1 | 0.0 | 1086.2736284362197
T1 | complete | typical30 | T1 vertical 2 | 0.0 | 909.5521224907586
T1 | complete | typical30 | T1 vertical 3 | 46.094794886168415 | 0.0
T1 | complete | typical30 | T1 vertical 4 | 0.0 | 945.8649224226592
T1 | complete | typical30 | T1 vertical 5 | 0.0 | 559.9214064707409
T1 | complete | typical30 | T1 diagonal 6 | 2775.5795536924484 | 0.0
T1 | complete | typical30 | T1 diagonal 7 | 0.0 | 1115.135312359373
T1 | complete | typical30 | T1 diagonal 8 | 0.0 | 1122.1629417285105
T1 | complete | typical30 | T1 diagonal 9 | 2822.2690113717563 | 0.0
T1 | complete | typical30 | T1 future hanger 1 | 0.0 | 328.010624155399
T1 | complete | typical30 | T1 future hanger 2 | 0.0 | 918.8304273662218
T1 | complete | typical30 | T1 future hanger 3 | 0.0 | 1154.5203541775961
T1 | complete | typical30 | T1 future hanger 4 | 0.0 | 952.137956235824
T1 | complete | typical30 | T1 future hanger 5 | 0.0 | 172.755678725264
T1 | complete | typical30 | T1 top / segment 1 | 3196.7776929535817 | 72.8749230175916
T1 | complete | storage125_sensitivity | T1 upper lower chord | 1497.0639979417715 | 5568.196787304232
T1 | complete | storage125_sensitivity | T1 future floor beam | 0.0 | 1639.885866047532
T1 | complete | storage125_sensitivity | T1 vertical 1 | 0.0 | 2904.2470496512497
T1 | complete | storage125_sensitivity | T1 vertical 2 | 0.0 | 2713.017240608435
T1 | complete | storage125_sensitivity | T1 vertical 3 | 52.28422352510583 | 0.0
T1 | complete | storage125_sensitivity | T1 vertical 4 | 0.0 | 2898.6813166367097
T1 | complete | storage125_sensitivity | T1 vertical 5 | 0.0 | 1590.883551951611
T1 | complete | storage125_sensitivity | T1 diagonal 6 | 7940.779962900953 | 0.0
T1 | complete | storage125_sensitivity | T1 diagonal 7 | 0.0 | 3282.7503985485355
T1 | complete | storage125_sensitivity | T1 diagonal 8 | 0.0 | 3175.193753887437
T1 | complete | storage125_sensitivity | T1 diagonal 9 | 8129.347342427185 | 0.0
T1 | complete | storage125_sensitivity | T1 future hanger 1 | 0.0 | 653.6536312756191
T1 | complete | storage125_sensitivity | T1 future hanger 2 | 0.0 | 2835.2848239945724
T1 | complete | storage125_sensitivity | T1 future hanger 3 | 0.0 | 3550.8814460881513
T1 | complete | storage125_sensitivity | T1 future hanger 4 | 0.0 | 3013.628787983778
T1 | complete | storage125_sensitivity | T1 future hanger 5 | 0.0 | 397.8576042415071
T1 | complete | storage125_sensitivity | T1 top / segment 1 | 9172.01532370631 | 215.3088705668425
T1 | complete | live_only | T1 upper lower chord | 408.7121585676738 | 1513.4210177873226
T1 | complete | live_only | T1 future floor beam | 0.0 | 449.48345364519304
T1 | complete | live_only | T1 vertical 1 | 0.0 | 746.2757058659979
T1 | complete | live_only | T1 vertical 2 | 0.0 | 756.3907278732031
T1 | complete | live_only | T1 vertical 3 | 2.5209572388260355 | 0.0
T1 | complete | live_only | T1 vertical 4 | 0.0 | 826.1555823906068
T1 | complete | live_only | T1 vertical 5 | 0.0 | 452.11724055908115
T1 | complete | live_only | T1 diagonal 6 | 2179.3567430257917 | 0.0
T1 | complete | live_only | T1 diagonal 7 | 0.0 | 922.5934762088707
T1 | complete | live_only | T1 diagonal 8 | 0.0 | 853.9827542009315
T1 | complete | live_only | T1 diagonal 9 | 2232.0374478783633 | 0.0
T1 | complete | live_only | T1 future hanger 1 | 0.0 | 117.11896418546482
T1 | complete | live_only | T1 future hanger 2 | 0.0 | 803.9572702040576
T1 | complete | live_only | T1 future hanger 3 | 0.0 | 1008.7991502557178
T1 | complete | live_only | T1 future hanger 4 | 0.0 | 871.9678691738726
T1 | complete | live_only | T1 future hanger 5 | 0.0 | 115.24293579790005
T1 | complete | live_only | T1 top / segment 1 | 2522.5176653263634 | 47.11099288387296
T1 | complete | machine200 | T1 upper lower chord | 611.0635886362846 | 2385.2321058308594
T1 | complete | machine200 | T1 future floor beam | 0.0 | 698.5987012172911
T1 | complete | machine200 | T1 vertical 1 | 0.0 | 1288.2548836247893
T1 | complete | machine200 | T1 vertical 2 | 0.0 | 1096.4783049353578
T1 | complete | machine200 | T1 vertical 3 | 46.193244877857744 | 0.0
T1 | complete | machine200 | T1 vertical 4 | 0.0 | 1169.645219120745
T1 | complete | machine200 | T1 vertical 5 | 0.0 | 682.8490672885358
T1 | complete | machine200 | T1 diagonal 6 | 3368.676536619778 | 0.0
T1 | complete | machine200 | T1 diagonal 7 | 0.0 | 1399.075177103429
T1 | complete | machine200 | T1 diagonal 8 | 0.0 | 1371.2934825345976
T1 | complete | machine200 | T1 diagonal 9 | 3444.461729240336 | 0.0
T1 | complete | machine200 | T1 future hanger 1 | 0.0 | 358.6112356664609
T1 | complete | machine200 | T1 future hanger 2 | 0.0 | 1117.817416106031
T1 | complete | machine200 | T1 future hanger 3 | 0.0 | 1458.581235459106
T1 | complete | machine200 | T1 future hanger 4 | 0.0 | 1188.318068090154
T1 | complete | machine200 | T1 future hanger 5 | 0.0 | 200.82012895164453
T1 | complete | machine200 | T1 top / segment 1 | 3909.7620073806 | 84.10047166018977
T1 | complete | uplift20_sensitivity | T1 upper lower chord | 89.05804058796498 | 503.272061195815
T1 | complete | uplift20_sensitivity | T1 future floor beam | 0.0 | 144.01430447255294
T1 | complete | uplift20_sensitivity | T1 vertical 1 | 0.0 | 270.3714858418241
T1 | complete | uplift20_sensitivity | T1 vertical 2 | 0.0 | 198.31830302978437
T1 | complete | uplift20_sensitivity | T1 vertical 3 | 26.320290681061763 | 0.0
T1 | complete | uplift20_sensitivity | T1 vertical 4 | 0.0 | 205.0520565381674
T1 | complete | uplift20_sensitivity | T1 vertical 5 | 0.0 | 175.3163890400637
T1 | complete | uplift20_sensitivity | T1 diagonal 6 | 695.4088959259783 | 0.0
T1 | complete | uplift20_sensitivity | T1 diagonal 7 | 0.0 | 277.4585523049879
T1 | complete | uplift20_sensitivity | T1 diagonal 8 | 0.0 | 264.1837447495049
T1 | complete | uplift20_sensitivity | T1 diagonal 9 | 682.9550546066627 | 0.0
T1 | complete | uplift20_sensitivity | T1 future hanger 1 | 0.0 | 96.6173733489716
T1 | complete | uplift20_sensitivity | T1 future hanger 2 | 0.0 | 182.46160188662478
T1 | complete | uplift20_sensitivity | T1 future hanger 3 | 0.0 | 238.2894849275972
T1 | complete | uplift20_sensitivity | T1 future hanger 4 | 0.0 | 188.33009089894085
T1 | complete | uplift20_sensitivity | T1 future hanger 5 | 0.0 | 100.39413380234896
T1 | complete | uplift20_sensitivity | T1 top / segment 1 | 798.6755042096995 | 5.446696539176469
T1 | complete | strength_screen | T1 upper lower chord | 964.7503856442523 | 3457.132763498355
T1 | complete | strength_screen | T1 future floor beam | 0.0 | 1076.1929401391997
T1 | complete | strength_screen | T1 vertical 1 | 0.0 | 1878.9921083742083
T1 | complete | strength_screen | T1 vertical 2 | 0.0 | 1624.2029948969032
T1 | complete | strength_screen | T1 vertical 3 | 60.36135372229658 | 0.0
T1 | complete | strength_screen | T1 vertical 4 | 0.0 | 1947.9503841375179
T1 | complete | strength_screen | T1 vertical 5 | 0.0 | 1132.703281812296
T1 | complete | strength_screen | T1 diagonal 6 | 4940.112883698906 | 0.0
T1 | complete | strength_screen | T1 diagonal 7 | 0.0 | 2070.9849368682444
T1 | complete | strength_screen | T1 diagonal 8 | 0.0 | 1817.6021566202583
T1 | complete | strength_screen | T1 diagonal 9 | 5221.586299299839 | 0.0
T1 | complete | strength_screen | T1 future hanger 1 | 0.0 | 503.67997084849424
T1 | complete | strength_screen | T1 future hanger 2 | 0.0 | 1672.287187188853
T1 | complete | strength_screen | T1 future hanger 3 | 0.0 | 2061.452635383288
T1 | complete | strength_screen | T1 future hanger 4 | 0.0 | 1999.4416964107475
T1 | complete | strength_screen | T1 future hanger 5 | 0.0 | 395.050185322988
T1 | complete | strength_screen | T1 top / segment 1 | 5733.2969562373755 | 107.62474121078084
T1 | complete | HB0.25 | T1 upper lower chord | 599.162612673331 | 2356.0860523367405
T1 | complete | HB0.25 | T1 future floor beam | 0.0 | 705.8191300241332
T1 | complete | HB0.25 | T1 vertical 1 | 0.0 | 1280.3844066522774
T1 | complete | HB0.25 | T1 vertical 2 | 0.0 | 1112.2499228853383
T1 | complete | HB0.25 | T1 vertical 3 | 47.70014323946116 | 0.0
T1 | complete | HB0.25 | T1 vertical 4 | 0.0 | 1164.290077606447
T1 | complete | HB0.25 | T1 vertical 5 | 0.0 | 678.4801319289429
T1 | complete | HB0.25 | T1 diagonal 6 | 3344.7590970815995 | 0.0
T1 | complete | HB0.25 | T1 diagonal 7 | 0.0 | 1352.7943604653346
T1 | complete | HB0.25 | T1 diagonal 8 | 0.0 | 1323.5426390310363
T1 | complete | HB0.25 | T1 diagonal 9 | 3386.845322738915 | 0.0
T1 | complete | HB0.25 | T1 future hanger 1 | 0.0 | 349.8920174817718
T1 | complete | HB0.25 | T1 future hanger 2 | 0.0 | 1134.399148113894
T1 | complete | HB0.25 | T1 future hanger 3 | 0.0 | 1402.5294310826023
T1 | complete | HB0.25 | T1 future hanger 4 | 0.0 | 1181.8949363882045
T1 | complete | HB0.25 | T1 future hanger 5 | 0.0 | 197.66649486539194
T1 | complete | HB0.25 | T1 top / segment 1 | 3848.934136415694 | 57.985767170047225
T1 | complete | HB0.5 | T1 upper lower chord | 598.0836553744714 | 2354.8895350739012
T1 | complete | HB0.5 | T1 future floor beam | 0.0 | 711.2387396516544
T1 | complete | HB0.5 | T1 vertical 1 | 0.0 | 1284.7583583189198
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

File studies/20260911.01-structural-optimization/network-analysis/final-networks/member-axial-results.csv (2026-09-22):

truss | stage | case | physical_member | maximum_compression_lb | maximum_tension_lb
T1 | complete | service40 | T1 upper lower chord | 668.7502512878398 | 2328.2051098749216
T1 | complete | service40 | T1 future floor beam | 0.0 | 681.98289435261
T1 | complete | service40 | T1 vertical 1 | 0.0 | 1280.5544436945465
T1 | complete | service40 | T1 vertical 2 | 0.0 | 1108.0960962378524
T1 | complete | service40 | T1 vertical 3 | 49.91360441745666 | 0.0
T1 | complete | service40 | T1 vertical 4 | 0.0 | 1148.0380676433715
T1 | complete | service40 | T1 vertical 5 | 0.0 | 734.8513827678829
T1 | complete | service40 | T1 diagonal 6 | 3289.8962050901687 | 0.0
T1 | complete | service40 | T1 diagonal 7 | 0.0 | 1313.2752595711495
T1 | complete | service40 | T1 diagonal 8 | 0.0 | 1373.7091827398076
T1 | complete | service40 | T1 diagonal 9 | 3394.3073237109174 | 0.0
T1 | complete | service40 | T1 future hanger 1 | 0.0 | 341.9703419080075
T1 | complete | service40 | T1 future hanger 2 | 0.0 | 1127.2072456911962
T1 | complete | service40 | T1 future hanger 3 | 0.0 | 1406.7858454376803
T1 | complete | service40 | T1 future hanger 4 | 0.0 | 1164.4527054183113
T1 | complete | service40 | T1 future hanger 5 | 0.0 | 219.13059667971976
T1 | complete | service40 | T1 top / segment 1 | 3771.9979211461464 | 182.89802454098646
T1 | complete | service_patches | T1 upper lower chord | 716.8160144082121 | 2344.880910945901
T1 | complete | service_patches | T1 future floor beam | 0.0 | 727.5225538468904
T1 | complete | service_patches | T1 vertical 1 | 0.0 | 1298.555812172673
T1 | complete | service_patches | T1 vertical 2 | 0.0 | 1109.0381464003456
T1 | complete | service_patches | T1 vertical 3 | 52.07099930693564 | 0.0
T1 | complete | service_patches | T1 vertical 4 | 0.0 | 1296.6948899343415
T1 | complete | service_patches | T1 vertical 5 | 0.0 | 845.0925940981177
T1 | complete | service_patches | T1 diagonal 6 | 3342.6513924705177 | 0.0
T1 | complete | service_patches | T1 diagonal 7 | 0.0 | 1370.506877415085
T1 | complete | service_patches | T1 diagonal 8 | 0.0 | 1291.1505424094678
T1 | complete | service_patches | T1 diagonal 9 | 3564.26609486993 | 0.0
T1 | complete | service_patches | T1 future hanger 1 | 0.0 | 343.23034525246095
T1 | complete | service_patches | T1 future hanger 2 | 0.0 | 1130.2736136702476
T1 | complete | service_patches | T1 future hanger 3 | 0.0 | 1387.6468784944925
T1 | complete | service_patches | T1 future hanger 4 | 0.0 | 1320.4832062164273
T1 | complete | service_patches | T1 future hanger 5 | 0.0 | 304.4039863032664
T1 | complete | service_patches | T1 top / segment 1 | 3860.5406242955555 | 167.50842430448182
T1 | complete | typical30 | T1 upper lower chord | 519.6132419406838 | 1952.2103722986633
T1 | complete | typical30 | T1 future floor beam | 0.0 | 571.3766930093403
T1 | complete | typical30 | T1 vertical 1 | 0.0 | 1064.4278181327459
T1 | complete | typical30 | T1 vertical 2 | 0.0 | 910.6514361406549
T1 | complete | typical30 | T1 vertical 3 | 48.81547175737273 | 0.0
T1 | complete | typical30 | T1 vertical 4 | 0.0 | 951.4225652927856
T1 | complete | typical30 | T1 vertical 5 | 0.0 | 620.3979687473324
T1 | complete | typical30 | T1 diagonal 6 | 2764.3482806025504 | 0.0
T1 | complete | typical30 | T1 diagonal 7 | 0.0 | 1118.5117147116307
T1 | complete | typical30 | T1 diagonal 8 | 0.0 | 1123.227318834073
T1 | complete | typical30 | T1 diagonal 9 | 2823.455343166699 | 0.0
T1 | complete | typical30 | T1 future hanger 1 | 0.0 | 277.2731297100119
T1 | complete | typical30 | T1 future hanger 2 | 0.0 | 918.1474716559211
T1 | complete | typical30 | T1 future hanger 3 | 0.0 | 1154.4431036500991
T1 | complete | typical30 | T1 future hanger 4 | 0.0 | 956.6443574527653
T1 | complete | typical30 | T1 future hanger 5 | 0.0 | 205.2302157052688
T1 | complete | typical30 | T1 top / segment 1 | 3158.6162967636014 | 113.74335501539971
T1 | complete | storage125_sensitivity | T1 upper lower chord | 1566.4177530368631 | 5512.527443484639
T1 | complete | storage125_sensitivity | T1 future floor beam | 0.0 | 1633.3414435418845
T1 | complete | storage125_sensitivity | T1 vertical 1 | 0.0 | 2857.2039477978515
T1 | complete | storage125_sensitivity | T1 vertical 2 | 0.0 | 2719.8667756045947
T1 | complete | storage125_sensitivity | T1 vertical 3 | 58.90572197074763 | 0.0
T1 | complete | storage125_sensitivity | T1 vertical 4 | 0.0 | 2911.1103517499937
T1 | complete | storage125_sensitivity | T1 vertical 5 | 0.0 | 1760.7054005671566
T1 | complete | storage125_sensitivity | T1 diagonal 6 | 7907.284191135538 | 0.0
T1 | complete | storage125_sensitivity | T1 diagonal 7 | 0.0 | 3275.165755431955
T1 | complete | storage125_sensitivity | T1 diagonal 8 | 0.0 | 3187.0238882984777
T1 | complete | storage125_sensitivity | T1 diagonal 9 | 8135.186664401999 | 0.0
T1 | complete | storage125_sensitivity | T1 future hanger 1 | 0.0 | 541.4774257181942
T1 | complete | storage125_sensitivity | T1 future hanger 2 | 0.0 | 2837.7985206884505
T1 | complete | storage125_sensitivity | T1 future hanger 3 | 0.0 | 3547.559658903871
T1 | complete | storage125_sensitivity | T1 future hanger 4 | 0.0 | 3022.6602247027135
T1 | complete | storage125_sensitivity | T1 future hanger 5 | 0.0 | 484.53074149118856
T1 | complete | storage125_sensitivity | T1 top / segment 1 | 9158.941518645319 | 245.3551238178034
T1 | complete | live_only | T1 upper lower chord | 422.4317695718161 | 1498.5046269496095
T1 | complete | live_only | T1 future floor beam | 0.0 | 447.69814259828524
T1 | complete | live_only | T1 vertical 1 | 0.0 | 741.9527067259793
T1 | complete | live_only | T1 vertical 2 | 0.0 | 758.4803208739792
T1 | complete | live_only | T1 vertical 3 | 4.231584879649311 | 0.0
T1 | complete | live_only | T1 vertical 4 | 0.0 | 829.6810736599239
T1 | complete | live_only | T1 vertical 5 | 0.0 | 482.7548297812301
T1 | complete | live_only | T1 diagonal 6 | 2172.888540228851 | 0.0
T1 | complete | live_only | T1 diagonal 7 | 0.0 | 923.2425834106436
T1 | complete | live_only | T1 diagonal 8 | 0.0 | 853.3245714875078
T1 | complete | live_only | T1 diagonal 9 | 2231.002092099614 | 0.0
T1 | complete | live_only | T1 future hanger 1 | 0.0 | 93.88568298261116
T1 | complete | live_only | T1 future hanger 2 | 0.0 | 804.9841303923023
T1 | complete | live_only | T1 future hanger 3 | 0.0 | 1007.4229715400862
T1 | complete | live_only | T1 future hanger 4 | 0.0 | 874.4505963682025
T1 | complete | live_only | T1 future hanger 5 | 0.0 | 124.89418607382187
T1 | complete | live_only | T1 top / segment 1 | 2535.0322660164124 | 30.56409898193547
T1 | complete | machine200 | T1 upper lower chord | 634.8477887923009 | 2359.4392206791645
T1 | complete | machine200 | T1 future floor beam | 0.0 | 695.3107325037613
T1 | complete | machine200 | T1 vertical 1 | 0.0 | 1265.4731854420693
T1 | complete | machine200 | T1 vertical 2 | 0.0 | 1098.1755180824814
T1 | complete | machine200 | T1 vertical 3 | 49.393406511080094 | 0.0
T1 | complete | machine200 | T1 vertical 4 | 0.0 | 1176.1700504173498
T1 | complete | machine200 | T1 vertical 5 | 0.0 | 751.7984733862695
T1 | complete | machine200 | T1 diagonal 6 | 3355.666417482833 | 0.0
T1 | complete | machine200 | T1 diagonal 7 | 0.0 | 1402.6597476591003
T1 | complete | machine200 | T1 diagonal 8 | 0.0 | 1372.1465447721184
T1 | complete | machine200 | T1 diagonal 9 | 3445.308209265609 | 0.0
T1 | complete | machine200 | T1 future hanger 1 | 0.0 | 301.60889290908955
T1 | complete | machine200 | T1 future hanger 2 | 0.0 | 1117.436893945386
T1 | complete | machine200 | T1 future hanger 3 | 0.0 | 1458.1179225320336
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

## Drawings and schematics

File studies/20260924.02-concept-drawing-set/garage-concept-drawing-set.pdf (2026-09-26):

GARAGE RENOVATION | CONCEPT DRAWING SET · NOT FOR CONSTRUCTION
COVER / DRAWING INDEX | STATUS CONCEPT | REV P0 | DATE 2026-09-24 | G0.01

# GARAGE RENOVATION

# CONCEPT DRAWING SET

# Architecture · structure · electrical · data · shop air

## BASIS OF SET

Current structural model: frame-20260920.01-beam-scheme.compas.json Current architectural/equipment layout: cabinets.py
Units: inches. North is up on plans unless noted.
Member and equipment locations are taken directly from the current model. Electrical, Ethernet, compressed-air and dust routes are conceptual.

## DRAWING INDEX

G0.01 Cover / drawing index
A1.01 Isometric and exterior elevations A1.02 Loft equipment and cabinet plan A1.03 Ground-floor and shed equipment plan

E1.01 Concept electrical distribution
T1.01 Concept Ethernet distribution
M1.01 Concept dust collection and compressed air

## USE AND LIMITATIONS

This set records design intent for coordination and discussion. It is not a permit set, fabrication package, or construction document.
A licensed design professional must verify dimensions, loads, connections, foundations, fire/life-safety work and all MEP requirements before construction.

Proposed service routes show endpoints and zoning; conductor, cable, pipe and duct sizes remain to be designed.

ISOMETRIC — CURRENT FRAME | SCALE: DIAGRAMMATIC
NORTH ELEVATION — LOOKING SOUTH | SCALE: DIAGRAMMATIC

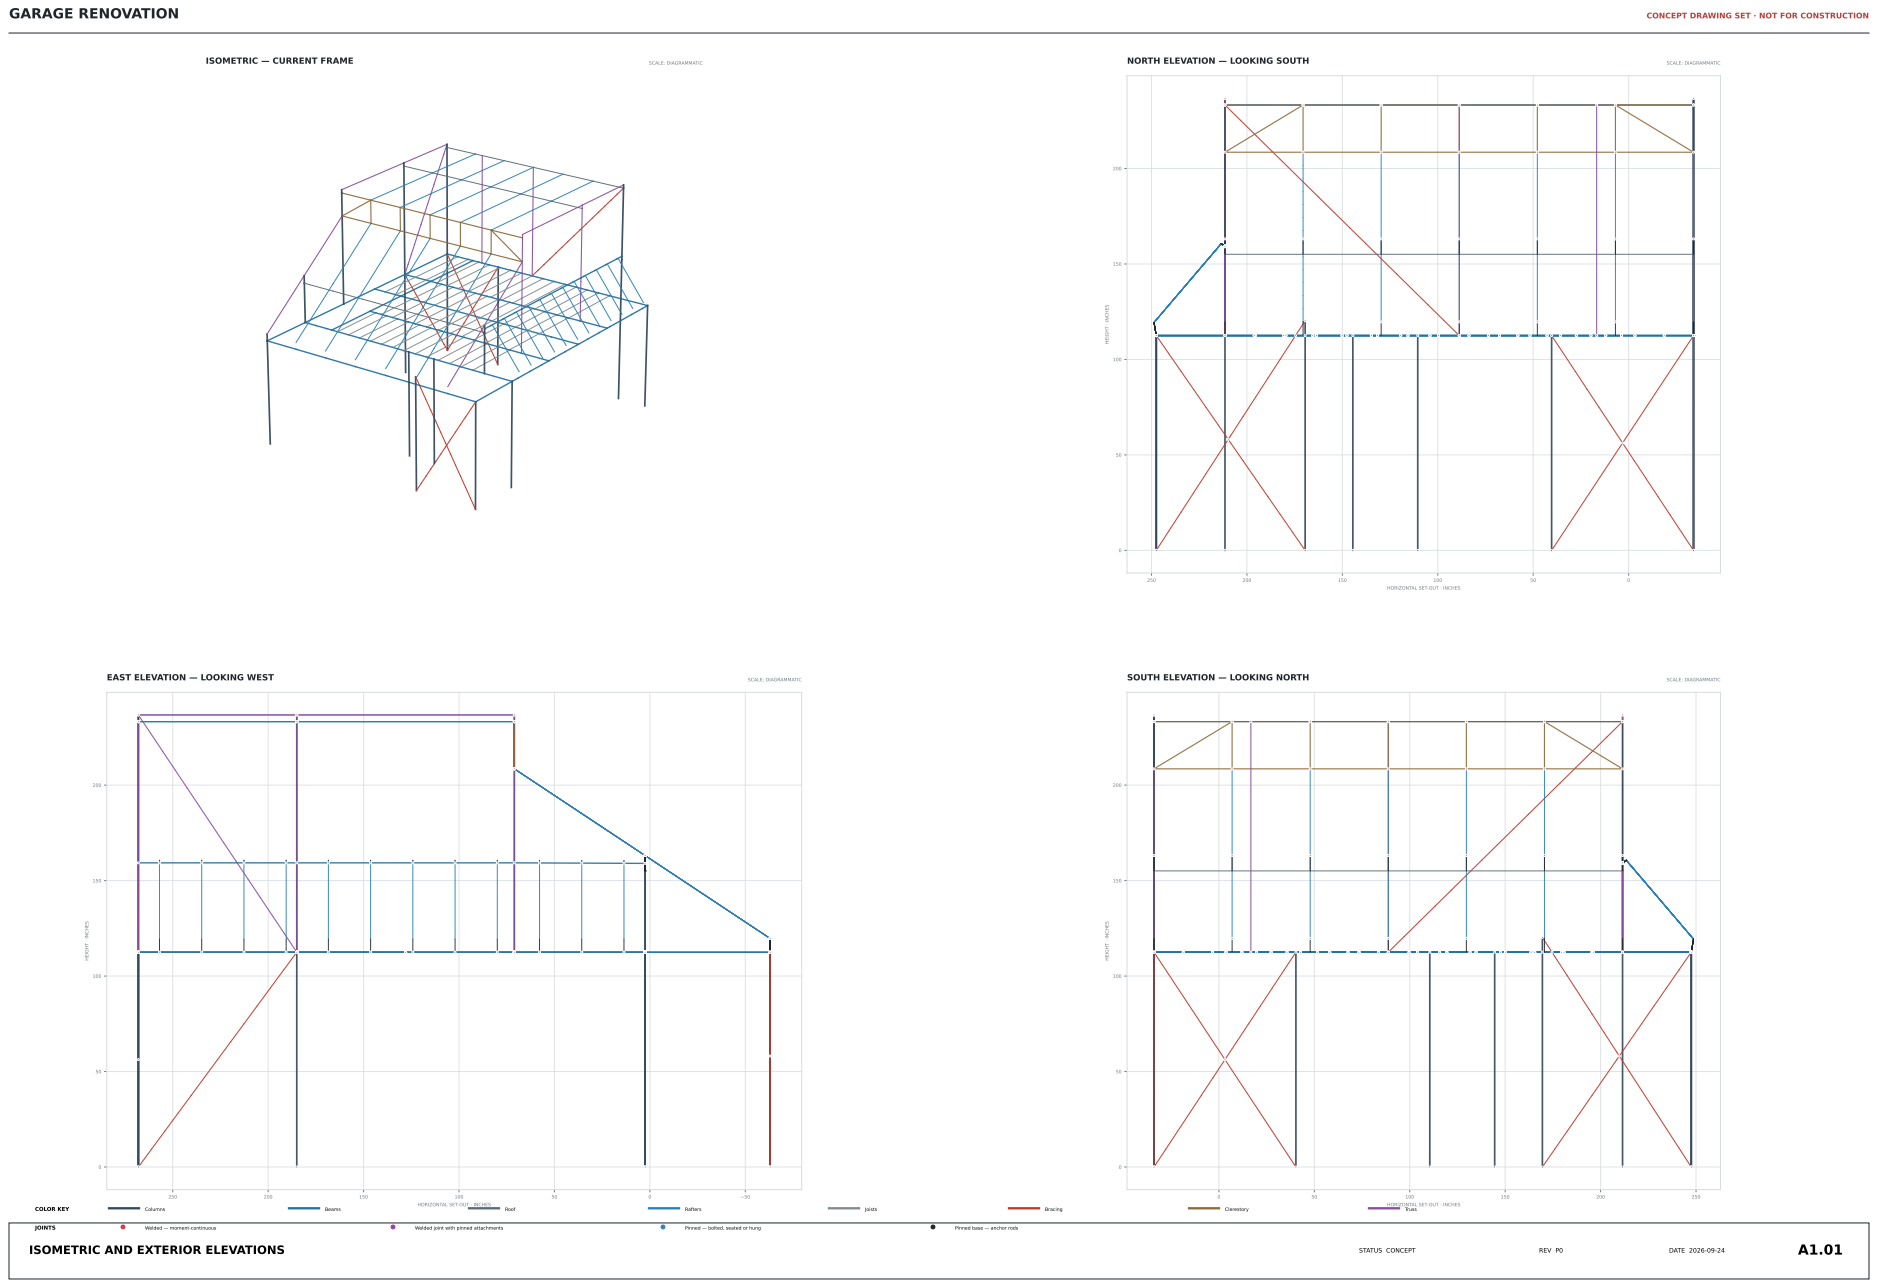
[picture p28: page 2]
HEIGHT · INCHES; EAST ELEVATION — LOOKING WEST; SCALE: DIAGRAMMATIC; SOUTH ELEVATION — LOOKING NORTH; ISOMETRIC AND EXTERIOR ELEVATIONS; STATUS CONCEPT; REV P0; DATE 2026-09-24; COLOR KEY; Columns; Beams; Roof; Rafters; Joists; Bracing; Clerestory; Truss; JOINTS; Welded — moment-continuous; Welded joint with pinned attachments; Pinned — bolted, seated or hung; Pinned base — anchor rods

HORIZONTAL SET-OUT · INCHES

N

# LOFT EQUIPMENT

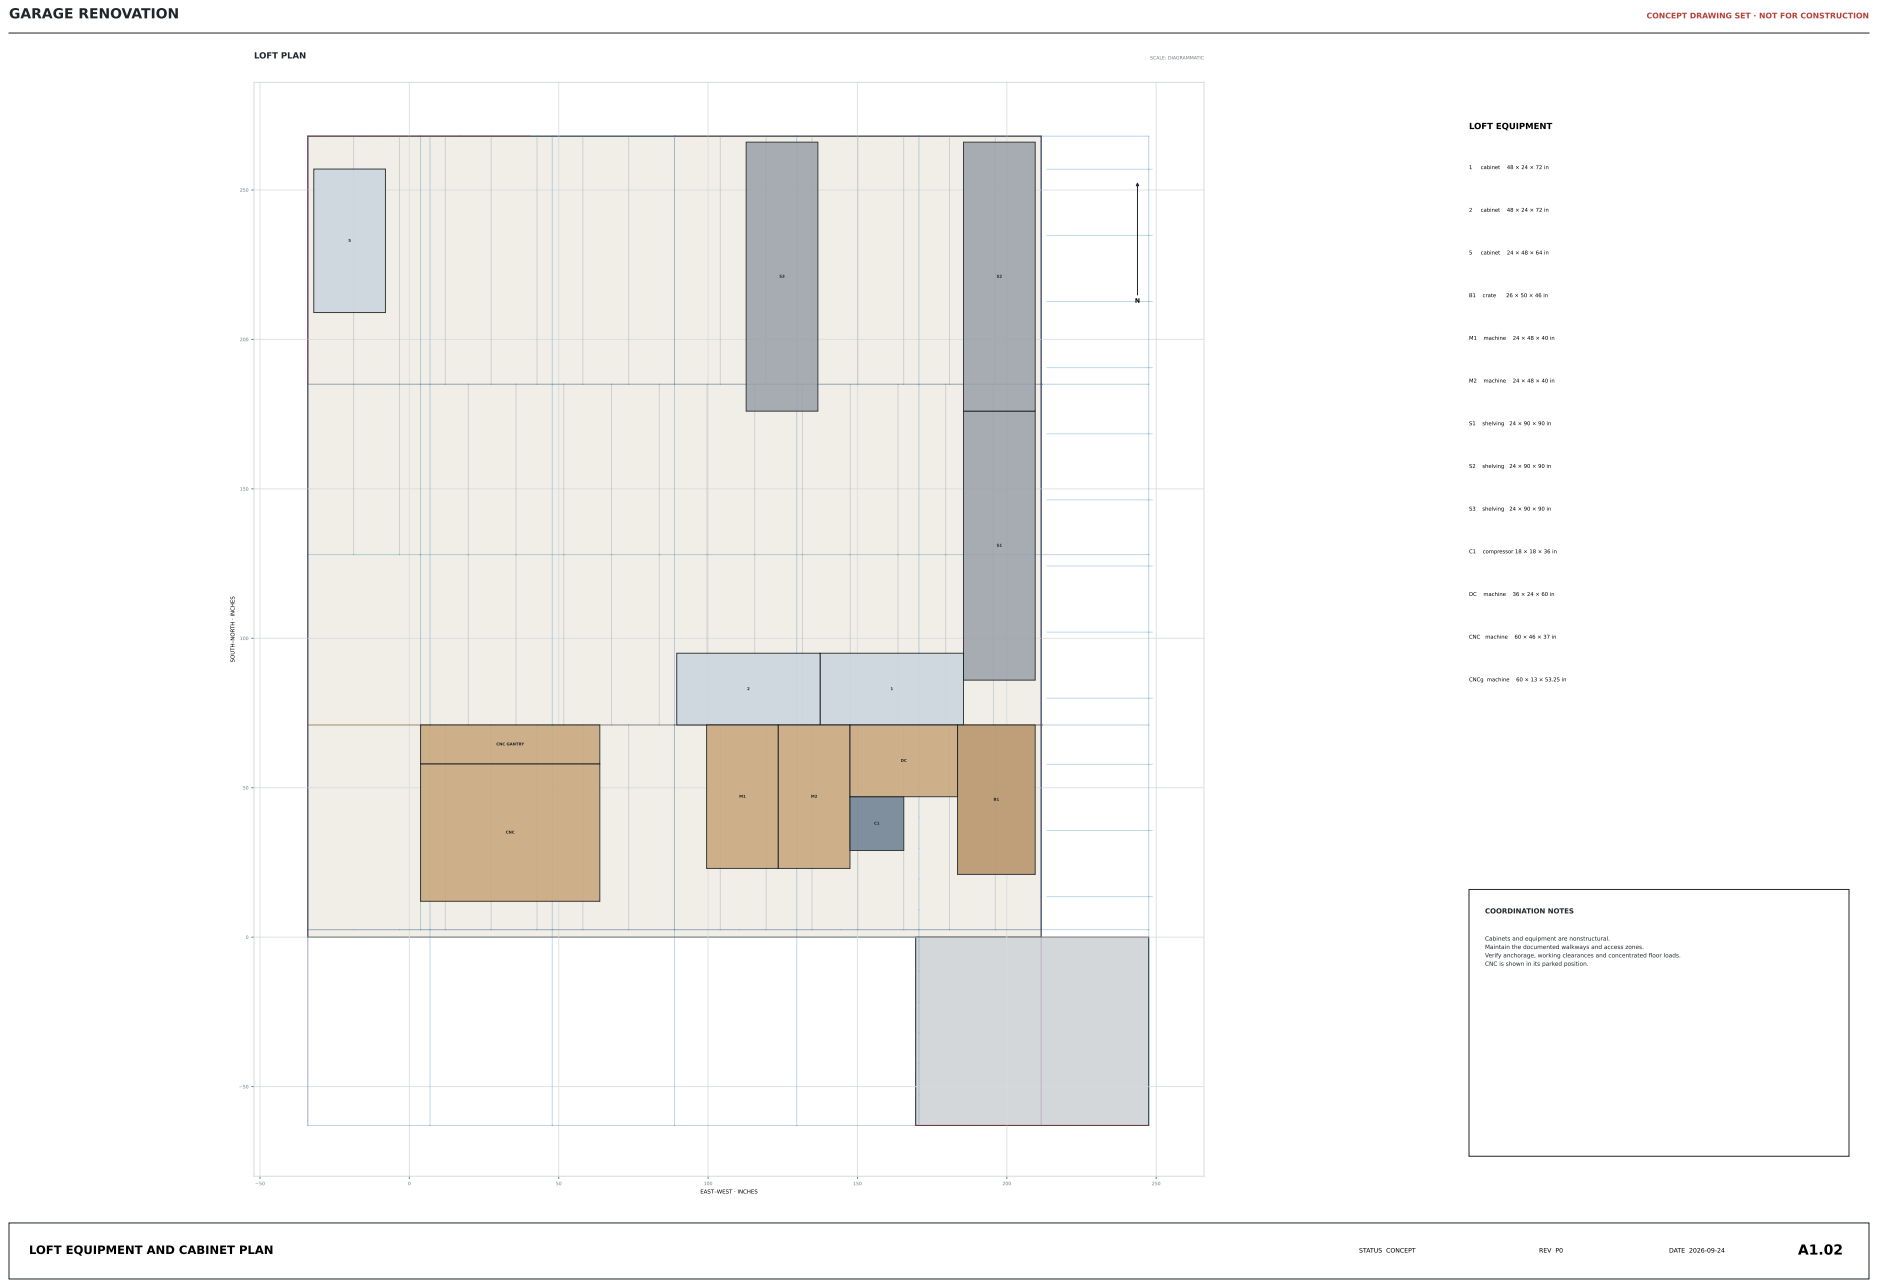
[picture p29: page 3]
LOFT PLAN; SCALE: DIAGRAMMATIC; LOFT EQUIPMENT AND CABINET PLAN; STATUS CONCEPT; REV P0; DATE 2026-09-24; cabinet; crate; machine; shelving 24 × 90 × 90 in; compressor 18 × 18 × 36 in; CNC machine; CNCg machine; COORDINATION NOTES

SOUTH–NORTH · INCHES

CNC GANTRY | | | | DC

CNC | | M1 | | M2 | C1 | B1

Cabinets and equipment are nonstructural.
Maintain the documented walkways and access zones.
Verify anchorage, working clearances and concentrated floor loads.

CNC is shown in its parked position.

EAST–WEST · INCHES

CHEST | TORMACH 440 | | | | | | SIDE | | N

# GROUND-FLOOR ELEMENTS

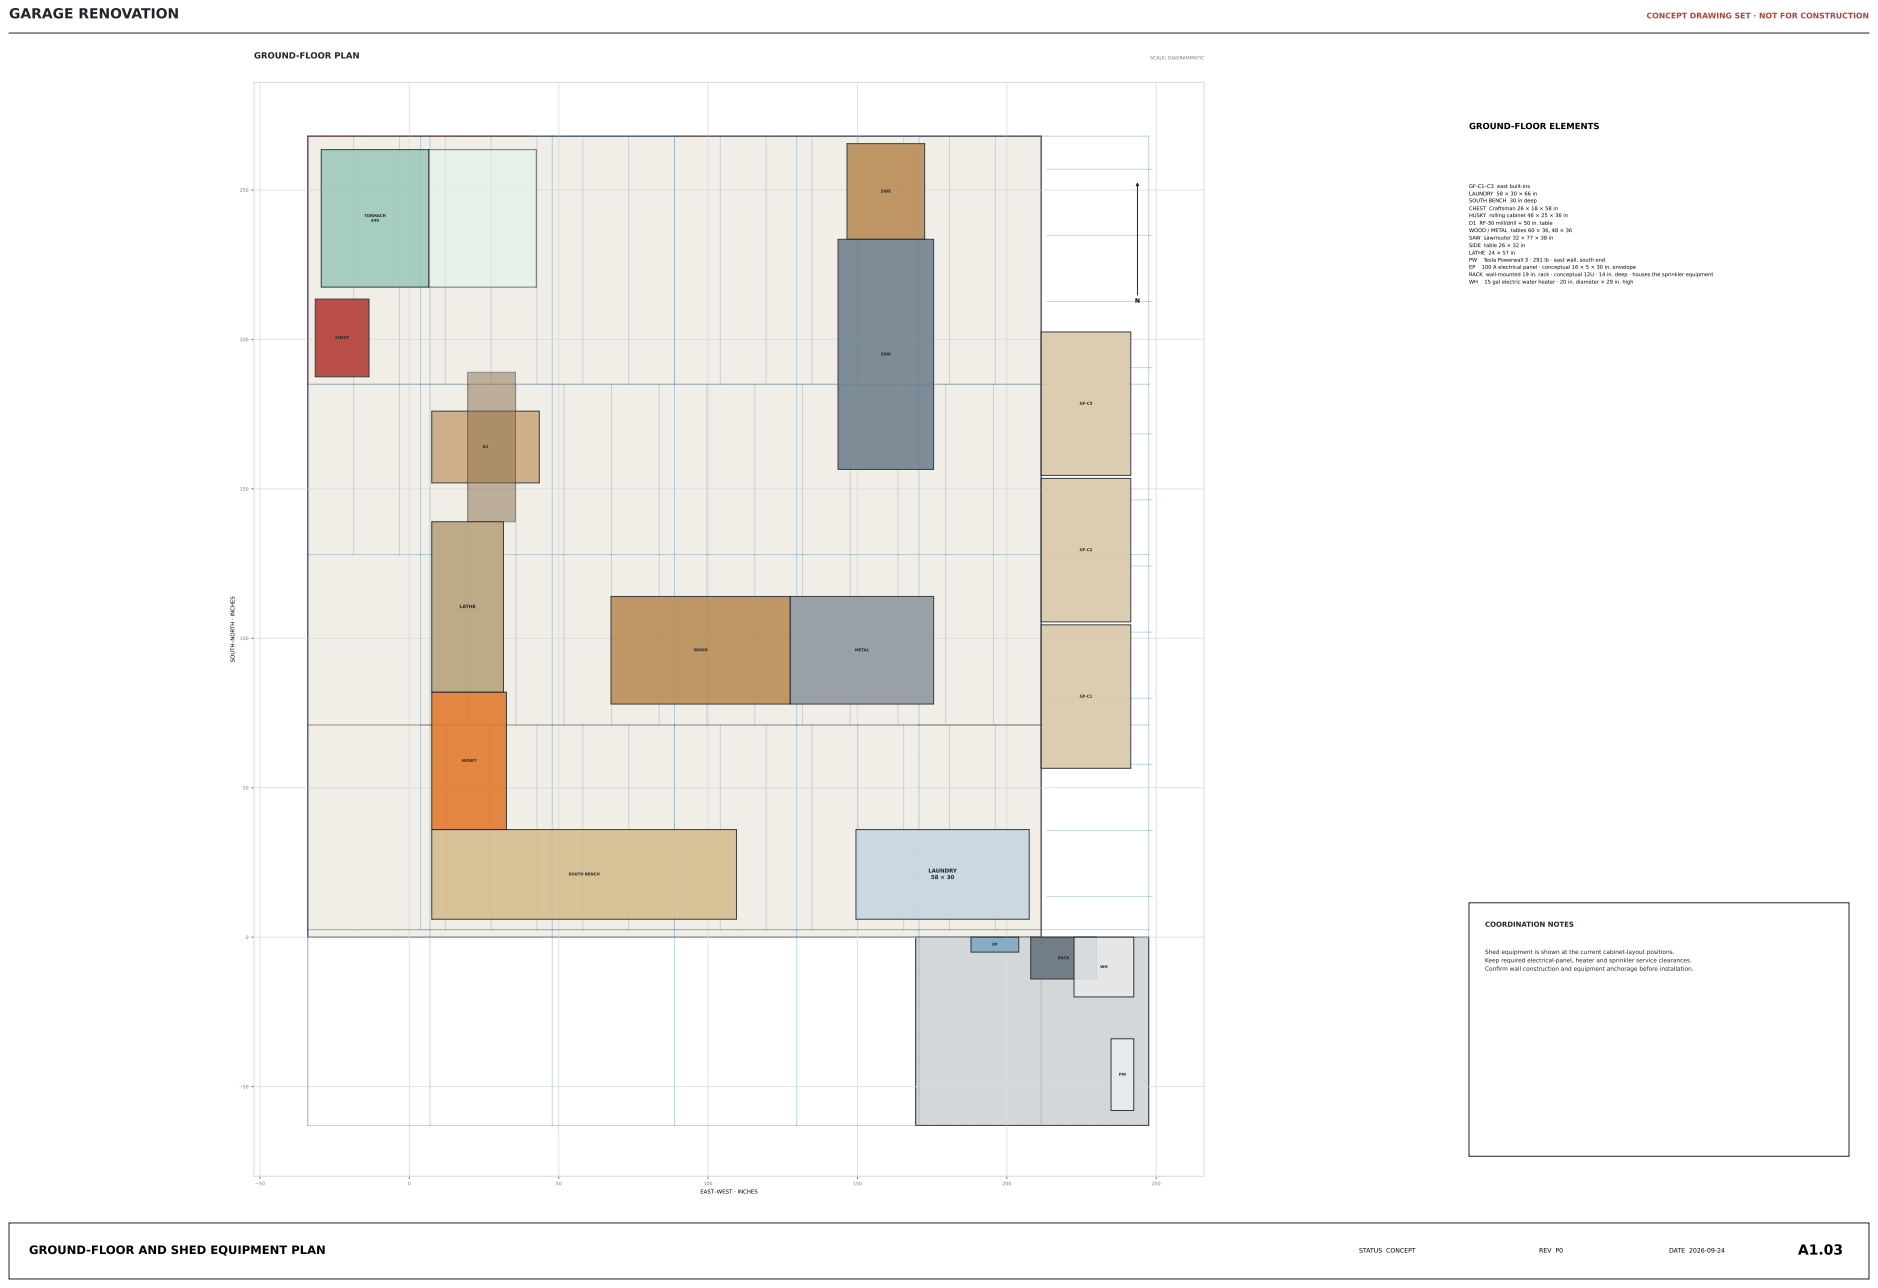
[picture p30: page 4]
GROUND-FLOOR PLAN; SCALE: DIAGRAMMATIC; RACK; GROUND-FLOOR AND SHED EQUIPMENT PLAN; STATUS CONCEPT; REV P0; DATE 2026-09-24; Tesla Powerwall 3 · 291 lb · east wall, south end; 100 A electrical panel · conceptual 16 × 5 × 30 in. envelope; 15 gal electric water heater · 20 in. diameter × 29 in. high; COORDINATION NOTES

GF-C1–C3 east built-ins

LAUNDRY 58 × 30 × 66 in
SOUTH BENCH 30 in deep
CHEST Craftsman 26 × 18 × 58 in
HUSKY rolling cabinet 46 × 25 × 36 in
D1 RF-30 mill/drill + 50 in. table
WOOD / METAL tables 60 × 36, 48 × 36
SAW saw/router 32 × 77 × 38 in
SIDE table 26 × 32 in
LATHE 24 × 57 in
RACK wall-mounted 19 in. rack · conceptual 12U · 14 in. deep · houses the sprinkler equipment

SAW

SOUTH–NORTH · INCHES

LATHE

WOOD | METAL | | | GF-C1

HUSKY

LAUNDRY 58 × 30 SOUTH BENCH

Shed equipment is shown at the current cabinet-layout positions.
Keep required electrical-panel, heater and sprinkler service clearances.
Confirm wall construction and equipment anchorage before installation.

CHEST | TORMACH 440 | | | | | | | | SIDE | | | N
POWER PLAN — CONCEPT ROUTING | SCALE: DIAGRAMMATIC

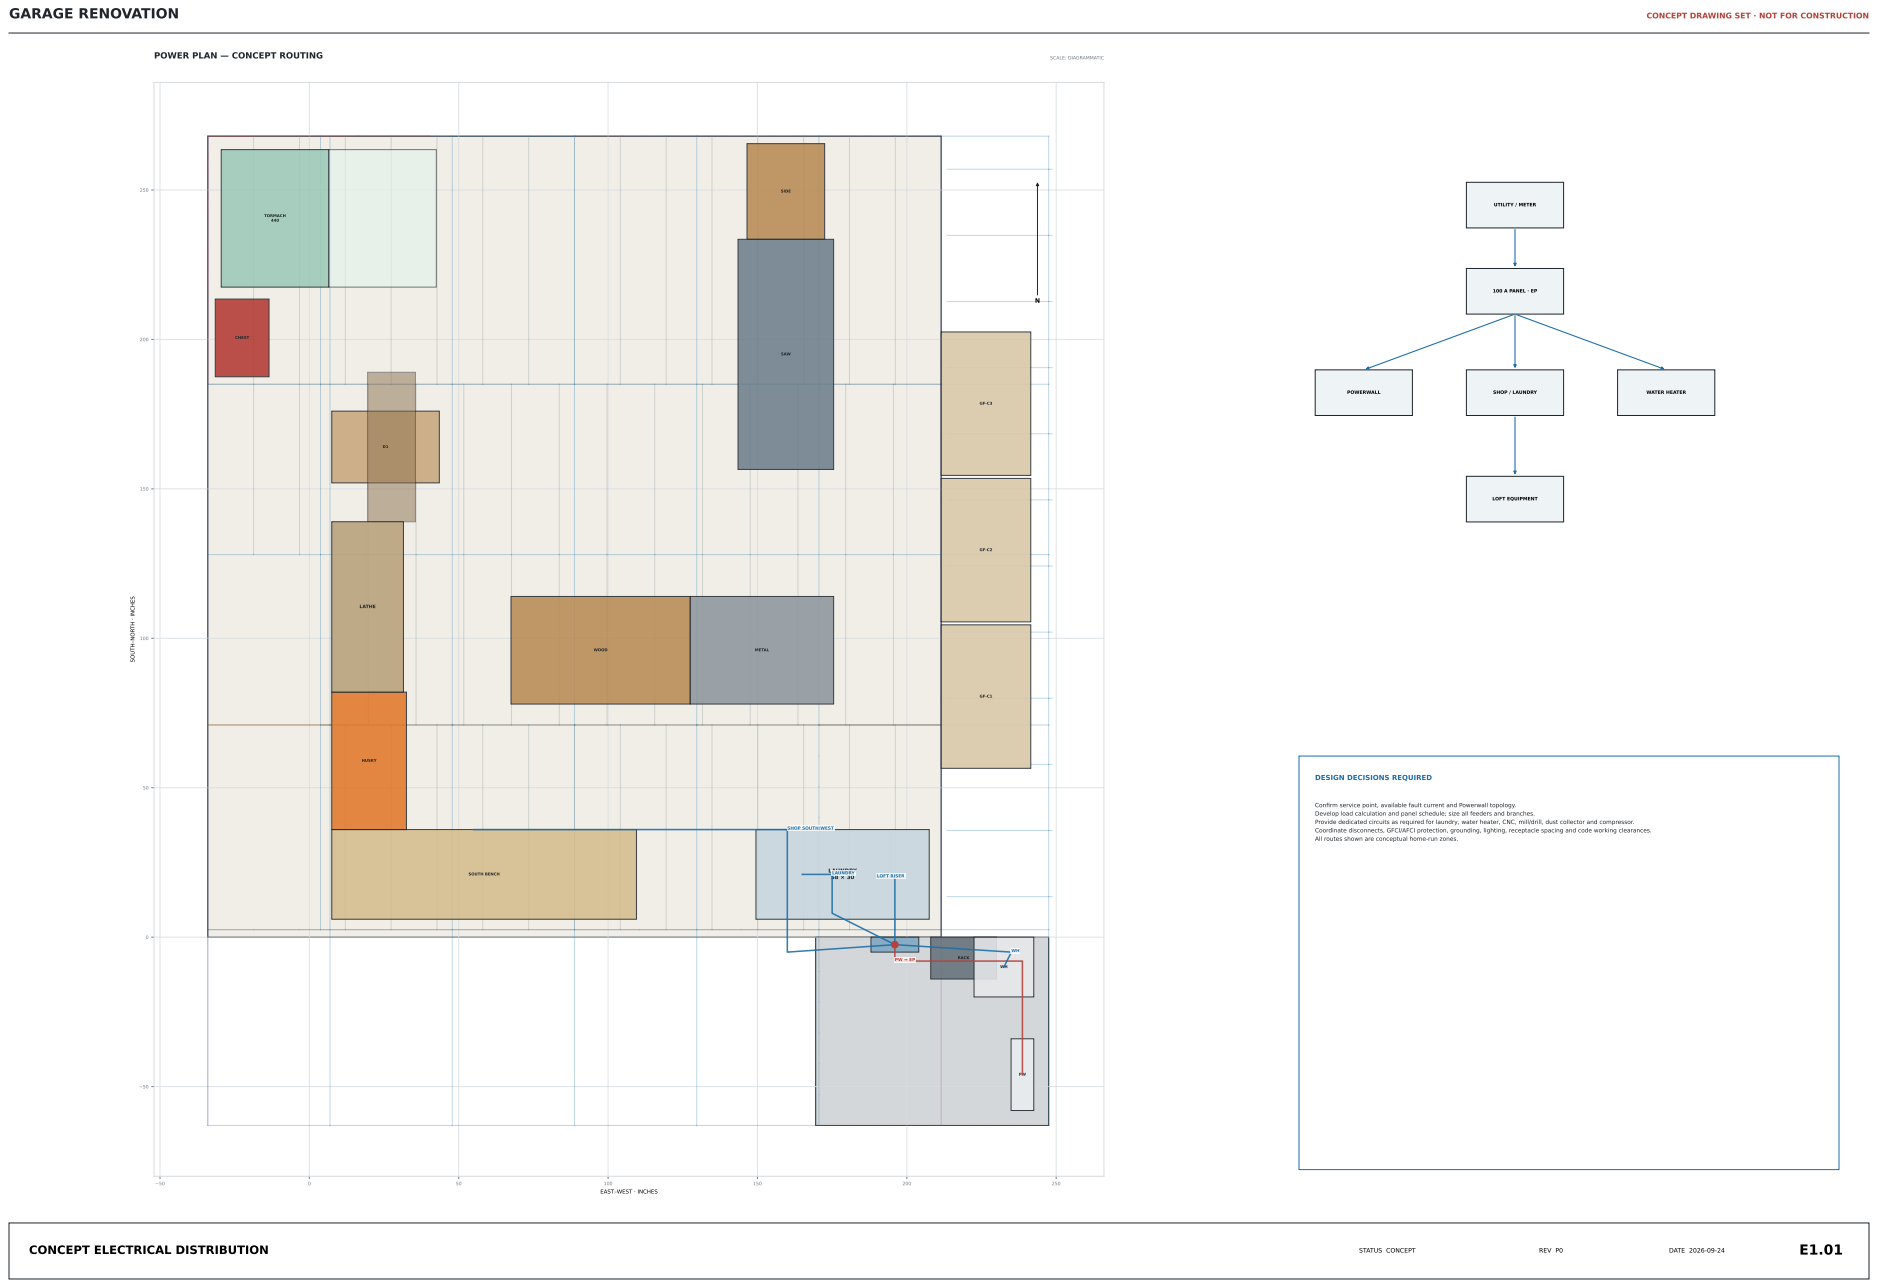
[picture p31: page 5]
RACK; UTILITY / METER; 100 A PANEL · EP; POWERWALL; SHOP / LAUNDRY; WATER HEATER; LOFT EQUIPMENT; CONCEPT ELECTRICAL DISTRIBUTION; STATUS CONCEPT; REV P0; DATE 2026-09-24

SAW

SOUTH–NORTH · INCHES

LATHE

WOOD | | METAL | | | | GF-C1

HUSKY

DESIGN DECISIONS REQUIRED

Confirm service point, available fault current and Powerwall topology.

Develop load calculation and panel schedule; size all feeders and branches.
Provide dedicated circuits as required for laundry, water heater, CNC, mill/drill, dust collector and compressor.
Coordinate disconnects, GFCI/AFCI protection, grounding, lighting, receptacle spacing and code working clearances.
All routes shown are conceptual home-run zones.

BENCH | | SHOP SOUTH/WEST | | LAUNDRY 58 × 30 SOUTH LAUNDRY | LOFT RISER

CHEST | TORMACH 440 | | | | | | SIDE | | N
DATA PLAN — CONCEPT HOME RUNS | SCALE: DIAGRAMMATIC
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

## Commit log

2026-09-22 Reorganize garage project and publish site
    [Garage-Exposed-Steel.FCStd, Garage-Exposed-Steel.blend, Garage-Exposed-Steel.step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]
2026-09-22 Restore pre-demo view and audit moment frames
2026-09-22 Add shed water heater layout
2026-09-25 Move Powerwall to shed southeast corner
2026-09-25 Organize versioned visualization releases
    [load-cases.csv, member-schedule.csv, reactions.csv]
2026-09-25 Join touching members and add connection view
    Audit every member end and crossing against the solid geometry; join
    four places that touched or crossed without a joint (BR-S-2 through the
    B-SO web, S1 top / BR-S-2 head / RS @ 170.58 seat, both X-brace
    crossings). Rerun analysis: max ratio 0.896, drift H/414, passes.
    Add a Connections checkbox to the 3-D viewer with a sphere per joint
    colored welded / mixed / pinned / base, draw offset links and joint dots
    on the elevations, and orient split segments head-to-tail in _ordered.
2026-09-26 Place Tormach PCNC 440 in the NW pop-out
    Option 1 with 2 in. off the W3-W4 and W4-N1 walls, facing east, ATC
    side south, console on the north wall. Added to the cabinet layout in
    the 3-D viewer and to the ground-floor plan sheet; placement study
    figure updated and the ATC-side orientation corrected.
2026-09-26 Add beam-clamp hoist capacity study for loft floor beams
2026-09-26 Record 700 lb maximum lift in hoist clamp study
2026-09-26 Add ground-floor outline plan for machine placement
2026-09-26 Turn D1 to face south with its table; split west bench into chest and Husky
    D1 (RF-30) gets its 50 x 16 x 4 in. table at 36 in., 8 in. back from the
    front. Broadside it hit S3, so it now faces south onto the east walkway run.
    Items can carry an attached part that may overlap only its parent.
    B-W is retired: the west wall north of B-S holds the Craftsman tool chest
    (26 x 18 x 58) and the Husky rolling cabinet (46 x 25 x 36).
2026-09-26 Lay out ground floor: chest in niche, Husky/lathe/D1 on west wall, tables and saw
    D1 moves off the loft to the west wall north of the lathe, facing east,
    its table sweep meeting the lathe. The chest goes in the niche south of
    the Tormach; the Husky takes the chest's old spot and the lathe slides
    down to it. Wood and metal tables meet on the south door centre line 6 ft
    off the south wall; the saw/router and its side table run south from the
    north wall on the door's east jamb. Ground items are checked for overlap.
2026-09-26 Stack rack on sprinkler cabinet; hang Powerwall over water heater
    The rack moves from the shed's east wall onto the north wall, centred on
    top of the sprinkler cabinet (z 78-102). The Powerwall moves from the
    south wall to the east wall above the water heater, north end in the
    corner, top at 78 in. The plan labels stacked items together.
2026-09-26 Fold sprinkler cabinet into the rack; Powerwall to south end of east wall
    The sprinkler equipment goes in the rack, so SPK is removed and the rack
    takes its place on the shed's north wall at z 54-78. The Powerwall moves
    to the south end of the east wall, back at 12 in. off the slab. Plan
    labels a stack only when the upper item is mostly over the lower.
2026-09-26 Add outer walls and roofs views; door jamb post NJ between N1 and N2
    New Outer walls checkbox closes the building in: frame turns white, 2 in.
    light-grey panels sit with their inside face flush with the steel so posts,
    beams and braces stand proud, existing exterior garage walls are drawn in the
    same grey with openings, and each section is hover-labelled by face, storey
    and number (WL1..SU8). The garage door is two leaves NL2/NL3 either side of
    NJ, a non-structural pinned HSS5x2 jamb post midway between N1 and N2 that is
    not in the analysis. A Roofs checkbox adds the black solar slope, an 18 in.
    hipped cap with 4 in. white soffit and fascia, and dark-grey lean-to and shed
    roofs. The cabinet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
2026-09-26 Add BWI stair partition and stairwell windows; regroup viewer controls into columns
    IU1 stands on BWI along the stair opening, B-S to the stair head at B-1A, up
    to the rafter soffit under the solar slope and level with the clerestory sill
    north of it. WU2 and WU3 get a 36 x 36 in. window each, looking in on it.
    The control bar is four columns: hide toggles (existing walls, existing roof,
    new frame, outer walls, roofs; outer walls and roofs hidden by default),
    layers (pre-demo, cabinet layout, connections), walkthrough and fixed view,
    and the three colour-mode buttons, now HTML rather than Plotly updatemenus.
    Hint text removed. The frame turns white whenever the outer walls show,
    whatever co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
2026-09-26 Column headers and colour radios; inner-walls toggle; glaze WU2
    Control columns are headed View, Features, Walkthrough and Color. Colour
    modes are radio buttons with a fourth, White, which is selected when the
    outer walls are shown and undone when they are hidden. The BWI partition is
    on its own Hide inner walls toggle and drawn in a warmer colour, so it can
    be seen with the outer walls hidden. WU2 is glazed over the whole bay.
2026-09-27 Glaze the shed corner as a skylight on hip beam SK1
    The flat sheet east of the solar slope and south of the lean-to becomes two
    glass panes either side of SK1, a conceptual HSS3X3 hip beam from the apex
    over S3 (where the lean-to meets the solar slope) down to the E-S2 corner.
    SK-W carries the solar plane on east to BE; SK-E falls east like the lean-to.
    SK1 is drawn with the frame but is not in the analysis.
2026-09-27 Backyard walkthrough: current building in the reviewed backyard, walkable map
    New render package 20260926.01-backyard-walkthrough. lean_to_report.py now
    exports the viewer's outer-walls meshes (white frame, walls, doors, glazing,
    roofs, BWI partition and mural, layout furniture) to building-mesh.json; a
    Blender build on buzzkill drops them into backyard-existing.blend, removes the
    old garage walls and roof, removes or clips base objects inside the new
    footprint, exports a web GLB and raycasts a 0.1 m walk map (blocked where
    anything stands between 18 in. and head height).
    index.html is a three.js viewer: orbit, plus a walkthrough with the frame
    viewer's keys that keeps a 0.44 m body on walk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
2026-09-27 Walkthrough: vendor three.js, show load progress and errors
    The page hung on 'Loading' with no message whenever the CDN modules or the
    file:// protocol blocked it. three.js r147 is now vendored beside the page,
    the GLB load shows a percentage, and a failed start, a file:// open or a
    20 s stall is reported on the page.
2026-09-27 Walkthrough: building walls take the house's stucco
    The grey wall panels and the existing walls drawn in that grey now use the
    house's PHOTO / house_stucco material, with planar UVs at the house's texel
    density, so they are the same grey as the house. Beams stay white; doors,
    glass and the BWI partition keep their own colours.
2026-09-27 Walkthrough: drop the shelter's timber header and back screen
    Clipping them to the new footprint left them on wrong lines and angles. The
    green shelter roof and its grey electrical pillar stay.
2026-09-27 Track site photos, final renders and report figures
    These were caught by the blanket *.png/*.jpg ignore and existed only on
    one disk: the original backyard photographs, the Blender render PNGs and
    texture sources, and the controlled report's figures (which the report
    pages and document manifest link). Previews, test images, GLB copies and
    study figures stay ignored.
2026-09-27 Patio plan: pillar tie points T1/T2 and cable runs
2026-09-27 Patio awning: fabric form-find and three-way cable junction study
2026-09-29 Patio awning: parallel tarp cables from the roof edge to a fence cable
2026-10-05 Document Nezha-to-Qwiic adapter requirements and verified Buzzkill EDA setup
    [parts.csv, wiring.csv]
2026-10-05 Design and validate single-sided Nezha to Qwiic adapter revision A
    [nezha-qwiic-B_Cu.gbl, nezha-qwiic-B_Mask.gbs, nezha-qwiic-Edge_Cuts.gm1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]
2026-10-05 Add checked Carvera ATC program for one adapter on 1.4 mm PCB stock
    [nezha-qwiic-B_Cu.gbl, nezha-qwiic-B_Mask.gbs, nezha-qwiic-Edge_Cuts.gm1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]
2026-10-05 Reduce Carvera through-cut allowance to 0.05 mm and verify hole floors
2026-10-05 Record small-quantity PCB suppliers and flag unavailable jack
    [parts.csv, suppliers.csv]
2026-10-06 Redesign Nezha Qwiic adapter for stocked Amphenol jack
    [nezha-qwiic-B_Cu.gbl, nezha-qwiic-B_Mask.gbs, nezha-qwiic-Edge_Cuts.gm1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]
2026-10-06 Move Nezha Qwiic PCB project out to standalone CAM directory
    [nezha-qwiic-B_Cu.gbl, nezha-qwiic-B_Mask.gbs, nezha-qwiic-Edge_Cuts.gm1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]
